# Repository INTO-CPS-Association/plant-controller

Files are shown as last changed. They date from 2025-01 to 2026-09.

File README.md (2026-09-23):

# Plant Controllers

This is a project to develop edge controller and digital twin for plants.
The long-term goal is to realise the vision illustrated in the figure.

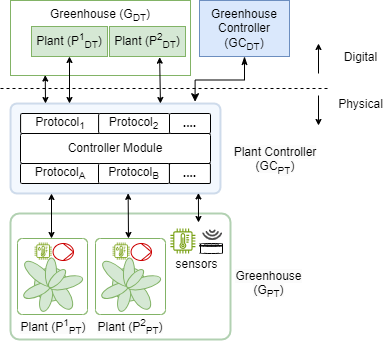
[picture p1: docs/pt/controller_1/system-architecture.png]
system architecture


The current version allows for digital twin development for specifically the
connected plants.

Documentation for current and previous versions of the Plant Controller can be
found online [Here](https://into-cps-association.github.io/plant-controller/).

## :rocket: Install and Use

To get up an running follow the [Quick Start Guide](https://into-cps-association.github.io/plant-controller/pt/controller_3/setup/quick_start/).

## :hammer_and_wrench: Developers

Detailed documentation of the system can be found [here](https://into-cps-association.github.io/plant-controller/pt/controller_3/documentation/).

To build the documentation locally install python and the requirements in [`requirements-docs.txt`](./requirements-docs.txt), then run
```bash
python ./scripts/gen_api_pages.py
zensical serve
```
The docummentation should then be available at [http://localhost:8000](http://localhost:8000).

Your feedback is valuable in improving the project. Please open
[an issue](https://github.com/INTO-CPS-Association/plant-controller/issues/new)
if you find problems or have suggestions for potential improvements. Thanks.

## :balance_scale: License

This software is owned by
[The INTO-CPS Association](https://into-cps.org/)
and is available under [the INTO-CPS License](./LICENSE.md).

Please see [third-party](docs/third-party.md) for details of
the third-party software included in the DTaaS.

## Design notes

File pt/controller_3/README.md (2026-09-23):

# Plant Controller Version 3
This version of the Plant Controller allows sensor conenctions with both I2C 
and MODBUS RTU.

The [sensors](./plant_controller/sensors) and [pump_schedules](./plant_controller/pump_schedules)
modules are extendable, allowing for additional sensor types and
configurations, and customziable watering schedules.

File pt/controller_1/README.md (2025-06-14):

# Plant Controller - I

Please see the [SCHEMATICS](SCHEMATICS.md) to get an overview of
the electrical and physical layout of the plant controller system.

## Initial Setup

Enable I2C interface in RPi OS configuration.

```bash
sudo raspi-config nonint do_i2c 0
```

You can check the list of I2C devices connected to a RPi using

```bash
sudo apt-get install i2c-tools
i2cdetect -y 1
```

## Configuration

The controller is configured using the `config.yaml` file. A template is provided in config/config.yaml.template.
You can copy it to `config/config.yaml` and edit it according to your setup.

The configuration file contains the following sections:

- Services: containing influxdb and STOMP services.
- Plant: containing sensors and actuators.

### Configuration Details

The `config.yaml.template` file contains the following structure:

```yaml
services:
  internal:
    influxdb:               # InfluxDB configuration for storing sensor data
      bucket: "controller-1"
      token: "xxxx"         # Your InfluxDB access token
      url: "https://influxdb.example.com"
      org: "plants"
  external:
    stomp:                  # STOMP message broker configuration
      url: "localhost.com"
      user: "admin"
      pass: "admin"
      port: "1234"
      topics:               # Map of STOMP topics to pump IDs
          "actuator.1.water": pump_1
          "actuator.2.water": pump_2
          "actuator.3.water": pump_3

plant:
  sensors:
    seesaw:                 # Adafruit Seesaw soil moisture sensors
      moisture_0:           # First moisture sensor
        port: 0             # TCA9548A multiplexer port
        addr: 0x36          # I2C address
      moisture_1:           # Second moisture sensor
        port: 1
        addr: 0x36
      moisture_2:           # Third moisture sensor
        port: 2
        addr: 0x36
    sht45:                  # Temperature & humidity sensor
      port: 6               # TCA9548A multiplexer port
      mode: NOHEAT_HIGHPRECISION  # Sensor operation mode
    as7341:                 # Light spectrum sensor
      port: 7               # TCA9548A multiplexer port
    sampling_period: 60     # Sensor reading interval in seconds
    
  actuators:
    pump_1:                 # First water pump
      relay: one            # Relay name on the Automation HAT
      schedule: "10:15"     # Daily watering time (HH:MM)
      on_duration: 15       #pump turn on time
    pump_2:                 # Second water pump
      relay: two
      schedule: "14:30"
      on_duration: 6        #pump turn on time
    pump_3:                 # Third water pump
      relay: three
      schedule: "10:15"
      on_duration: 10       #pump turn on time
```

### Configuration Sections

1. **Services**
   - **internal/influxdb**: Configuration for InfluxDB time series database.
   - **external/stomp**: Configuration for STOMP message broker to receive remote commands.

2. **Plant**
   - **sensors**: Configuration for all connected sensors.
     - **seesaw**: Soil moisture sensors.
     - **sht45**: Temperature and humidity sensor.
     - **as7341**: Light spectrum sensor.
     - **sampling_period**: How often sensors are read (in seconds).
   - **actuators**: Configuration for water pumps.
     - Each pump has a relay name and watering schedule.

### Note

- The I2C addresses must match your physical hardware configuration.
- Valid relay names are "one", "two", and "three" as defined by the Automation HAT.
- Relay names must match the actual relay that the pump is connected to.
- A sensor's port corresponds to the TCA9548A multiplexer port it is connected to.

## Run

Please execute the following commands to start the controller.

```sh
pip install -r requirements.txt
python controller-1.py
```

## Note

1. Accessing the I2C bus in parallel in two programs leads to errors.
   Use multiplexer for such a purpose.
1. The I2C bus communication may not be very robust.
   The sensors produce errors sometimes in an hour and sometimes in
   a day. So python exception checking is required.

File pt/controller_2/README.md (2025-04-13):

# Greenhouse - III

## Physical Setup

This greehouse uses SenseHAT for temperature, humidity and light
readings.
It uses [Waveshare 3-Channel Relay HAT](WAVESHARE_RELAY.md)
for controlling motors.

The physical twin schematic for the green house is

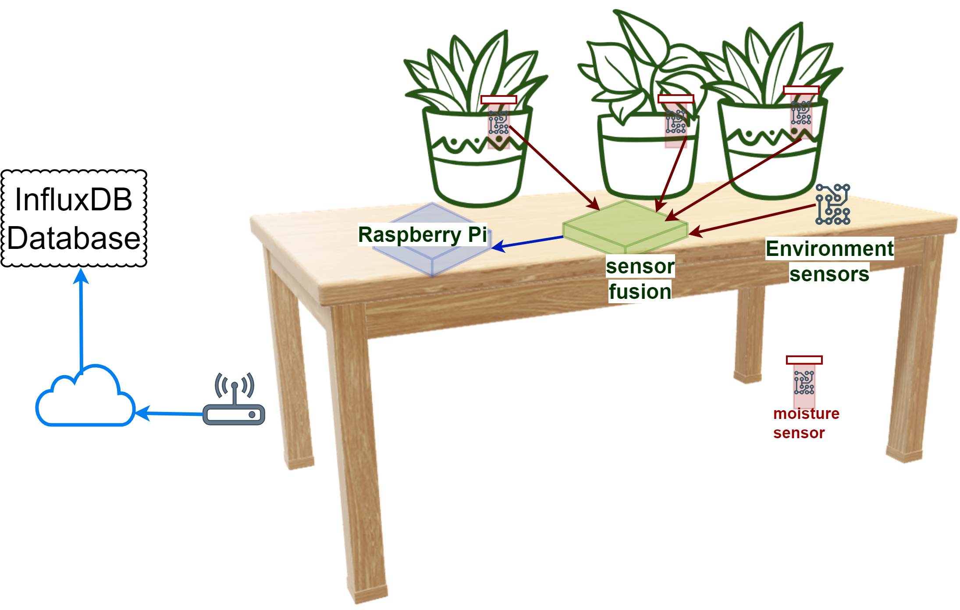
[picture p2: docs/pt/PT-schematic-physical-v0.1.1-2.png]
physical schematic


Only two plants are being used right now.

## Hardware Connections

The matching electrical schematic is:

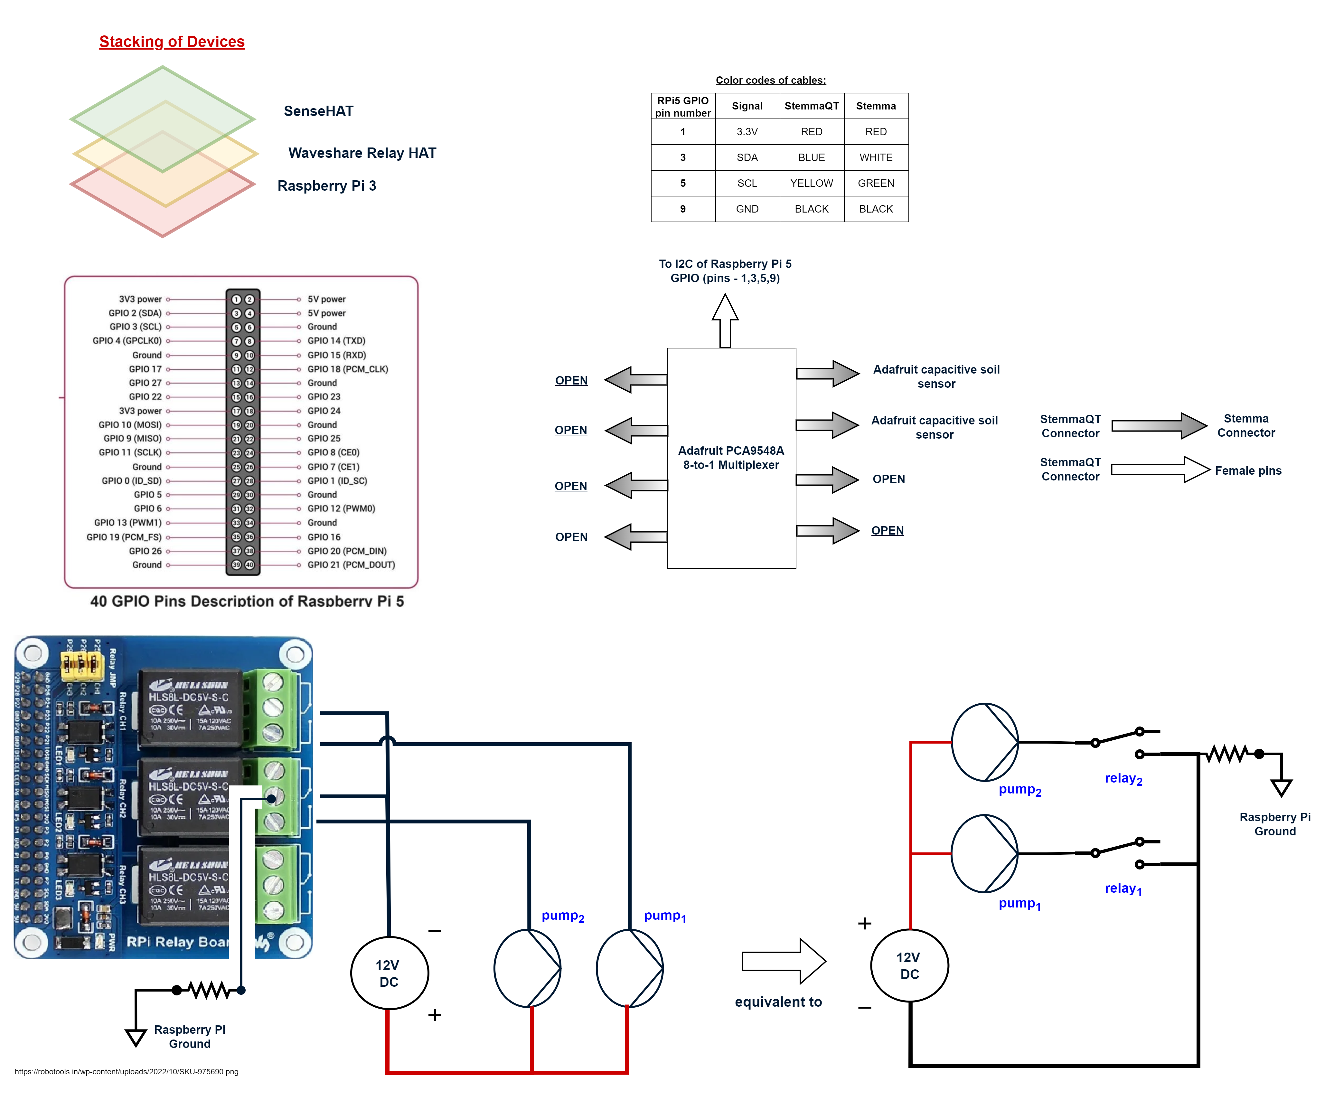
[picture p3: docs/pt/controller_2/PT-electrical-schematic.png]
electrical


The approach taken here is to use Raspberry Pi senseHAT for environment
readings and use Adafruit stemma soil sensors for moisture readings.

All the sensors selected use [I2C communication protocol](https://www.nxp.com/docs/en/user-guide/UM10204.pdf). Even the senseHAT uses I2C communication protocol underneath.
However, I2C is a bus protocol. So the Adafruit
[PCA9548A multiplexer](https://learn.adafruit.com/adafruit-pca9548-8-channel-stemma-qt-qwiic-i2c-multiplexer)
setup is used to connect
two soil moisture sensors to Raspberry Pi.

It is useful to be familiar with the RPi [GPIO pins](https://pinout.xyz/).
The I2C pins of RPi are.

| Pin No | Pin Name | Suggested Wire Color |
|:---|:---|:---|
| 1 | 3.3 | RED |
| 2 or 4 | 5V | RED |
| 3 | SDA | BLUE |
| 5 | SCL | YELLOW |
| 6 or 9 | GND | BLACK |

The multiplexer can work with both 3.3V and 5V.
The Multiplexer is available at **I2C address x70** and it has 8 ports.

Enable i2c interface in RPi OS configuration.

```bash
sudo raspi-config nonint do_i2c 0
```

You can check the list of I2C devices connected to a RPi using

```bash
sudo apt-get install i2c-tools
i2cdetect -y 1
```

The two Adafruit soil capacitive sensors are connected to the multiplexer.

Sometimes the soil moisture sensors seem faulty, but they work if
they are cleaned and reconnected.

The I2C addresses of the sensors used are:

| I2C Address | Device | Purpose | Multiplexer Ports | Notes |
|:---|:---|:---|:---|:---|
| 0x36 to 0x39 (with 0x36 as default) | capacitive soil sensor | measure soil moisture | ports 6 to 7 | the default addresses have not been modified |
| 0x5F | senseHAT (HTS221) | temperature and humidity sensor | | |
| 0x29 | senseHAT (TCS34725) | light sensor | | |
| 0x1C | senseHAT (LSM9DS1) | accelerometer | | |
| 0x6A | senseHAT (LSM9DS1) | accelerometer | | |
| 0x5C | senseHAT (LPS25H) | pressure sensor | | |
| 0x70 to 0x77 (with x070 as default) | PCA9548 | 8-TO-1 multiplexer | directly connected to I2C port of Raspberry Pi 3 | the default address has not been modified |

**missing I2C device:** x46 for senseHAT (LED2472G)

See [I2C address directory](https://learn.adafruit.com/i2c-addresses/the-list)

### Note

1. Accessing the I2C bus in parallel in two programs leads to errors. Use multiplexer for such a purpose.
1. The I2C bus communication may not be very robust.
   The sensors produce errors sometimes in an hour and sometimes in a day. So python exception checking is required.

## Run Controller

The programs store readings in InfluxDB database.

```bash
sudo apt-get install sense-hat
python -m venv .venv-sensehat
#update the venv config to include system-wide-packages, see
#https://stackoverflow.com/questions/55600132/installing-local-packages-with-python-virtualenv-system-site-packages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
#in file vi .venv-sensehat/pyvenv.cfg
# include-system-site-packages = true
source .venv-sensehat/bin/activate
pip install influxdb_client
python sensehat.py
```

In another terminal, run controller script  for collecting
moisture readings and controlling the motors.
The moisture readings and motor status are stored in InfluxDB database.

```bash
python -m venv .venv-controller
source .venv-controller/bin/activate
pip install -r requirements.controller.txt
python controller-2.py
```

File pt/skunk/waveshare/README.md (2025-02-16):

# Relays for Greenhouses

The GPIO pin layout has changed in
[RPi 5](https://www.sunfounder.com/blogs/news/comprehensive-guide-to-the-pin-diagram-of-raspberry-pi-5-understanding-gpio-pins-and-their-functions).
Only
[gpiozero](https://gpiozero.readthedocs.io/en/stable/recipes.html) package.
works correctly with RPi 5.

## Waveshare 3-Relay HAT

The GPIO pins for the three-relays are:

* channel_1 = GPIO26
* channel_2 = GPIO20
* channel_3 = GPIO21

Remember, the channels to the relays are active low which means

* ON - turns off the output
* OFF - turns on the output

The board works correctly but the software is outdated.
The [provided software](https://www.waveshare.com/wiki/RPi_Relay_Board)
only works upto RPi 4.
This outdated software uses
[gpiod library](https://www.acmesystems.it/libgpiod)
which doesn't work for RPi 5.

However, we can use python gpiozero pip package to use the board

Install gpiozero at the system level (don't use venv).
$sudo apt install python3-gpiozero
This installs gpiozero==2.0.1 in the system site packages

However, this
package seems to work in venv as well. Check it.

### TODO

At the moment LEDs are being used to control the channels but
LEDs draw a lot of current. Is there a low-power way to
activate the channels?

## References

* [RPi 5 pinout guide](https://www.twicea.com/blog/learn-raspberry-pi-5-pinout-in-this-in-depth-comprehensive-guide)

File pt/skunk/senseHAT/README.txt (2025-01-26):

Steps to install SenseHAT

Add at the end of /boot/firmware/config.txt

#dtoverlay=w1-gpio
dtoverlay=rpi-sense
dtparam=i2c1_baudrate=400000

-------
Installation notes:
---
sense-hat installation issues:
sudo apt install -y python3-sense-hat (works but not "pip install sense-hat" inside virt env)
If installed in virt env, it gives RTIMU moduleerror in python code

Run all senseHAT code outside python virt env.

Plotting
---

Plotting is slow because all the axis is being redrawn frequently.
Instead only update y-axis data.

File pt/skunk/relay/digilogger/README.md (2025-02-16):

# Relays for Greenhouses

The GPIO pin layout has changed in
[RPi 5](https://www.sunfounder.com/blogs/news/comprehensive-guide-to-the-pin-diagram-of-raspberry-pi-5-understanding-gpio-pins-and-their-functions).
Only
[gpiozero](https://gpiozero.readthedocs.io/en/stable/recipes.html) package.
works correctly with RPi 5.

## Digitlogger IoT Relay

This works really well without any static leakage problems, but has
only one effective relay. For the controlling the relay, we are using
one control signal. The control signal is connected to RPi 5 as follows.

* Pin-43: ground
* pin-36: control signal to IoT Relay

One channel can control all the motors.
It takes more current to drive all channels.

### TODO

At the moment LEDs are being used to control the channels but
LEDs draw a lot of current. Is there a low-power way to
activate the channels?

## References

* [RPi 5 pinout guide](https://www.twicea.com/blog/learn-raspberry-pi-5-pinout-in-this-in-depth-comprehensive-guide)

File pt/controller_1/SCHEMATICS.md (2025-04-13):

# Plant Controller - I

The physical twin schematic for the plant controller and plants is

physical schematic

Only three plants are being used right now.

The matching electrical schematic is:

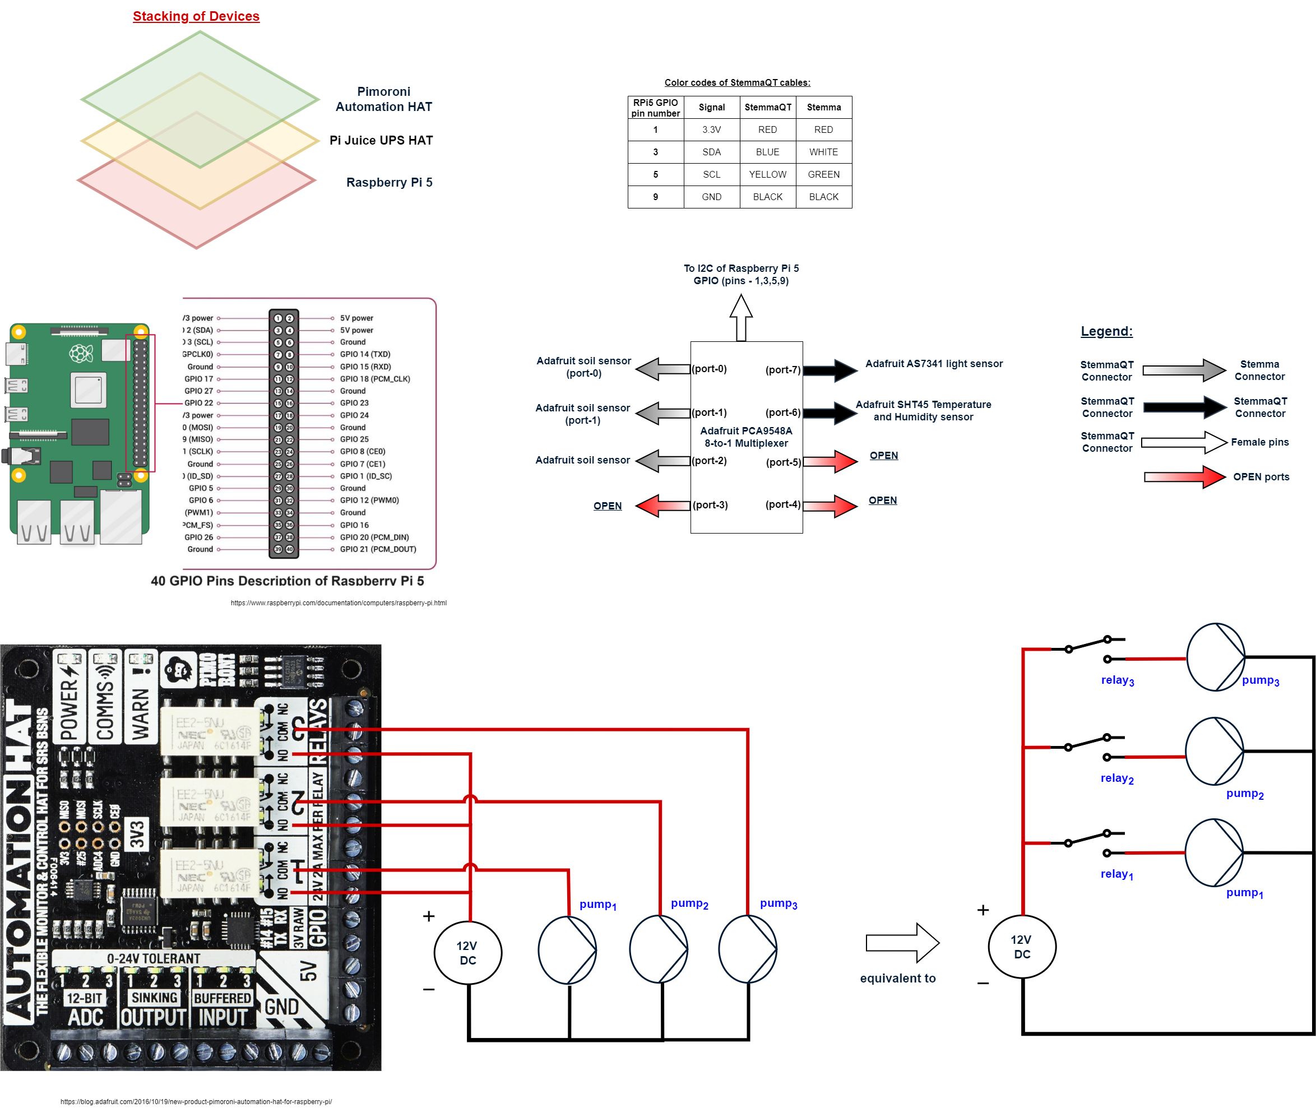
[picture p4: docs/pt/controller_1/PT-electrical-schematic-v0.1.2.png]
electrical


The approach taken here is to use one good sensor for
each physical variable measurement.
All the sensors selected use
[I2C communication protocol](https://www.nxp.com/docs/en/user-guide/UM10204.pdf).

There is only one I2C port on GPIO of Raspberry Pi 5. An Adafruit
[PCA9548A multiplexer](https://learn.adafruit.com/adafruit-pca9548-8-channel-stemma-qt-qwiic-i2c-multiplexer)
setup is used to connect multiple I2C sensors to
the Raspberry Pi (RPi) 5 / 3 Model B+.

It is useful to be familiar with the RPi [GPIO pins](https://pinout.xyz/).
The I2C pins of Raspberry Pi are.

| Pin No | Pin Name | Suggested Wire Color |
| :----- | :--- | :--- |
| 1 | 3.3 | RED |
| 2 or 4 | 5V | RED |
| 3 | SDA | BLUE |
| 5 | SCL | YELLOW |
| 6 or 9 | GND | BLACK |

The multiplexer can work with both 3.3V and 5V.
The Multiplexer is available at **I2C address x70** and it has 8 ports.

The three Adafruit soil capacitive sensors, temperature and humidity
sensor (Adafruit SHT45) and light sensor (Adafruit AS7341) are connected
to the multiplexer.

:warning: Sometimes the soil moisture sensors seem faulty, but
they work if they are cleaned and reconnected.

The I2C addresses of the sensors used are:

| I2C Address | Device | Purpose | Multiplexer Ports | Notes |
|:---|:---|:---|:---|:---|
| 0x36 to 0x39 (with 0x36 as default) | capacitive soil sensor | measure soil moisture | ports 0 to 2 | the default addresses have not been modified |
| 0x44 | SHT45 | temperature and humidity sensor | 6 | |
| 0x39 | AS7341 | 6-channel 16-bit light sensor | 7 | this measures light in seven wavelengths |
| 0x70 to 0x77 (with x070 as default) | PCA9548 | 8-TO-1 multiplexer | directly connected to I2C port of Raspberry Pi | the default address has not been modified |

See [I2C address directory](https://learn.adafruit.com/i2c-addresses/the-list)

 The sensors are connected to Adafruit
PCA9548A (8-ch multiplexer) as follows:

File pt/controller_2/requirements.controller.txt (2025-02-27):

Adafruit-Blinka==8.54.0
adafruit-circuitpython-busdevice==5.2.11
adafruit-circuitpython-connectionmanager==3.1.3
adafruit-circuitpython-pixelbuf==2.0.7
adafruit-circuitpython-requests==4.1.9
adafruit-circuitpython-seesaw==1.16.5
adafruit-circuitpython-tca9548a==0.8.0
adafruit-circuitpython-typing==1.11.2
Adafruit-PlatformDetect==3.77.0
Adafruit-PureIO==1.1.11
binho-host-adapter==0.1.6
certifi==2025.1.31
colorzero==2.0
gpiozero==2.0.1
influxdb_client==1.48.0
lgpio==0.2.2.0
pyftdi==0.56.0
pyserial==3.5
python-dateutil==2.9.0.post0
pyusb==1.3.1
reactivex==4.0.4
rpi-ws281x==5.0.0
RPi.GPIO==0.7.1
schedule==1.2.2
six==1.17.0
sysv-ipc==1.1.0
typing_extensions==4.12.2
urllib3==2.3.0

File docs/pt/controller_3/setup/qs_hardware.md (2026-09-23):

# Assemble the hardware
[Installing the software](qs_software.md) in the next chapter will come with some waiting time — during these times it
is possible to assemble hardware not directly connected to the Raspberry Pi.

## Connect the air sensors to the Raspberry Pi

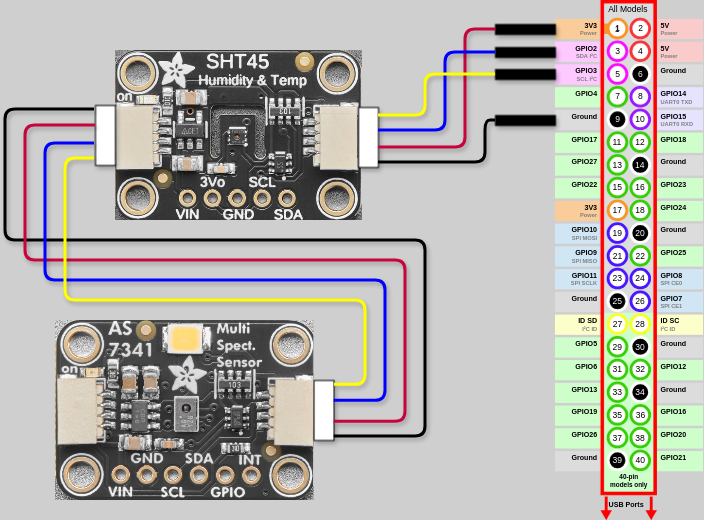
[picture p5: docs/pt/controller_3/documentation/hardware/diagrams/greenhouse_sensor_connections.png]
Wiring diagram for the greenhouse sensors and the Raspberry Pi


Using the [STEMMA QT cable](../documentation/hardware/components/qt_cable.md),
connect the
[Adafruit AS7341 light sensor](../documentation/hardware/components/ada_as7341.md)
to the
[Adafruit SHT45 air temperature and humidity sensor](../documentation/hardware/components/ada_sht45.md).
It doesn't matter which of the two ports on the sensors are used.

Then, connect the
[STEMMA QT to JST SH 4-pin cable](../documentation/hardware/components/qt_to_jst.md)
to the final port on the
[Adafruit SHT45](../documentation/hardware/components/ada_sht45.md).

!!! warning "Power off first"
    Make sure the Raspberry Pi 5 is **POWERED OFF** before connecting anything
    to the GPIO header.

Connect the 4 JST pins of the
[STEMMA QT to JST SH 4-pin cable](../documentation/hardware/components/qt_to_jst.md)
to the Raspberry Pi's GPIO pins
([pin layout](../documentation/hardware/components/rpi5.md)), depending on
their color:

| GPIO Pin | Wire color |
|---:|---|
| Pin 1 | Red |
| Pin 3 | Blue |
| Pin 5 | Yellow |
| Pin 9 | Black |

## Create the RS485 bus

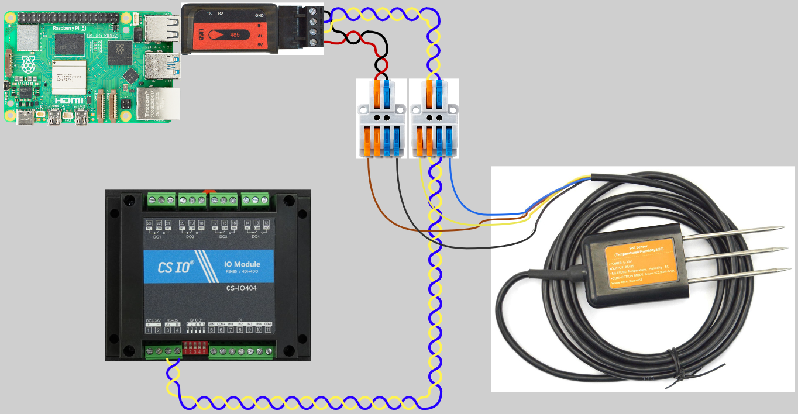
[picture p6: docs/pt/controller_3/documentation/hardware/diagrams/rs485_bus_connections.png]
Wiring diagram for the RS485 bus and connected hardware


Both the DF-Robot soil sensor and the CS-IO404 relay connect to the Raspberry
Pi via an RS485 bus wire pair. This bus wire pair is the primary way to connect
reliable peripherals to the plant controller.

Measure out how far away you want the relay from the Raspberry Pi, taking into
account that the 12V DC for the pump and relay must be connected near the
relay, and that the pump will be getting its power from the relay. Take this
length and multiply it by 1.5 for some slack — this will be the length of the
RS485 bus. As a minimum though, it should be at least 50 cm.

Take two lengths of insulated wire, one blue, the other yellow, cutting each
to be the length of the bus. Then, twist them together, tightly. (A cordless
drill is handy for this.)

Then, take two more lengths of insulated wire, one red, one black, cutting
them to be about 20 cm. Also twist these together, tightly.

Now, strip one end of each of the four wires, about 11 mm.

Connect these stripped wires to the
[USB to RS485 module](../documentation/hardware/components/usb_to_rs485.md),
dependent on color:

| Terminal | Wire color |
|---|---|
| GND | Black |
| B- | Blue |
| A+ | Yellow |
| 5V | Red |

With both twisted pairs connected to the USB to RS485 module, lay them out
side by side, and cut the yellow and blue pair so it is as long as the red and
black pair. Put the remaining yellow and blue pair aside for later.

Strip the other ends of each of the four wires, again about 11 mm.

Take two
[2 pole, 2-to-4 lever wire connectors](../documentation/hardware/components/lever_connector.md).

Connect the yellow and blue wires to the 2-connection side of the first
connector, blue to blue, yellow to orange.

Connect the red and black wires to the 2-connection side of the second
connector, black to blue, red to orange.

Now, take the
[DF-Robot soil sensor](../documentation/hardware/components/dfr_soil_sensor.md).
Connect it to the outer connectors of the 4-connector sides of the two lever
wire connectors, depending on the sensor's connector wires:

| Sensor wire | Connector | Slot |
|---|---|---|
| Blue | First | Blue |
| Yellow | First | Orange |
| Black | Second | Blue |
| Red | Second | Orange |

With the soil sensor connected, strip both ends of the remaining yellow and
blue wire pair that was previously set aside, again about 11 mm.

Connect one end to the remaining connections on the first lever wire connector,
blue to blue, yellow to orange.

Connect the other end to the
[CS-IO404 4-channel relay module](../documentation/hardware/components/cs-io404.md),
yellow to the terminal labelled A+, blue to the terminal labelled B-.

Finally, plug the USB end of the
[USB to RS485 module](../documentation/hardware/components/usb_to_rs485.md)
into one of the Raspberry Pi's USB ports.

!!! note
    If the total length of the RS485 bus line exceeds 200 meters or you are
    otherwise experiencing reading errors from RS485 connected sensors it
    might be necessary to terminate the lines with 120 Ohm resistors. To do
    this, simply connect two [120 Ohm resistors](../documentation/hardware/components/term_resistor.md)
    to each end of the line - one between the A+ and B- terminals on the
    [USB to RS485 module](../documentation/hardware/components/usb_to_rs485.md)
    and on between the A+ and B- terminals on the 
    [CS-IO404 4-channel relay module](../documentation/hardware/components/cs-io404.md).

## Set the MODBUS address of the CS-IO404 relay

All devices connected over RS485 MODBUS have an address or device id that
identifies them. Usually, this is set to 1 as a factory default and must be
changed during setup to avoid addressing conflicts between devices.

To change the address of the CS-IO404 relay, use the dipswitches on the front.
These add to the address, dependent on their position — flipping the first
switch on adds 1, flipping the second adds 2, flipping the third adds 4,
flipping the fourth adds 8 and flipping the fifth adds 16.

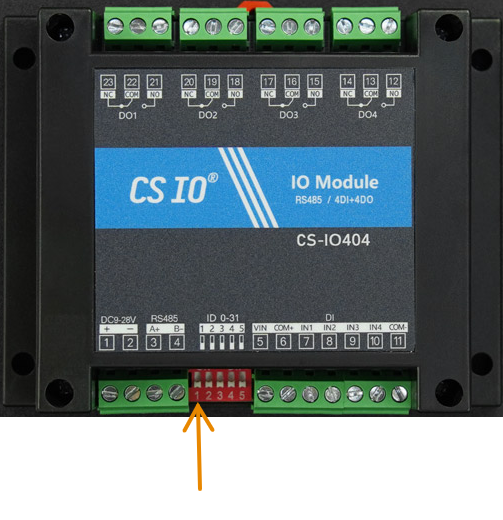
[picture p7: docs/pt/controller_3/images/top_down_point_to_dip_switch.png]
Location of first address switch on the CS-IO404


Flip the first switch (indicated in the image above) up to the "on" position. This will result in a MODBUS address
of "2" for the CS-IO404.

## Wire up the pump relay

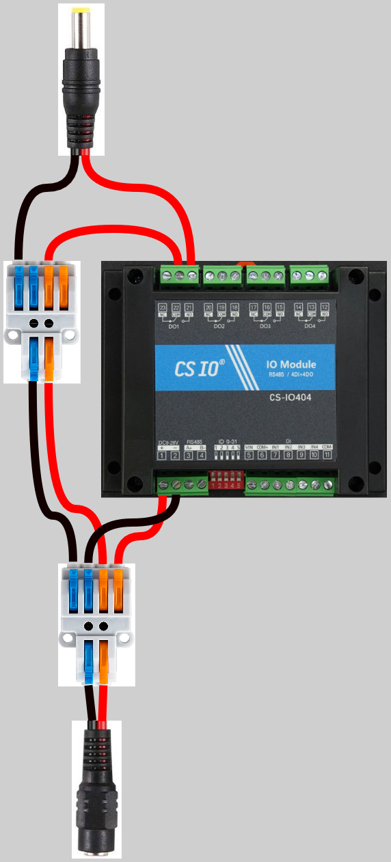
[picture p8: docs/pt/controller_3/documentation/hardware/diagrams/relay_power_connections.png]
Wiring diagram for the pump relay


Take the
[5.5/2.1 mm barrel socket](../documentation/hardware/components/barrel_socket.md)
and strip 11 mm off of the ends of the leads of the attached wires.

Connect these ends to the 2 connector side of a
[2 pole, 2-to-4 lever wire connector](../documentation/hardware/components/lever_connector.md),
black to blue and red to orange.

Cut two short lengths of red and black wire, no more than 10 cm, and strip
11 mm off of each end of each wire. Connect one end of each wire to the 4
connector side of the lever wire connector, again black to blue and red to
orange. Connect the other ends of the wires to the power terminals of the
CS-IO404 relay, black to "-" and red to "+".

Cut a length of red and a length of black wire long enough that it reaches from
the lever wire connector to about 4 cm beyond the opposite side of where the
power terminals are on the CS-IO404 relay. Strip these wires in both ends,
11 mm, and connect one end of each wire to the last two connectors of the lever
wire connector, again black to blue and red to orange.

Now take a new second 2 pole, 2-to-4 lever wire connector. Connect the other
ends of the red and black wires to the 2 connector side, black to blue, red to
orange.

Take a short length of red wire, strip the ends, and connect it between one of
the orange connectors on the 4 connector side and the COM terminal of relay DO1
on the CS-IO404 (also denoted as port 22).

Finally, strip 11 mm off of the ends of the wires of a
[5.5/2.1 mm barrel plug with 1 m leads](../documentation/hardware/components/barrel_plug.md),
connect the red wire to the NO terminal of relay DO1 on the CS-IO404 (also
denoted as port 21), and connect the black wire to the 4 connector side of the
lever wire connector, black to blue.

Power is supplied to the CS-IO404 and the pump by connecting the
[12V 1A power supply with 5.5/2.1 mm barrel plug connector](../documentation/hardware/components/12v_1a_psu.md)
to the barrel socket.

## Connect the pump

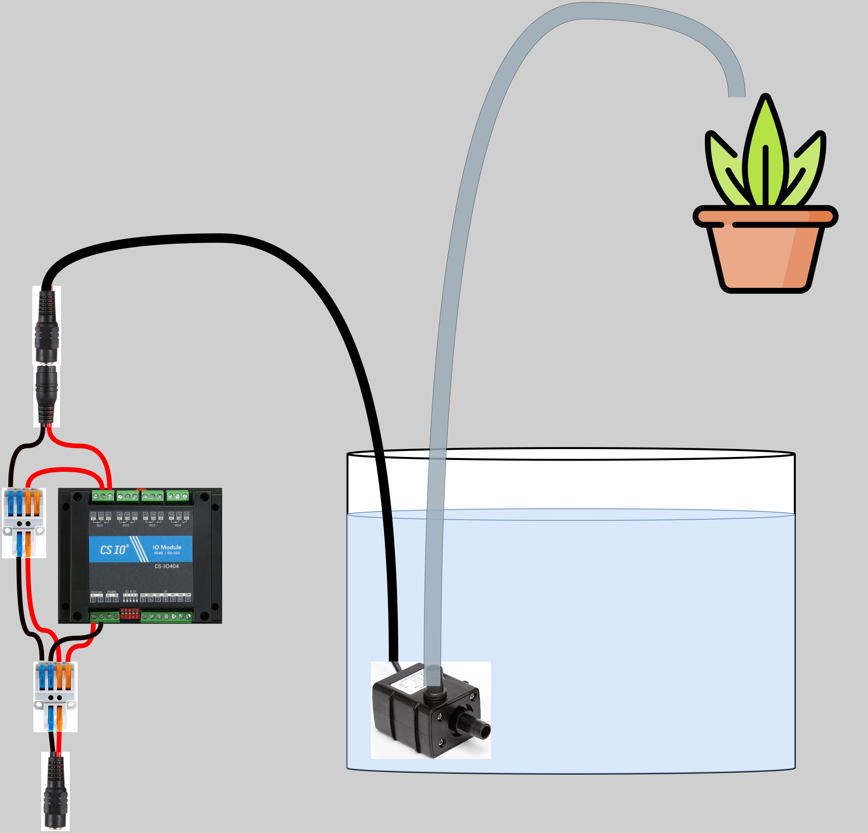
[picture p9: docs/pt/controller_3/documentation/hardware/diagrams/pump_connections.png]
How to connect the pump to relay and water tank.


The
[AD20P-1230E submersible pump](../documentation/hardware/components/ad20p-1230e_pump.md)
used for watering the connected plant is meant to be submersed in the system's
water tank. This system assumes that the water tank and pump inlet is placed at
a lower elevation than the plant, for example under the table that the plant is
located on.

Place the watering tank in its final location with respect to the plant.

Measure the distance from the bottom of the tank to the plant, and add some
extra slack. Cut some
[PVC tubing](../documentation/hardware/components/pvc_tubing.md) to this
length.

Attach one end of the tubing to the outlet of the pump.

Fix the other end of the tubing above the soil of the connected plant (physical
details of how are left as an exercise for the reader).

Connect the power socket of the pump to the barrel plug coming off of the
CS-IO404 relay.

Finally, lower the pump into the tank and fill the tank with water.

---

[**Install the software**](./qs_software.md)

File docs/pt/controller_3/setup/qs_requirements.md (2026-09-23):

# Requirements

You'll need an internet connection, and a trusted LAN that you can connect
both the controller and your extra installation computer to.

## Hardware

| Qty | Component |
|----:|---|
| 1 | [Raspberry Pi 5, at least 4 GB RAM](../documentation/hardware/components/rpi5.md) |
| 1 | [Raspberry Pi USB-C power supply](../documentation/hardware/components/rpipsu.md) |
| 1 | [Micro SD card, at least 128 GB](../documentation/hardware/components/sdcard.md) |
| 1 | [Adafruit AS7341 light sensor](../documentation/hardware/components/ada_as7341.md) |
| 1 | [Adafruit SHT45 air temperature and humidity sensor](../documentation/hardware/components/ada_sht45.md) |
| 1 | [DF-Robot soil sensor](../documentation/hardware/components/dfr_soil_sensor.md) |
| 1 | [CS-IO404 4-channel relay module](../documentation/hardware/components/cs-io404.md) |
| 1 | [USB to RS485 module](../documentation/hardware/components/usb_to_rs485.md) |
| 1 | [12V 1A power supply with 5.5/2.1 mm barrel plug connector](../documentation/hardware/components/12v_1a_psu.md) |
| 1 | [AD20P-1230E submersible pump](../documentation/hardware/components/ad20p-1230e_pump.md) |
| 1 | [5.5/2.1 mm barrel plug with 1 m leads](../documentation/hardware/components/barrel_plug.md) |
| 1 | [5.5/2.1 mm barrel socket with 1 m leads](../documentation/hardware/components/barrel_socket.md) |
| 2 | (Optional) [120 Ohm resistors](../documentation/hardware/components/term_resistor.md) |
| 1 | [STEMMA QT cable](../documentation/hardware/components/qt_cable.md) |
| 1 | [STEMMA QT to JST SH 4-pin cable](../documentation/hardware/components/qt_to_jst.md) |
| 4 | Insulated wire, each a different color (this guide uses red, black, blue and yellow), length dependent on setup |
| 4 | [2 pole, 2-to-4 lever wire connectors](../documentation/hardware/components/lever_connector.md), or similar |
| 1 | [PVC tubing, length dependent on setup](../documentation/hardware/components/pvc_tubing.md) |
| 1 | [Water reservoir, for holding water for watering](../documentation/hardware/components/water_tank.md) |

## Software

- The Raspberry Pi Imager, available from [Raspberry Pi's website](https://www.raspberrypi.com/software/)

## Tools

- One extra computer for setup and testing, able to run the Raspberry Pi
  Imager, and preferably a browser and some way to run SSH. This guide assumes
  that the extra computer is running a Linux OS.
- A way to connect a micro SD card to the above computer, either via USB
  dongle or directly in a port on the computer.
- A small flat head screwdriver.
- A pair of cutters for cutting and stripping wire.
- A container capable of holding at least a liter of water.
- A measuring cup or similar, able to measure water in milliliters in at least
  10 ml increments.
- (Optionally, a screen and keyboard able to be connected to the Raspberry Pi.
  Unless you have complete trust and control over your LAN, this is advised.)
- (Optionally, a cordless drill for twisting wire.)

---

[**Assmeble the hardware**](./qs_hardware.md)

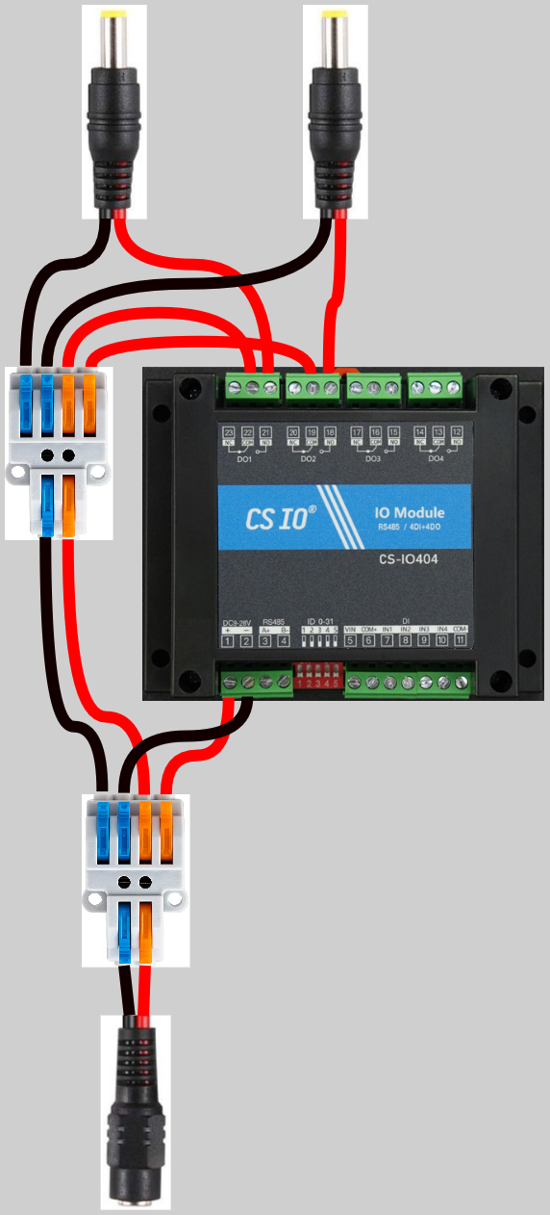
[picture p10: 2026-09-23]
docs/pt/controller_3/documentation/hardware/diagrams/relay_power_extension_connections.png

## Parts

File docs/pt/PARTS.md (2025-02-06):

# Parts for Physical Twin

## Computer

* Rapberry Pi 5 - 1 item
* RPi official 7 in touch screen - 1 item
* 128 GB memory cad - 1 item
* RPi 5 Power Supply - 1 item
* KKSB touch screen case for RPi - 1 item

## Sensors

* Temperature, Humidity and Light Sensors
  * Individual sensors with a multiplexer
    * Adafruit PCA9548 8-channel Stemma QT multiplexer - 1 item
    * Adafruit SHT45 temperature and humidity sensor - 1 item
    * Adafruit BH1750 light sensor - 1 item
* Adafruit Stemma 2.0 soil sensor - 4 items

## Actuators

* Water pumps
  * 12V submersible water pump of 500L/h capacity - 1 item per plant (correct choice)
  * AC Submersible Water Pump Fountain Pump of 500L/h capacity - 1 item per plant (overkill)
  * 5V submersible water pump - 1 item per small plant (but not enough lift)
* Pipes for submersible motors
* Relay
  * Digital Loggers IoT relay (robust choice)
  * Lab-made relay-controlled 4-outlet power extension
  * Waveshare RPi addon card with three relays

## Parts to be Selected

* Four outlet IoT relay - 1 item
* Raspberry Pi Camera Module 3 NOIR (no IR filter) camera

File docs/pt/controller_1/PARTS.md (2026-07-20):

# Parts for Physical Twin

This physical twin has three large plants.

## Summary of Parts

### Computer

* Rapberry Pi 5 / Raspberry Pi 3 Model B+ - 1 item
* 16 GB memory card - 1 item
* RPi 5 Power Supply - 1 item
* Pi Juice UPS HAT - 1 item

### Sensors

* Adafruit PCA9548 8-channel Stemma QT multiplexer - 1 item
* Adafruit SHT45 temperature and humidity sensor - 1 item
* Adafruit AS7341 light sensor - 1 item
* Adafruit Stemma 2.0 soil sensor - 1 item per plant

### Actuators

* 12V submersible water pump of 240L/h capacity - 1 item per plant
* Pipes for submersible water pumps
* Pimoroni Automation HAT - to control water pumps

### Other Parts

* Stemma QT cable kit
* Stemma to StemmaQT cables
* Water container

## Bill of Materials

Approximate cost of items as available on
[Raspberrypi, Denmark](https://raspberrypi.dk),
[Adafruit, USA](https://www.adafruit.com/),
[DigiKey, Denmark](https://digikey.dk),
[Mouser, Denmark](https://mouser.dk),
and
[Amazon, Germany](https://amazon.de)

| Item | Cost in DKK |
| :--- | :--- |
| Rapberry Pi 5 (RPi 5) | 740 |
| RPi 5 Power Supply | 120 |
| 128 GB memory card | 200 |
| Pi Juice UPS HAT (optional) | 550 |
| Adafruit PCA9548 8-channel Stemma QT multiplexer  | 50 |
| Adafruit SHT45 temperature and humidity sensor | 128 |
| Adafruit AS7341 light sensor | 114 |
| 3 x Adafruit Stemma 2.0 soil sensor | 160 |
| 3 x 12V submersible water pump of 240L/h capacity | 200 |
| Pipes for submersible water pumps | 200 |
| Pimoroni AutomationHAT | 247 |
| StemmaQT cable kit | 75 |
| 3 x Stemma to StemmaQT cables | 22 |
| Water Containers | 100 |
| Plants | 100 (flexible cost) |
| Total amount | 3,006 |

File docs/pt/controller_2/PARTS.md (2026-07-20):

# Parts for Physical Twin

This physical twin has two basil plants.

## Summary of Parts

### Computer

* Rapberry Pi 3 Model B+ - 1 item
* 16 GB memory card - 1 item
* RPi 5 Power Supply - 1 item

### Sensors

* Adafruit PCA9548 8-channel Stemma QT multiplexer - 1 item
* Raspberry Pi senseHAT - 1 item

### Actuators

* Waveshare 3-channel relay - 1 item
* 3 to 9V submersible water pump of 200L/h capacity - 1 item per plant
* Pipes for submersible water pumps

### Other Parts

* Stemma QT cable kit
* Stemma to StemmaQT cables
* Water containers

## Bill of Materials

Approximate cost of items as available on
[Raspberrypi, Denmark](https://raspberrypi.dk),
[Adafruit, USA](https://www.adafruit.com/),
[DigiKey, Denmark](https://digikey.dk),
[Mouser, Denmark](https://mouser.dk),
and
[Amazon, Germany](https://amazon.de)

| Item | Cost in DKK |
|:---|:---|
| Rapberry Pi 3, Model B+ | 330 |
| RPi 5 Power Supply | 120 |
| 128 GB memory card | 100 |
| senseHAT | 230 |
| Adafruit PCA9548 8-channel Stemma QT multiplexer | 50 |
| 2 x Adafruit Stemma 2.0 soil sensor | 60 |
| Waveshare 3-channel relay HAT | 130 |
| Pipes for submersible water pumps | 100 |
| 2 x 3 to 9V submersible water pump of 200L/h capacity | 50 |
| StemmaQT cable kit | 80 |
| 2 x Stemma to StemmaQT cables | 20 |
| Water Containers | 100 |
| Basil plants | 60 |
| Total amount | 1,430 |

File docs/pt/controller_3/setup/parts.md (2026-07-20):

# Parts

The parts for the controller are divided into two groups: the mandatory
**core controller**, and the **peripherals**. The core is everything needed to
connect one or more plants to the system, along with the sensors for the
greenhouse. Peripherals are the sensors and actuators connected per plant —
you'll need one pump and at least one soil sensor per plant you intend to
connect.

Wiring for the RS485 MODBUS bus, optional balancing resistors and terminal
blocks for connecting raw wires are not included in the lists below.

!!! note "Prices"
    Prices were collected in mid-2026 from the listed (mostly Danish/EU)
    vendors and converted to DKK at $1 = 6.44 DKK and €1 = 7.47 DKK. Expect
    them to have drifted, and substitute local vendors as convenient — apart
    from the specific sensor and relay modules, most parts are generic.

## Choosing peripherals

For soil sensing there are two supported options:

- **Adafruit STEMMA Soil Sensor** (I2C) — cheapest option, measures soil
  moisture only. All STEMMA soil sensors share the same I2C address, so
  connecting more than one requires a TCA9548A I2C multiplexer (one
  multiplexer serves up to 7 soil sensors, as one port is used for the bus).
  Getting the multiplexer is recommended even for a single sensor, as it also
  keeps the setup extendable with other I2C peripherals.
- **DFRobot RS485 Soil Sensor** (MODBUS) — measures soil temperature,
  moisture *and* electrical conductivity. More expensive, but the recommended
  choice for Digital Twin work, as it gives multiple sensed parameters per
  plant and the sensors sit on the shared RS485 bus without extra hardware.

For watering, each plant needs one **AD20P-1230E 12V submersible pump**,
switched by the CS-IO404 relay module in the core, plus PVC tubing from the
water tank to the plant.

The controller software is modular: other I2C or MODBUS sensors and pumps can
be used by writing a small driver module — see the
[Software API Reference](../../../api/plant_controller/index.md).

## Core controller

| Qty | Name | Description | Vendor | Unit Price | Cost (DKK) |
|-----|---|---|---|---|---|
| 1 | [Raspberry Pi 5 - 4GB](https://raspberrypi.dk/produkt/raspberry-pi-5-4-gb/) | Single board computer - core processing unit | RaspberryPi.dk | 909.00 DKK | 909.00 |
| 1 | [Raspberry Pi 27W USB-C PSU](https://raspberrypi.dk/produkt/raspberry-pi-stroemforsyning-usb-c-eu-5v-5a-hvid/) | Power supply for Raspberry Pi 5 | RaspberryPi.dk | 119.00 DKK | 119.00 |
| 1 | [SANDISK Ultra microSD - 128GB](https://www.proshop.dk/Hukommelseskort/SANDISK-Ultra-microSDSD-140MBs-128GB/3120859) | Removable persistent memory for the Raspberry Pi 5 | PROSHOP | 169.00 DKK | 169.00 |
| 1 | [Adafruit AS7341](https://www.adafruit.com/product/4698) | Light spectrum sensor for sensing greenhouse light | Adafruit | $18.95 | 122.04 |
| 1 | [Adafruit SHT45](https://www.adafruit.com/product/5665) | Air temperature and humidity sensor for sensing greenhouse environment | Adafruit | $12.50 | 80.50 |
| 1 | [CS-IO404](https://www.dfrobot.com/product-2349.html) | 4-channel relay module for pump actuation | DFRobot | $27.90 | 179.68 |
| 1 | [USB to RS485 Module](https://www.dfrobot.com/product-2189.html) | RS485 connection for the Raspberry Pi 5 | DFRobot | $8.50 | 54.74 |
| 1 | [12V/1A PSU](https://www.proshop.dk/Baerbar-Oplader/Deltaco-power-adapter/3370145) | Power supply for relay and water pumps | PROSHOP | 62.00 DKK | 62.00 |
| 1 | [STEMMA QT cable - 50mm](https://www.adafruit.com/product/4399) | I2C bus cable for daisy chaining greenhouse sensors | Adafruit | $0.95 | 6.12 |
| 1 | [STEMMA QT JST SH 4-pin cable](https://www.adafruit.com/product/4397) | I2C cable for connection to the Raspberry Pi 5's GPIO pins | Adafruit | $0.95 | 6.12 |
| 1 | [DC socket 5.5/2.1mm 1m](https://botland.store/dc-plugs/3507-dc-socket-5521mm-with-1-m-wire-5904422349295.html) | DC socket for connecting 12V PSU to CS-IO404 and pumps | BOTLAND | €1.50 | 11.21 |

Total: **1719.41 DKK**

## Peripherals (per plant)

### Pump

| Qty | Name | Description | Vendor | Unit Price | Cost (DKK) |
|-----|---|---|---|---|---|
| 1 | [AD20P-1230E](https://botland.store/pumps/14873-electric-liquid-pump-ad20p-1230e-12v-240lh-5904422342739.html) | Submersible 12V pump | BOTLAND | €10.90 | 81.42 |
| 1 | [DC plug 5.5/2.1mm 1.5m](https://botland.store/wires-and-power-connectors/1831-plug-dc-55-21mm-with-cable-15m-5904422356163.html) | DC plug for connecting pump to relay | BOTLAND | €0.90 | 6.72 |
| 1m* | [PVC tube, 5m x 8mm](https://www.biltema.dk/baad/vvs/slanger/pvc-slanger/pvc-slange-5-m-x-8-mm-2000060031) | PVC tubing for moving water | Biltema | 32.90 DKK | 6.58* |

*Assumes the pump must move the water 1 meter from water tank to plant. For
each 5 m of tubing needed across all pumps, a cost of 32.90 DKK is incurred.

Total, one pump: **121.04 DKK**
Total, three pumps, max 1.6 m pumping distance: **297.32 DKK**

### STEMMA Soil Moisture Sensor

| Qty | Name | Description | Vendor | Unit Price | Cost (DKK) |
|-----|---|---|---|---|---|
| 1 | [Adafruit STEMMA Soil Sensor](https://www.adafruit.com/product/4026) | Moisture sensor for plant soil | Adafruit | $7.50 | 48.30 |
| 1 | [Sparkfun Flexible Qwiic to STEMMA Cable - 500mm](https://opencircuit.dk/product/flexible-qwiic-to-stemma-cable-500mm) | Soil sensor connector | Opencircuit | €4.20 | 31.37 |
| (1) | [Adafruit PCA9548](https://www.adafruit.com/product/5626) | I2C multiplexer | Adafruit | $6.95 | (44.76) |
| (1) | [STEMMA QT cable - 50mm](https://www.adafruit.com/product/4399) | I2C bus connector to multiplexer | Adafruit | $0.95 | (6.12) |

The multiplexer (parenthesized) is necessary when connecting more than one
STEMMA soil sensor, and recommended in any case for extendability — one
multiplexer per 7 soil sensors.

Total, one sensor: **79.67 DKK**
Total, one sensor, extendable: **130.55 DKK**
Total, seven sensors: **608.57 DKK**

### RS485 Soil Temperature, Moisture, EC Sensor

| Qty | Name | Description | Vendor | Unit Price | Cost (DKK) |
|-----|---|---|---|---|---|
| 1 | [RS485 Soil Temperature, Moisture, EC Sensor](https://www.dfrobot.com/product-2817.html) | Multiparameter sensor for plant soil | DFRobot | $39.00 | 251.16 |

Total: **251.16 DKK**

## Example configurations

### Single plant, moisture only, unextendable

- Core controller: 1719.41 DKK
- 1x Pump: 121.04 DKK
- 1x STEMMA Soil Sensor: 79.67 DKK

Total: **1920.12 DKK**

### Single plant, moisture only

- Core controller: 1719.41 DKK
- 1x Pump: 121.04 DKK
- 1x STEMMA Soil Sensor, extendable: 130.55 DKK

Total: **1971 DKK**

### Single plant, multiple sensed parameters

*(Recommended minimal configuration)*

- Core controller: 1719.41 DKK
- 1x Pump: 121.04 DKK
- 1x RS485 Soil Sensor: 251.16 DKK

Total: **2091.61 DKK**

### Three plants, moisture only

- Core controller: 1719.41 DKK
- 3x Pump: 297.32 DKK
- 3x STEMMA Soil Sensor: 289.89 DKK

Total: **2306.62 DKK**

### Three plants, multiple sensed parameters

*(Recommended 3 plant configuration)*

- Core controller: 1719.41 DKK
- 3x Pump: 297.32 DKK
- 3x RS485 Soil Sensor: 753.48 DKK

Total: **2770.21 DKK**

---

Once the parts have arrived, continue to [Assembly](assembly.md).

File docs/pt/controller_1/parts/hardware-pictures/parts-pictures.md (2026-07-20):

# Images of hardware parts

## Table of Contents

- [Images of hardware parts](#images-of-hardware-parts)
  - [Table of Contents](#table-of-contents)
    - [Hardware parts](#hardware-parts)
      - [Raspberry Pi 3 B+](#raspberry-pi-3-b)
      - [Pimoroni AutomationHAT](#pimoroni-automationhat)
      - [12V submersible water pump of 240L/h capacity](#12v-submersible-water-pump-of-240lh-capacity)
      - [Stackeble T GPIO header](#stackeble-t-gpio-header)
      - [Adafruit Stemma 2.0 soil sensor](#adafruit-stemma-20-soil-sensor)
      - [Adafruit PCA9548 8-Channel STEMMA QT](#adafruit-pca9548-8-channel-stemma-qt)
      - [Adafruit SHT45 temperature and humidity sensor](#adafruit-sht45-temperature-and-humidity-sensor)
      - [2A 72W Adjustable Power Supply DC 3V ~ 36V](#2a-72w-adjustable-power-supply-dc-3v-36v)
      - [I2C Qwiic Cable Kit Stemma QT](#i2c-qwiic-cable-kit-stemma-qt)
      - [df 2 in 6 Out Lever, Compact Cable Connector](#df-2-in-6-out-lever-compact-cable-connector)
      - [18AWG DC 12V 5A 5.5 x 2.1 mm Male Female DC Power Pigtail Cable](#18awg-dc-12v-5a-55-x-21-mm-male-female-dc-power-pigtail-cable)
      - [M2.5 Nylon Screws Nuts Set, Black Nylon Spacer Screw Nuts phillips Scrw kit](#m25-nylon-screws-nuts-set-black-nylon-spacer-screw-nuts-phillips-scrw-kit)
  - [References](#references)

### Hardware parts

#### Raspberry Pi 3 B+

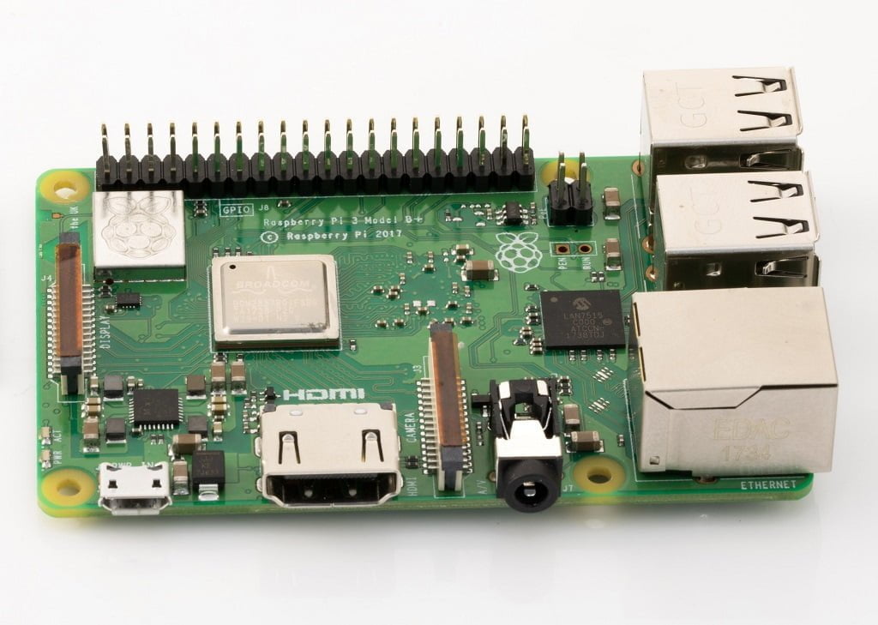
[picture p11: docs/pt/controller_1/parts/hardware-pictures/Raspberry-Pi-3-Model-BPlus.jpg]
Raspberry-Pi-3-Model-BPlus

[[1]](#references)

#### Pimoroni AutomationHAT

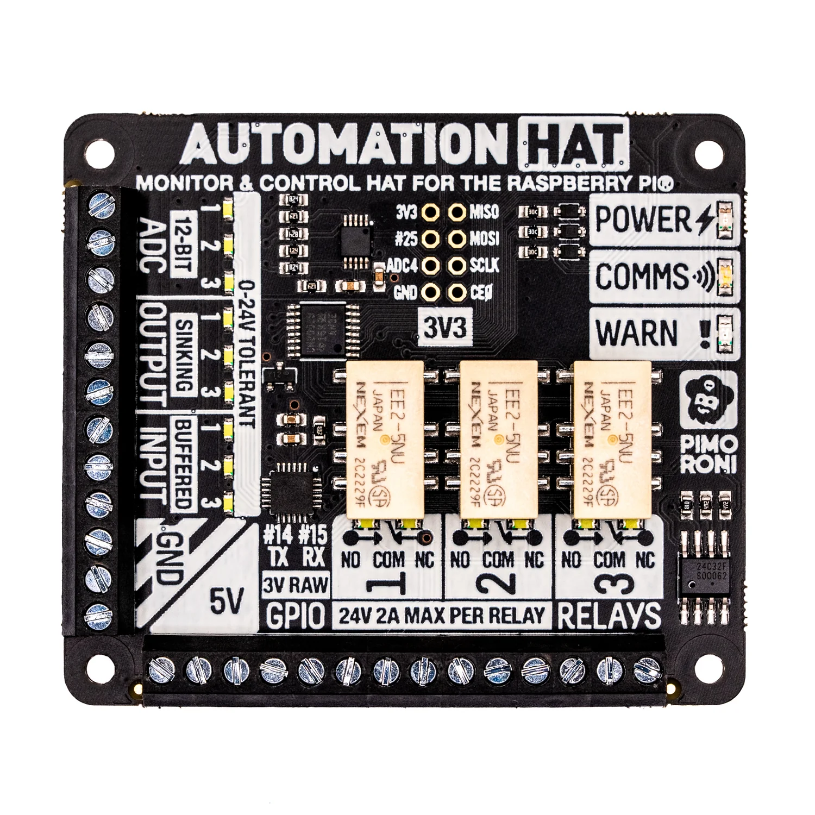
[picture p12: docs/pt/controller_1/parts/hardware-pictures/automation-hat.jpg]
automation-hat

[[2]](#references)

#### 12V submersible water pump of 240L/h capacity

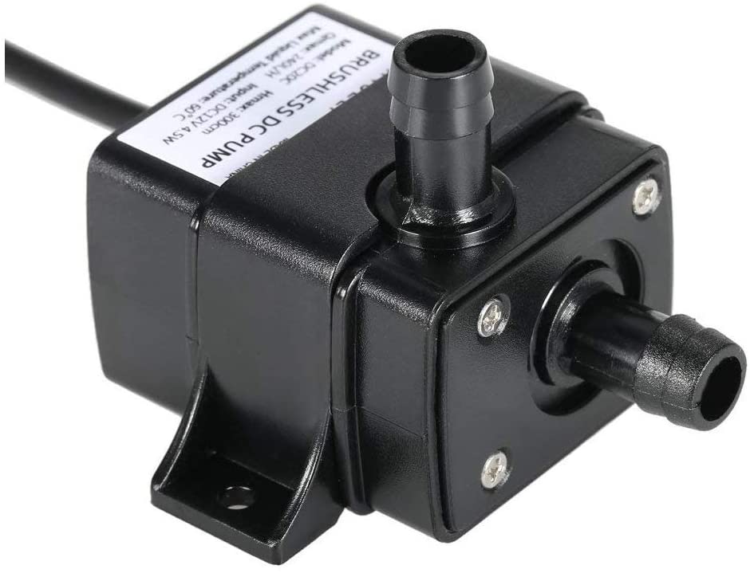
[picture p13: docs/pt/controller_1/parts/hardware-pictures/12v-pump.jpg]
12v-pump

[[3]](#references)

#### Stackeble T GPIO header

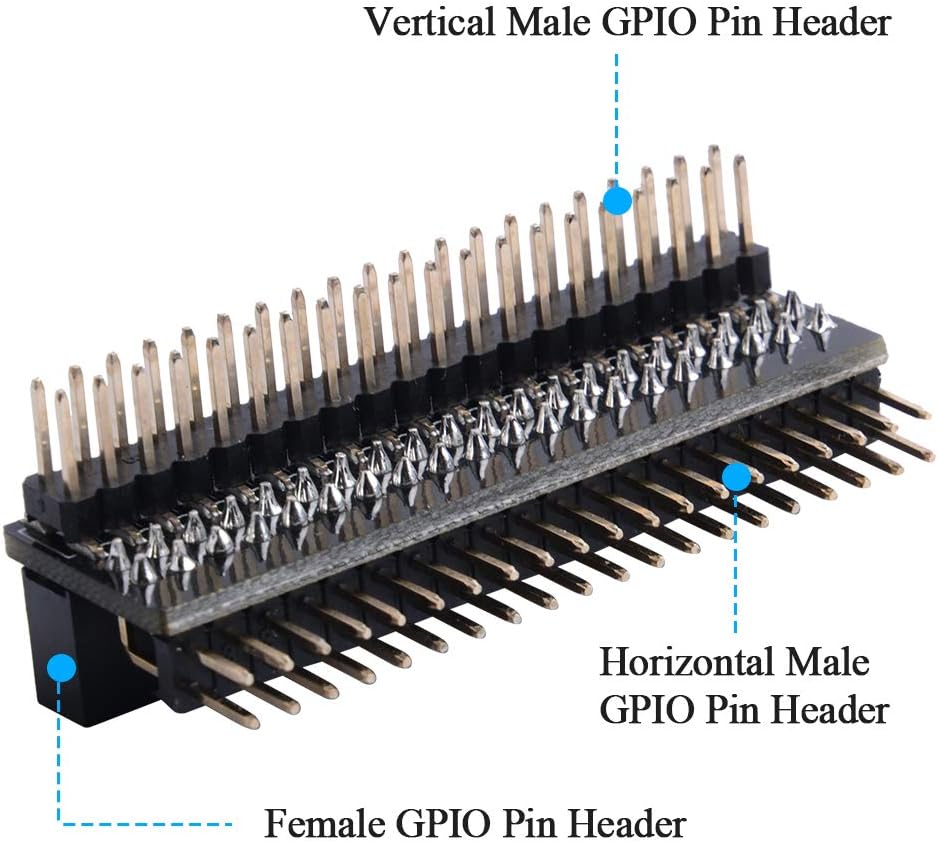
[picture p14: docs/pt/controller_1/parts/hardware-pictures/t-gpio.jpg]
t-gpio

[[4]](#references)

#### Adafruit Stemma 2.0 soil sensor

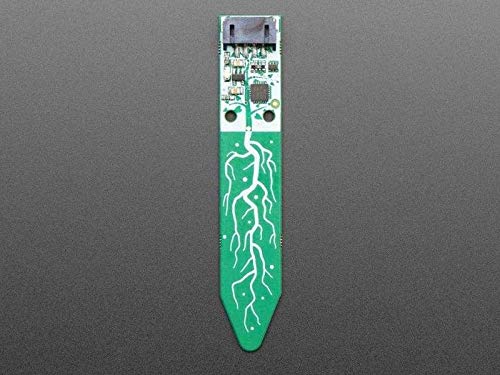
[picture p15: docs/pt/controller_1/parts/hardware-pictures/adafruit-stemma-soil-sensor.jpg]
adafruit-stemma-soil-sensor

[[5]](#references)

#### Adafruit PCA9548 8-Channel STEMMA QT

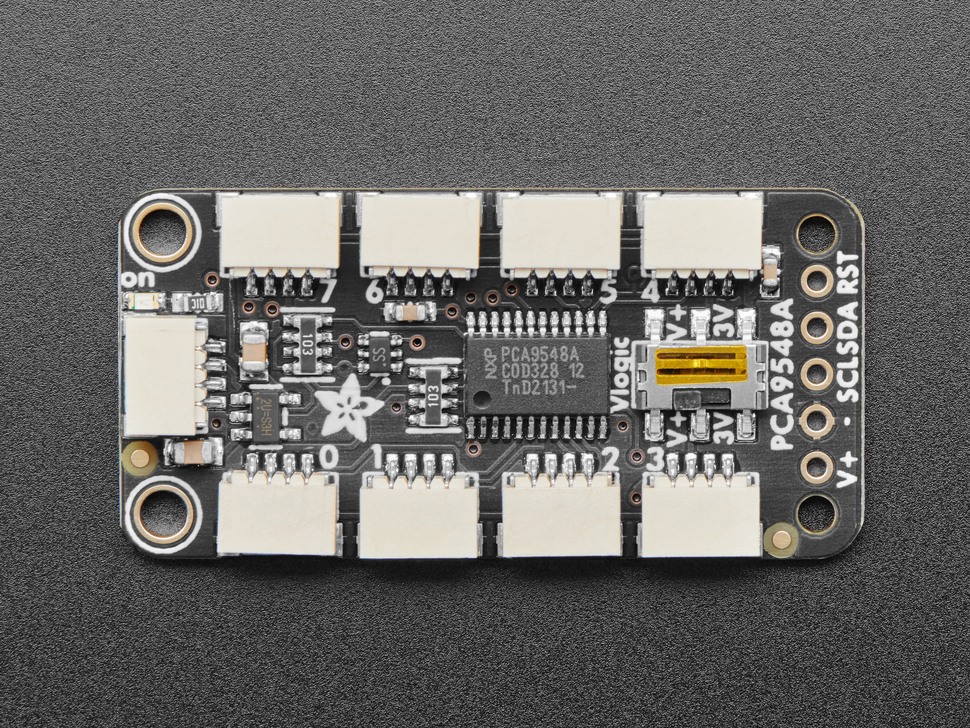
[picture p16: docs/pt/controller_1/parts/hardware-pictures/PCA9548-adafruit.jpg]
PCA9548-adafruit

[[6]](#references)

#### Adafruit SHT45 temperature and humidity sensor

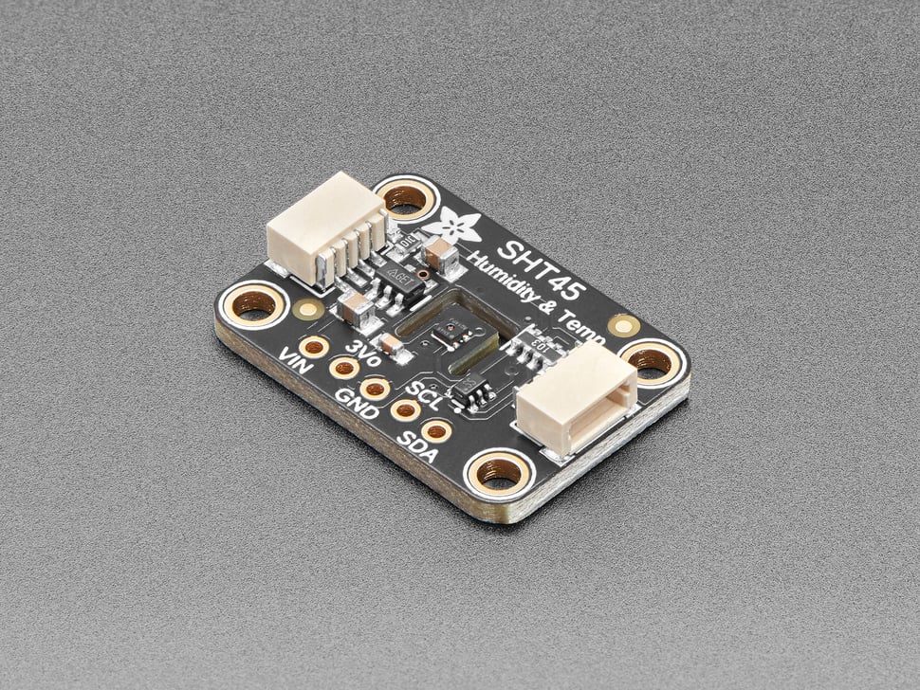
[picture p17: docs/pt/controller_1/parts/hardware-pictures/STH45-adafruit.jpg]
STH45-adafruit

[[7]](#references)

#### 2A 72W Adjustable Power Supply DC 3V ~ 36V

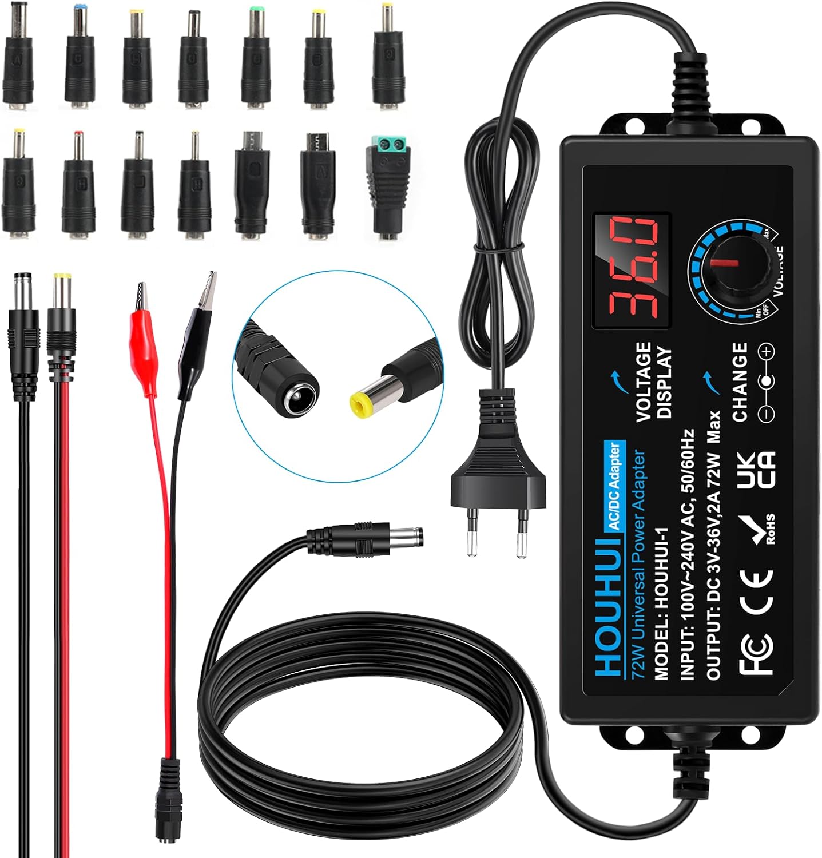
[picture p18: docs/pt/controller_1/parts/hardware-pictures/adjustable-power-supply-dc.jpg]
adjustable-power-supply-dc

[[8]](#references)

You can also use a regular 12V DC power supply.

#### I2C Qwiic Cable Kit Stemma QT

cable-kit-stemma-qt
[[9]](#references)

#### df 2 in 6 Out Lever, Compact Cable Connector

df-2-6-out-lever-cable-connector
[[10]](#references)

#### 18AWG DC 12V 5A 5.5 x 2.1 mm Male Female DC Power Pigtail Cable

male-female-power-pigtail-cable
[[11]](#references)

#### M2.5 Nylon Screws Nuts Set, Black Nylon Spacer Screw Nuts phillips Scrw kit

nylon-screws-nut-set
[[12]](#references)

## References

[1]: [Raspberry Pi 3 Model B+](https://raspberrypi.dk/produkt/raspberry-pi-3-model-b-plus/)
[2]: [Pimoroni AutomationHAT](https://shop.pimoroni.com/products/automation-hat)
[3]: [12V Submersible Water Pump (240L/h)](https://arduinotech.dk/shop/12v-submersible-water-pump-240lh-vand-pumpe/)
[4]: [Stackable T GPIO Header](https://www.amazon.de/-/en/dp/B08C581XHV?ref=ppx_yo2ov_dt_b_fed_asin_title)
[5]: [Adafruit Stemma 2.0 Soil Sensor](https://www.amazon.de/-/en/dp/B07QH7RXBL?ref=ppx_yo2ov_dt_b_fed_asin_title)
[6]: [Adafruit PCA9548 8-Channel STEMMA QT](https://www.adafruit.com/product/5626)
[7]: [Adafruit SHT45 temperature and humidity sensor](https://www.adafruit.com/product/5665)
[8]: [2A 72W Adjustable Power Supply DC 3V ~ 36V](https://www.amazon.de/-/en/dp/B0DCV6SJ4C?ref=ppx_yo2ov_dt_b_fed_asin_title&th=1)
[9]: [I2C Qwiic Cable Kit Stemma QT](https://www.amazon.de/-/en/dp/B08HQ1VSVL?ref=ppx_yo2ov_dt_b_fed_asin_title)
[10]: [2 in 6 Out Lever Compact Cable Connector](https://www.amazon.de/-/en/dp/B0DDXK22W8?ref=ppx_yo2ov_dt_b_fed_asin_title&th=1)
[11]: [18AWG DC 12V 5A 5.5 x 2.1 mm Male Female DC Power Pigtail Cable](https://www.amazon.de/-/en/dp/B0CX44HTKZ?ref=ppx_yo2ov_dt_b_fed_asin_title)
[12]: [M2.5 Nylon Screws Nuts Set](https://www.amazon.de/-/en/dp/B0DCS5C7SN?ref=ppx_yo2ov_dt_b_fed_asin_title&th=1)

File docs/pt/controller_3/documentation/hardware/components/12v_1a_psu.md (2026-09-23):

# 12V 1A Power Supply
To power the connected pumps and the relay a 12V power supply with a [5.5/2.1 mm barrel plug](./barrel_plug.md).

It is recommended that the power supply be able to supply a current of up to 
1 Amp. This will allow for up to 3 connected pumps.

If a fourth pump is to be connected to the system, choose a 12V power supply
able to provide 1.5 or 2 Amps of current.

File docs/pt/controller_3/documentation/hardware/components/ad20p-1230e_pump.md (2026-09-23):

# AD20P-1230E pump
Image of the AD20P-1230E pump with cord and mounting bracket

The AD20P-1230E is 12V submersible pump. It is used to water connected plants, 
with one pump per plant.

To function as expected it should either be submerged in the Plant Controllers
water tank.

## Connections
Description of the AD20P-1230E pump

The inlet is on the end of the pump.

The outlet is on the side of the pump.

The power socket is on the end of the cord.

The pump might come with a mounting bracket.

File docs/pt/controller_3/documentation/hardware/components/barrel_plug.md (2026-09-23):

# 5.5/2.1mm Barrel Plug
Image of a barrel plug

To connect the [relay](./cs-io404.md) with the [pumps](./ad20p-1230e_pump.md) 
5.5/2.1mm barrel plugs are used.

These should be connected to suitable leads. Buying the plugs with leads 
attached should ensure proper connection. If bought without leads, 
ensure that the leads can handle a current of 300mA and a potential of 12V.

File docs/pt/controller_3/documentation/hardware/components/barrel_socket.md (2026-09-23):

# 5.5/2.1mm Barrel Socket
Image of a barrel socket

To connect the [relay](./cs-io404.md) with the [power supply](./12v_1a_psu.md) 
a 5.5/2.1mm barrel socket is used.

This should be connected to suitable leads. Buying the socket with leads 
attached should ensure proper connection. If bought without leads, 
ensure that the leads can handle a current of 1A and a potential of 12V.

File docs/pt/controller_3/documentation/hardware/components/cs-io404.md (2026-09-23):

# CS-IO404 4-Channel Relay
Image of the CS-IO404 relay

The CS-IO404 relay is used to toggle any connected pumps on and off.

## Suppliers
The relay can be sourced from [DFRobot](https://www.dfrobot.com/product-2349.html).

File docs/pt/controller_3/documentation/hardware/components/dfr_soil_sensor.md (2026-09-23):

# RS485 Soil Sensor
Image of the soil sensor

This sensor measures temperature, moisture and electric conductivity of soil 
it is buried in. It is the recommended basic sensor for the Plant Controller.

It connects over RS485, and needs to be connected to the Plant Controllers
RS485 bus.

When connecting a newly bought sensor, make sure to change the sensors MODBUS 
address using the plant controllers setup utility. By default this address is
1, and it should be changed to something unique among connected MODBUS parts,
from 2 to 253.

## Suppliers
The sensor can be sourced at [DFRobot](https://www.dfrobot.com/product-2817.html)

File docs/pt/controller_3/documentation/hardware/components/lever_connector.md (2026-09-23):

# Lever connector
Image of a lever connector

To connect the Plant Controllers different wires it is advised to use 
connectors instead of soldering. This is to allow easy disassembly, and to
ensure that all connections made are solid.

The type of connector does not matter, so long
as it is suitable for the wire thickness, and the number of connections in the
connector matches the number of wires that need to meet.

In the basic setup detailed in the [quick start guide](../../../setup/quick_start.md)
most of these connections are between two or three sets of two wires. To make
assembly simple (and allow for future extensions), we've used the same type of 
connector everywhere, which can be seen in the picture above.

This type of connector goes by many names, but should be sourceable by 
searching for "2 in 4 out lever connector" on Amazon or AliExpress.

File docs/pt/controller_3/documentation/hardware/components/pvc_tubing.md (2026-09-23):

# Water tubing
Example of PVC tubing used to connect pumps to plants

To move water from the water tank to the plants, flexible VC tubing is used.
The tubing should be long enough to reach from the bottom of the water tank to
the connected plants. It should have an inner diameter of 8mm.

## Suppliers
Tubing should be available at most hardware stores.

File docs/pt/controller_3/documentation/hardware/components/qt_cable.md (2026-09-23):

# STEMMA QT connector cable
Image of a STEMMA QT connector cable

To connect the Adafruits components to each other on the I2C line, STEMMA QT
cables are used. These are, in essence, four wires connected to JST-SH female 4-pin connectors,
and can be manually constructed with correct tools and components.

## Suppliers
The QT connector can be sourced at [Adafruits website](https://www.adafruit.com/product/4210),
or in other hobby component stores under names like STEMMA QT, Qwiic or simply JST-SH female 4-pin
to JST-SH female 4-pin cables.

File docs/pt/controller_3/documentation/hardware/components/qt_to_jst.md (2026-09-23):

# QT to header sockets cable
Image of the cable

This cable is used to connect the I2C component daisy chain to the Raspberry Pi's headers.

## Suppliers
The cable can be sourced from [Adafruits website](https://www.adafruit.com/product/4397),
or from other hobby component stores as STEAMM QT, Qwiic or JST SH 4-pin to header sockets cables.

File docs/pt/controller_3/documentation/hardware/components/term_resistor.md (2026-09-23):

# Termination resistors
When a RS485 bus line becomes long, it is necessary to terminate it with 
120 Ohm resistors. This ensures signal integrity.

What long constitutes is use case dependent. For the Plant Controller 
termination resistors shouldn't be theoretically be necessary unless the line
is longer than 2km. But, if your line is very long, and you are experiencing
problems with the signal to and from parts connected to the RS485 bus, 
connecting termination resistors might help.

The resistors won't be under very heavy load so basic 1/2 watt 5% leaded
resistors will do the trick.

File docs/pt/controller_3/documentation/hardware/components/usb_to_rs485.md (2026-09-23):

# USB to RS485 module
Wiring

This USB module is used to connect the Raspberry Pi to the RS485 bus.

## Suppliers
This module can be sourced at [DFRobot](https://www.dfrobot.com/product-2189.html)

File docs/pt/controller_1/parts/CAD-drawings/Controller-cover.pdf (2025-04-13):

TITLE | Controller Cover PART NO | Controller-cover REVISION | 0.2.0 DESIGNER | Rasmus Elm ENGINEER NOTES

THE INFORMATION AND/OR MATERIAL IN THIS DOCUMENT IS THE PROPERTY OF AND RESTRICTED INFORMATION AND/OR MATERIAL OF THE AUTHOR. THIS INFORMATION MAY NOT BE USED, REPRODUCED, PUBLISHED OR DISCLOSED TO OTHERS WITHOUT WRITTEN AUTHORIZATION. IT IS TO BE USED ONLY FOR MANUFACTURING ITEMS SPECIFIED WITHIN THE DOCUMENT.

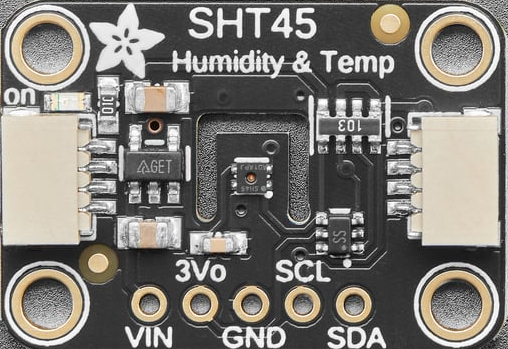
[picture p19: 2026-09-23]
docs/pt/controller_3/documentation/hardware/components/sht45_topdown.jpg

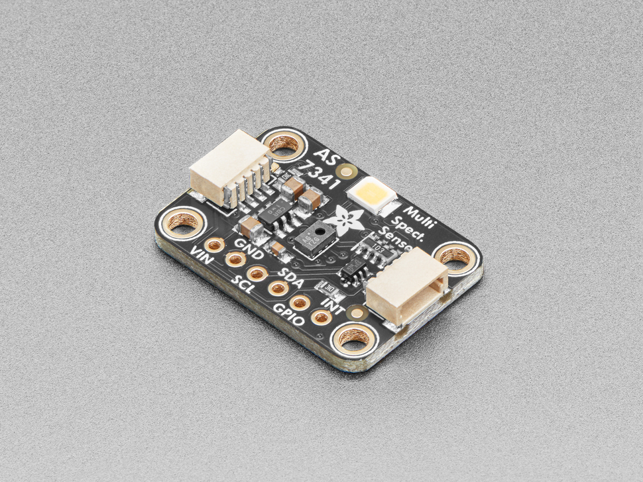
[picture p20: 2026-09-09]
docs/pt/controller_3/documentation/hardware/components/as7341.jpg

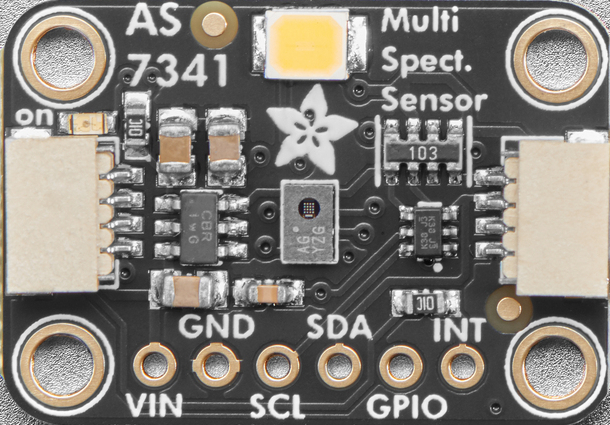
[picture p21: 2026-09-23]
docs/pt/controller_3/documentation/hardware/components/as7341_topdown.jpg

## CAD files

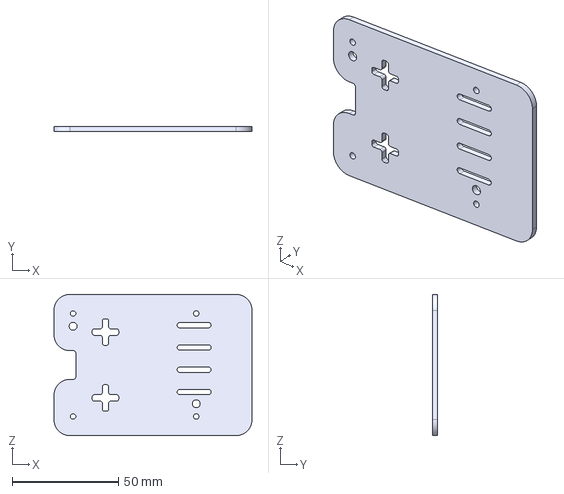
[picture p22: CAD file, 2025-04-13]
docs/pt/controller_1/parts/CAD-drawings/RaspberryPi-Base-Plate.stp
93.2 x 2.50 x 66.5 mm

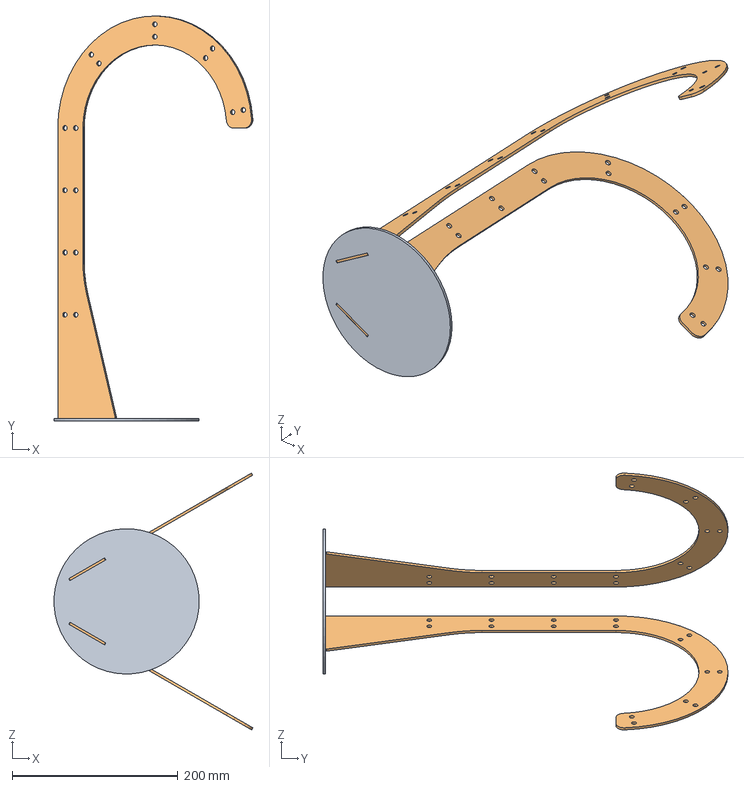
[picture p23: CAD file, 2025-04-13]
docs/pt/controller_1/parts/CAD-drawings/Water-plant-X2-structure.stp
239.5 x 488.0 x 309.5 mm
Bottom Plate
Water Pipe Guide x 2

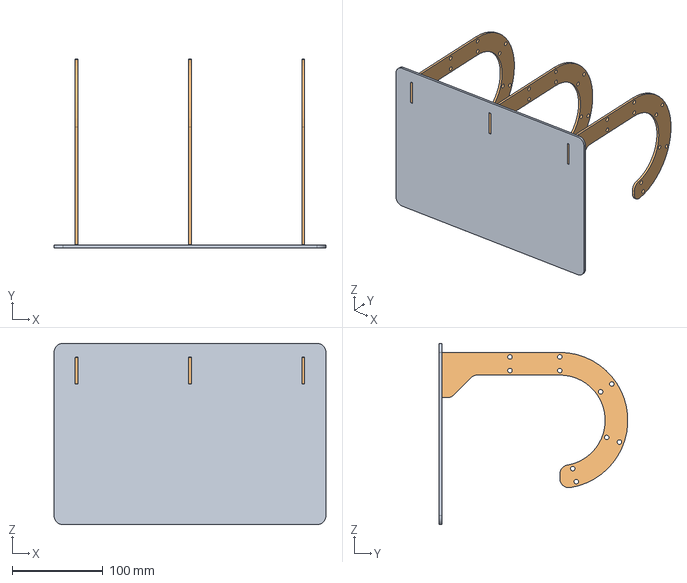
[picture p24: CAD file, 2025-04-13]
docs/pt/controller_1/parts/CAD-drawings/Water-plant-X3-structure.stp
300.0 x 207.9 x 200.0 mm
Water plant X3
Water plant X3 bue x 3

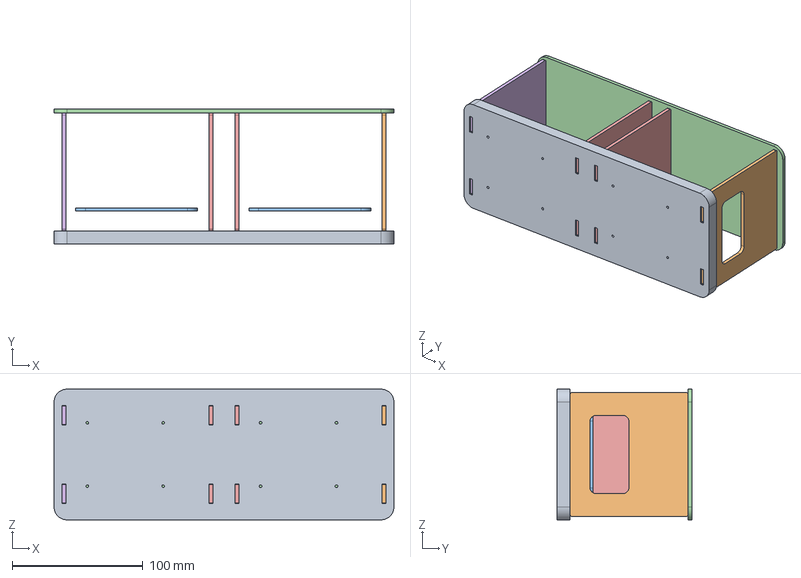
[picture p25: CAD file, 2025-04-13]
docs/pt/controller_1/parts/CAD-drawings/Controller-cover.stp
260.0 x 103.0 x 100.0 mm
Bottom-plate
Right-plate
RPi-base x 2
Top-plate
Mid-plate x 2
Left-plate

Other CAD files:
docs/pt/controller_1/parts/CAD-drawings/Sensor-mount-plate.stp

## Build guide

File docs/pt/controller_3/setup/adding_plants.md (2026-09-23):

# Adding plants to the Plant Controller
The Plant Controller is designed to support up to 4 plants. A "plant" in this case is something that is senseable and needs watering, and can, in theory, be anything from a single small house plant, to a bed of multiple plants of varying sizes and species. The physicality of the biological plant or plants is up to the implementer and the use case.

The Plant Controller really only knows about connected sensors and actuators, which is what defines the plant to it.

So, to add a new plant, connect a new [pump](../documentation/hardware/components/ad20p-1230e_pump.md) to an empty coil in the [relay](../documentation/hardware/components/cs-io404.md), connect any [new sensors](custom_sensors.md) to the MODBUS bus and/or the I2C bus as needed, and add new [plant](../documentation/software/config/plant_config.md) and [watering schedule](../documentation/software/config/watering_schedule.md) configs in the config directories. Then, if need be, run any neccesary setup actions with the [setup utility](../documentation/software/plant_controller/cli.md).

With all that done, the new plant is connected.

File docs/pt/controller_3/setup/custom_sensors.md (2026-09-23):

# Custom sensors
The Plant Controller is by default able to be connected to and [configured for](../documentation/software/config/plant_config.md) the [DF Robot soil sensor](../documentation/hardware/components/dfr_soil_sensor.md) and the [STEMMA soil sensor](../documentation/hardware/components/stemma_soil_sensor.md). It is possible though to add new custom sensors to the Plant Controller.

This can be done by adding new drivers for the already existing sensor types (see [plant configuration](../documentation/software/config/plant_config.md) and the source code docs for the [sensor modules](../../../api/plant_controller/sensors/index.md)), but it is also possible to add entirely new nesor hardware to the as long as it adheres to a couple of restrictions.

## Custom sensor communication protocol
All new sensors connected to the Plant Controller must either communicate via the MODUS RTU protocol or the I2C protocol.

If communicating over MODBUS RTU, make sure that the new sensor is configured with

- a baudrate of 9600
- a bytesize of 8
- no parity
- 1 stopbit

If communicating over I2C, make sure that you have the correct cable to connect it to the STEMMA QT port on the greenhouse sensors, and that the new sensors address doesn't conflict with that of the [greenhouse light sensor](../documentation/hardware/components/ada_as7341.md) and [greenhouse air sensor](../documentation/hardware/components/ada_sht45.md).

## Custom sensor power draw
If MODBUS RTU based sensors need 5V power, either make sure that the total power of all sensors connected to the Plant Controllers 5V power line doesn't exceed 5W OR supply the sensor with power externally.

## Coding the custom sensor module
There is a standard API for new sensor modules that should be followed to ensure proper functionality. See the source code doces for [sensor modules](../../../api/plant_controller/sensors/index.md) and the other sensors for API guidance and inspiration, and the source docs for [communication procotols](../../../api/plant_controller/com_bus.md) for understanding of the communication busses.

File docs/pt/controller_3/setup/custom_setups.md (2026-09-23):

# Custom Setups
See [Custom Sensors](custom_sensors.md) and [Adding Plants](adding_plants.md).

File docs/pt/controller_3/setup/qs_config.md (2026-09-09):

# Configure the controller

Before use, the plant controller needs to be configured for the current setup.
Make sure that all hardware and software is installed before continuing.

## Set up the config folder

All configuration lives in the `.plant_controller` subdirectory of the user's
home directory. Initialize it from the example implementation shipped with the
source code:

```bash
cp -r <src>/pt/controller_3/impl ~/.plant_controller
mv ~/.plant_controller/config.toml.example ~/.plant_controller/config.toml
```

## Configure the database connection

Edit `~/.plant_controller/config.toml` and set the `token` value to the
`<ADMIN_TOKEN>` from earlier. If the database name, host or port differ from
the defaults (for instance if the database runs on another machine), update
them here too:

```toml
[database]
name = "plant-controller"
host = "http://127.0.0.1:8181"
token = "<ADMIN_TOKEN>"
```

## Configure the connected plant

Each connected plant gets its own JSON file in
`~/.plant_controller/plants/`, declaring its sensors and its pump.
An example configuration made for this quick start is already included in the
config folder. Rename it, removing the `.example` suffix and replacing
`plant_name` with a useful identifier (`<PLANT_IDENTIFIER>`) for the connected
plant (note this name down for later):

```bash
mv ~/.plant_controller/plants/plant_name.json.example ~/.plant_controller/plants/<PLANT_IDENTIFIER>.json
```

Watering of the plant is done following a schedule. Watering schedules live in
`~/.plant_controller/pump_schedules/`, one JSON file per plant. This folder
comes with an example schedule just like the plant configuration. As with the
plant config, rename it, removing the `.example` suffix and replacing
`plant_name` with the previously chosen identifier, making sure that they are
the same:

```bash
mv ~/.plant_controller/pump_schedules/plant_name.json.example ~/.plant_controller/pump_schedules/<PLANT_IDENTIFIER>.json
```

## Change the MODBUS address of the soil sensor

The connected
[soil sensor](../documentation/hardware/components/dfr_soil_sensor.md) has the
standard MODBUS address of 1 from the factory. This should be changed to avoid
address conflicts if adding more sensors in the future.

To do this, first disconnect the 12V DC power supply, and check that CS-IO404
is powered off (no lights on in the relay).

With that done, ensure that the InfluxDB database is running, starting it if
it isn't.

Then, in a separate terminal, source the previously set up Python virtual
environment and then start the plant_controller in setup mode:

```bash
source ~/.venv/bin/activate
cd <src>/pt/controller_3/src
python -m plant_controller setup
```

From within the setup utility, change the sensor address by writing
`<PLANT_IDENTIFIER>.sensor.soil.change_device_id` (substituting `<PLANT_IDENTIFIER>` for the
identifier previously chosen for the connected plant), hitting enter, and
following the guide as presented by the program.

Make sure that the address chosen is not the same as the CS-IO404 relay; choosing an address above 32 will ensure that there is no conflict if following this guide.

If the id change was successful, exit the setup program, and reconnect power
to the CS-IO404 relay.

## Calibrate the pump

The pump needs to be calibrated after installation to ensure proper water
dosage.

!!! warning
    The whole plant controller system should be in its final location and
    configuration before calibrating — moving pumps and pump outlets after
    calibration invalidates it.

In preparation, remove the plant from under the pump outlet, and replace it
with an empty vessel able to hold 1 liter of water.

When ready, make sure that the database is running and that the Python virtual
environment has been sourced, then start the plant_controller in setup mode:

```bash
source ~/.venv/bin/activate
cd <src>/pt/controller_3/src
python -m plant_controller setup
```

From here, start calibration by writing
`<PLANT_IDENTIFIER>.pump.calibrate` (substituting `<PLANT_IDENTIFIER>` for the
identifier previously chosen for the connected plant), hitting enter, and
following the on screen guide.

When the pump is sufficiently calibrated, replace the plant under the pump
outlet.

---

[**Run the controller**](qs_run.md)

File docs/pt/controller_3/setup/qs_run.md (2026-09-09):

# Run the controller

If all previous steps have been followed the controller should now be fully
functional. To run it, ensure that the Python virtual environment has been
sourced, then:

```bash
source ~/.venv/bin/activate
cd <src>/pt/controller_3/src
python -m plant_controller run
```

The controller now monitors and waters the connected plant, and the web
interface is accessible on port 8099 of the Raspberry Pi.

If connected to the Raspberry Pi over LAN, this interface can be found by
typing `<CONTROLLER_IP>:8099` in a browser from another computer on the same
LAN, where `<CONTROLLER_IP>` is the IP of the Raspberry Pi.

If running the Raspberry Pi with a desktop environment and a connected screen
and keyboard, the web interface is available from within the Raspberry Pi by
typing `localhost:8099` in the Raspberry Pi's browser.

---

[**Next steps**](./qs_next_steps.md)

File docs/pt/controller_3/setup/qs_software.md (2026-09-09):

# Install the software
Software installation will come with some waiting time — during these times it
is possible to [assemble hardware](./qs_hardware.md) not directly connected to the Raspberry Pi.

## Install Raspberry Pi OS

Download the [Raspberry Pi Imager](https://www.raspberrypi.com/software/) to
the extra computer. (See their guide on
[how to use the installer](https://www.raspberrypi.com/documentation/computers/getting-started.html#imager-install),
if need be.)

Connect the micro SD card to the extra computer.

Run the Raspberry Pi Imager to start the installation process.

Choose **"Raspberry Pi 5"** as the device.

If you have the optional screen and keyboard for the Raspberry Pi, choose
**"Raspberry Pi OS (64-bit)"** for the OS. Otherwise choose
**"Raspberry Pi OS Lite (64-bit)"**.

Choose the connected micro SD card as the storage.

Customize your Raspberry Pi OS as desired, making sure to:

- choose a hostname for the Raspberry Pi (for example "plant-controller")
- choose your localization
- set a username and password
- input your LAN's Wi-Fi credentials (if you are not using a wired connection)
- enable SSH connectivity, if you DON'T have a screen and keyboard for the
  Raspberry Pi

!!! tip "No screen or keyboard?"
    If you can't connect to your Raspberry Pi through SSH over your LAN for
    some reason, enable **Raspberry Pi Connect**. This will allow you to
    connect to the Raspberry Pi over a USB connection instead.

Finally, set imager options and start writing the OS to the micro SD card.
This will erase all things previously stored on the micro SD card before
writing the OS and will take a couple of minutes.

When it is done, eject the micro SD card (if it hasn't already been ejected),
disconnect it from the computer, and insert it into the Raspberry Pi.

Boot up the Raspberry Pi (connecting the screen and keyboard to it beforehand
if available).

If you installed the Raspberry Pi OS with a desktop environment and have a
screen and keyboard connected to it, put away the extra computer; it won't be
needed for the rest of this guide. Then, open a terminal.

If you installed the Raspberry Pi OS Lite you'll have to connect to the
Raspberry Pi over SSH from the extra computer. In the future, when you are
instructed to open a new terminal, do it by SSH'ing in from the extra computer
in a new terminal.

From the terminal, ensure that the Raspberry Pi is updated by running:

```bash
sudo apt-get update -y && sudo apt-get upgrade -y
```

When everything is updated, continue to the next step.

---

## Install the database

The controller uses **InfluxDB 3.0 or later** to store measurements and
watering events.

!!! warning "Raspberry Pi 5 page size"
    The default OS kernel for the Raspberry Pi 5 uses a memory page size of
    16k, but InfluxDB 3 assumes a page size of 4k. Before installing the
    database on a Raspberry Pi 5, switch to the 4k kernel by setting
    `kernel=kernel8.img` in `/boot/firmware/config.txt`:

    ```bash
    echo "kernel=kernel8.img" | sudo tee -a /boot/firmware/config.txt
    sudo shutdown -r now
    ```

    This reboots the Raspberry Pi and terminates any SSH connection to the
    machine — give it some time, then reconnect.

Install InfluxDB 3:

```bash
curl -O https://www.influxdata.com/d/install_influxdb3.sh \
&& sh install_influxdb3.sh
```

Choose the local install, and decline when the install script asks whether to
start the server at the end. Then start the server yourself:

```bash
influxdb3 serve --node-id node0
```

With the server running, open a new terminal (or SSH session) and create the
admin token:

```bash
influxdb3 create token --admin
```

Note the token down — it is referred to as `<ADMIN_TOKEN>` below, and is
needed in the controller's config file. Then create the database for the
controller:

```bash
influxdb3 create database --token <ADMIN_TOKEN> --retention-period 7d plant-controller
```

Here the retention period is set to 7 days to avoid gumming up the
controller's persistent storage, and the database name to `plant-controller`,
which is the default in the config file. Both can be changed freely, as long
as the config file is updated accordingly.

### Start InfluxDB automatically

To ensure the database starts automatically, create a systemd service:

```bash
sudo tee /etc/systemd/system/influxdb3.service > /dev/null << 'EOF'
[Unit]
Description=InfluxDB 3
After=network.target

[Service]
ExecStart=/usr/local/bin/influxdb3 serve --node-id node0
Restart=on-failure

[Install]
WantedBy=multi-user.target
EOF

sudo systemctl daemon-reload
sudo systemctl enable --now influxdb3
```

!!! note
    If `influxdb3` was installed to a different path, update the
    `ExecStart` line accordingly. You can find the path with
    `which influxdb3`.

---

## Install the controller software

First, get the source code onto the Raspberry Pi, either by cloning it from
GitHub or by SCP'ing it over from the extra computer:

```bash
git clone https://github.com/DisasterlyDisco/plant-controller.git
```

In the following, `<src>` refers to the full path of the cloned repository.

Install pip and venv support:

```bash
sudo apt-get install -y python3-pip python3-venv python3-setuptools
```

Create a virtual environment (here in the home directory) and activate it:

```bash
cd ~
python -m venv .venv --system-site-packages
source .venv/bin/activate
```

### Install Adafruit Blinka

Adafruit Blinka provides the Python API for the Raspberry Pi's GPIO header,
which the controller uses for I2C communication with the Adafruit sensor
modules. It cannot simply be installed with pip, as it needs to configure the
machine itself — Adafruit supplies a convenience script:

```bash
cd ~
pip install --upgrade adafruit-python-shell
wget https://raw.githubusercontent.com/adafruit/Raspberry-Pi-Installer-Scripts/master/raspi-blinka.py
sudo -E env PATH=$PATH python3 raspi-blinka.py
```

### Install remaining Python dependencies

With Blinka installed, install the rest of the Python requirements as normal:

```bash
cd <src>/pt/controller_3
pip install -r requirements.txt
```

---

[**Configure the controller**](./qs_config.md)

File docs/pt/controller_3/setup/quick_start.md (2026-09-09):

# Quick Start Guide

This guide walks through setting up a minimal, fully functional Plant
Controller on a dedicated **Raspberry Pi 5**, monitoring and controlling
**1 plant**. By the end you will have a working controller that measures
light, air temperature, humidity and soil conditions, waters the plant on a
schedule, and exposes all data over a web interface.

!!! note "Alternative setups"
    The Plant Controller can be set up to monitor and control multiple plants,
    using different sensors, and running on alternative hardware. If it's your
    first time setting up version 3 of the Plant Controller, it is advised to
    follow this quick start guide first. Guides for alternative setups can be
    found [here](./custom_setups.md).

The quick start guide is divided into 6 steps:

1. [Requirements](./qs_requirements.md)
2. [Assemble the hardware](./qs_hardware.md)
3. [Install the software](./qs_software.md)
4. [Configure the controller](./qs_config.md)
5. [Run the Controller](./qs_run.md)
6. [Next Steps](./qs_next_steps.md)

---

[**Requirements**](./qs_requirements.md)

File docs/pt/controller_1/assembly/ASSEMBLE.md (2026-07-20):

# Assembly Instruction

This instruction shows how to build the example plants controller.
It is a prototype of an edge controller for
a physical green house. A complete physical prototype looks like this.

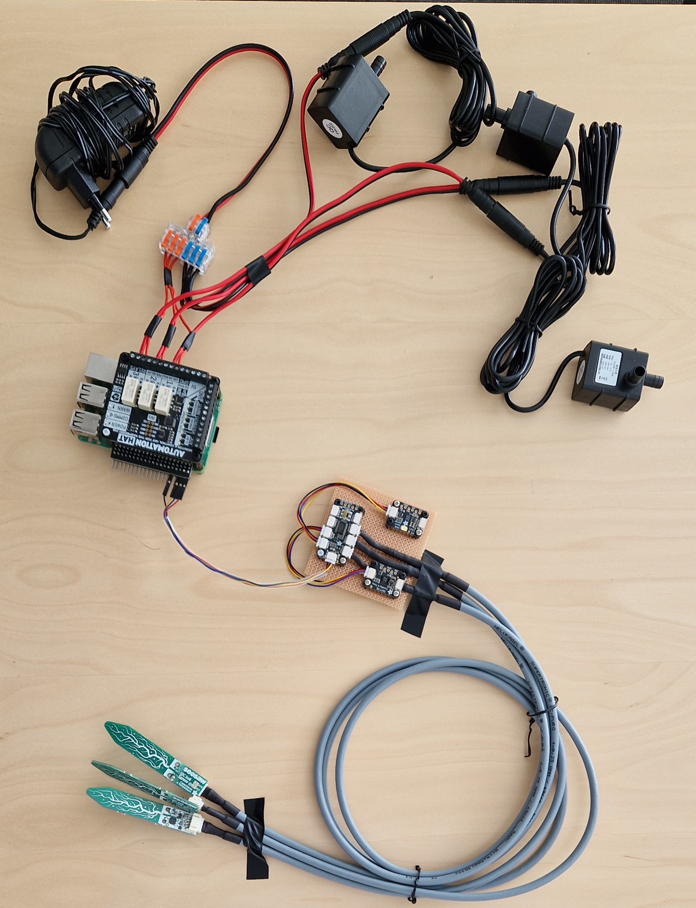
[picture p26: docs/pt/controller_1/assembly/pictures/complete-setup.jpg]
prototype


The following tutorial helps with assembling of the prototype.

## Parts list

Please see the complete [parts list](../PARTS.md).
If you are not familiar with the hardware components used in this prototype,
please see
[their pictures](../parts/hardware-pictures/parts-pictures.md).

## Step-by-step Instructions

Follow this step-by-step guide to build the plant controller prototype.
The guide is divided into 6 parts. Each part builds a component of
the controller. Each step of the assembly is accompanied by a picture.

### Part 1: Building the Sensor Plate

In this step the sensor plate containing with three components is build.
The plate contains two sensors and a multiplexer, namely

1. Adafruit [SHT45 temperature and humidity sensor](../parts/hardware-pictures/STH45-adafruit.jpg).
1. Adafruit [AS7341 light sensor](../parts/hardware-pictures/AS7341-adafruit.jpg)
1. Adafruit [8-to-1 mulitplexer](../parts/hardware-pictures/PCA9548-adafruit.jpg).
1. The sensors are mounted on the breadboard uisng the pre-drilled holes.

Do the following assembly steps:

1. Mount the SHT45 sensor on the breadboard using 4x M2.5 washer,
    4x M2.5*8mm screws, 4x M2.5 spacers and 4x M2.5 studs. Ensure that
    the spacer is on the underside. See [picture 1](#sensor-plate-top-view).

1. Mount the AS7341 sensor on the breadboard using 4x M2.5 washer, 4x M2.5*8mm screws,
   4x M2.5 spacers and 4x M2.5 studs. Ensure that the spacer is on the underside.
   See [picture 1](#sensor-plate-top-view) and [picture 2](#sensor-plate-bottom-view).

1. Mount the Adafruit PCA9548A 1-to-8 I2C Multiplexer on the breadboard using
   2x M2.5 washer, 2x M2.5*8mm screws, 4x M2.5 spacers and 4x M2.5 studs.
   Ensure that the spacer is on the underside. See
   [picture 1](#sensor-plate-top-view) and [picture 2](#sensor-plate-bottom-view).

1. Connect the SHT45 sensor to the Adafruit PCA9548A 1-to-8 I2C Multiplexer
   using the I2C cables (port-6). See [picture 1](#sensor-plate-top-view).

1. Connect the AS7341 sensor to the Adafruit PCA9548A 1-to-8 I2C Multiplexer
   using the I2C cables (port 7). See [picture 1](#sensor-plate-top-view).

   <!-- markdownlint-disable MD013 -->

   The built sensor plate should look like this:
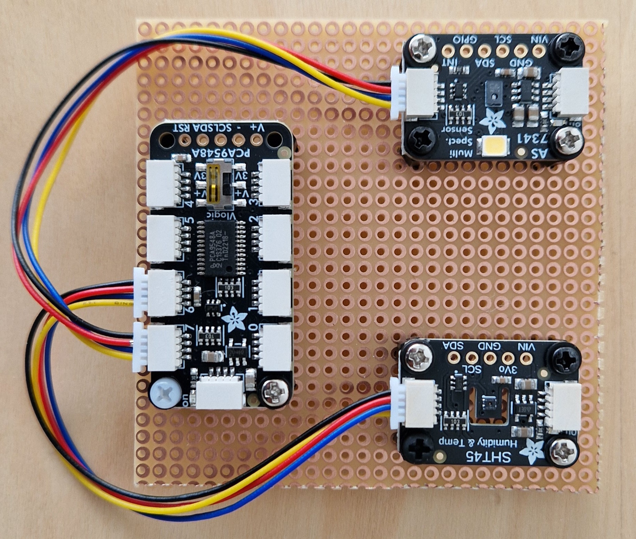
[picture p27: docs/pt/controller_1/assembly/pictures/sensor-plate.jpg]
Sensor Plate Top View
   

   <!-- markdownlint-disable MD013 -->

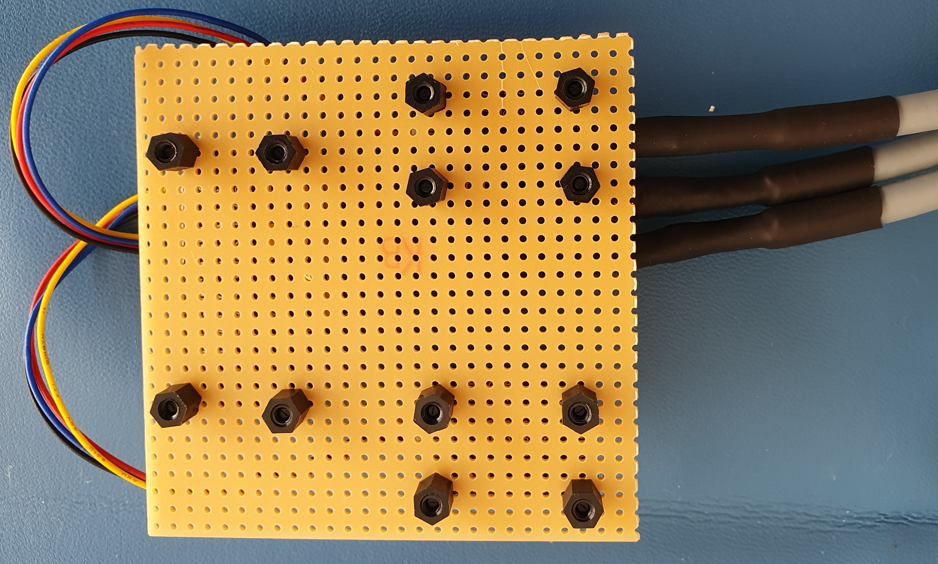
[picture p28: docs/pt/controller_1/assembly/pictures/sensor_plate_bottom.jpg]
sensor plate bottom-view
   

1. Connect the soil sensors to the Adafruit PCA9548A 1-to-8 I2C Multiplexer
   using the Stemma to StemmaQT cables into ports: 0, 1 and 2 on
   the Adafruit Multiplexer.
   See [picture 3](#complete-view-of-the-sensor-plate).

   <!-- markdownlint-disable MD013 -->

   Picture of the connected sensors and their respective ports:
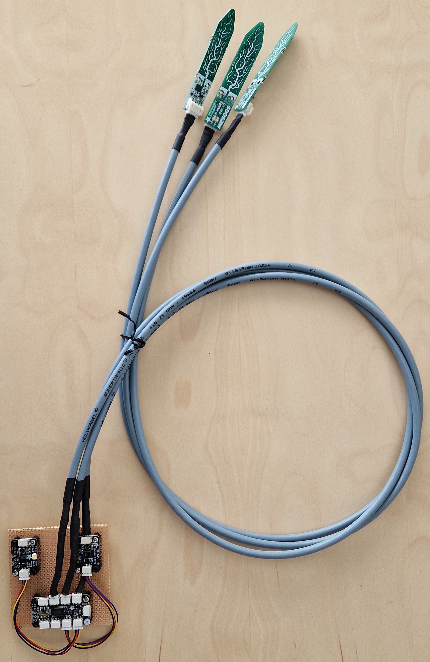
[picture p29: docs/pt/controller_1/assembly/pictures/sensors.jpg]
complete view of the sensor plate
   

### Part 2: Building the power board

In this step the power board is assembled. The power board is used to power
the pumps and gets powered by the 12v power supply. The power board build
contains the following components:

1. DF 62 [cable connector](../parts/hardware-pictures/df-2-6-out-lever-cable-connector.jpg).
1. Male Female [DC Power Pigtail Cable](../parts/hardware-pictures/male-female-power-pigtail-cable.jpg).
1. 12V variable power supply, like
   [this](../parts/hardware-pictures/adjustable-power-supply-dc.jpg)
   or standard 12V wall plug power supply.
1. 12V submersible water pump, like [this](../parts/hardware-pictures/12v-pump.jpg).
1. [Automation HAT](../parts/hardware-pictures/automation-hat.jpg).
1. Electric wire.

3.1 Connect the pumps to the Automation HAT and DF 62 cable connector
    using barrel plug to pigtail connector.
    **Red** from the pumps goes into the **COM** and the **black** from
    the pumps goes into the DF 62 cable connector to be grounded and powered
    by the 12V power supply. Use 3x electric wire to connect the DF 62
    wire connector to NO on the Automation Hat.
    See [picture 4](#power-board-zoom-detail-view). <!-- markdownlint-disable MD013 -->
    
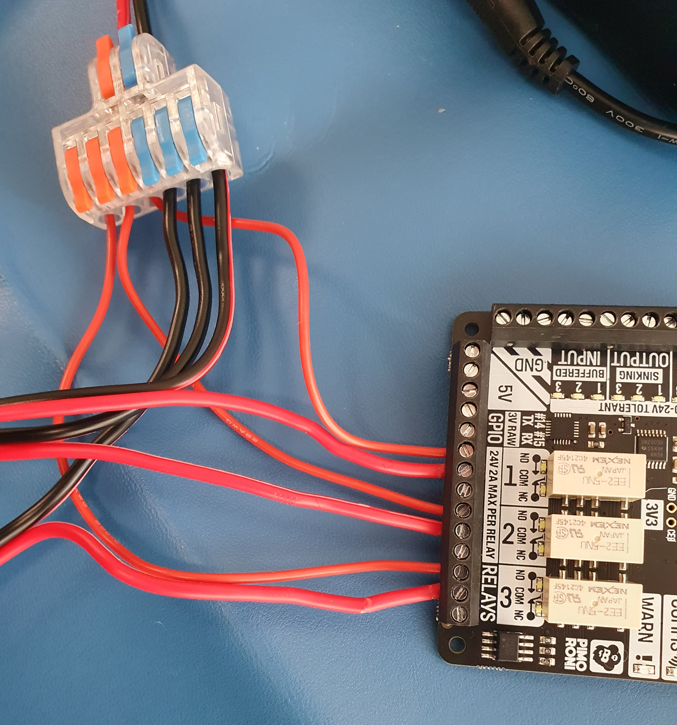
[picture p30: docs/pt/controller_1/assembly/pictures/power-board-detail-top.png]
Power board DF detail view
    

3.2 Connect the DF 62 cable connector to the power suppler using DC barrel
    Plug connector like on
    [picture 5](#power-board-detail-df).<!-- markdownlint-disable MD013 -->
    
Power Board Detail df
    

3.3 Connect the Automation HAT and pumps to the 12V power supply.
    This should look like [picture 6](#power-board-top-view).
    <!-- markdownlint-disable MD013 -->
    
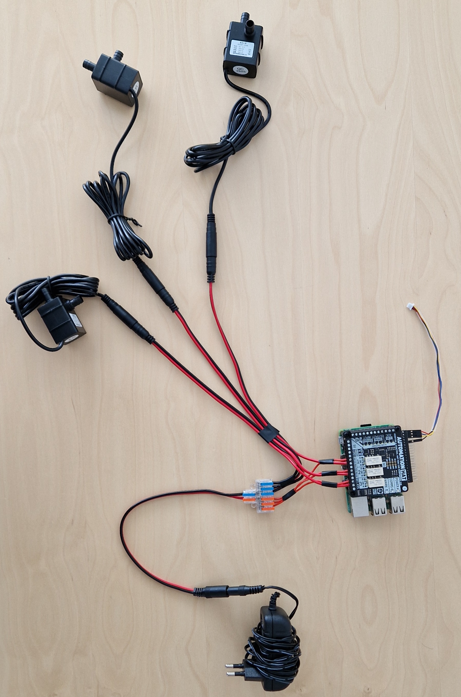
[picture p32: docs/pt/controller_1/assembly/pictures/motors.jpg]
Power board top view
    

A diagram illustrating the connection between pumps, Automation HAT,
and power supply can be seen
[Figure 1](#pt-electrical-schematic-v0.2.0)<!-- markdownlint-disable MD013 -->

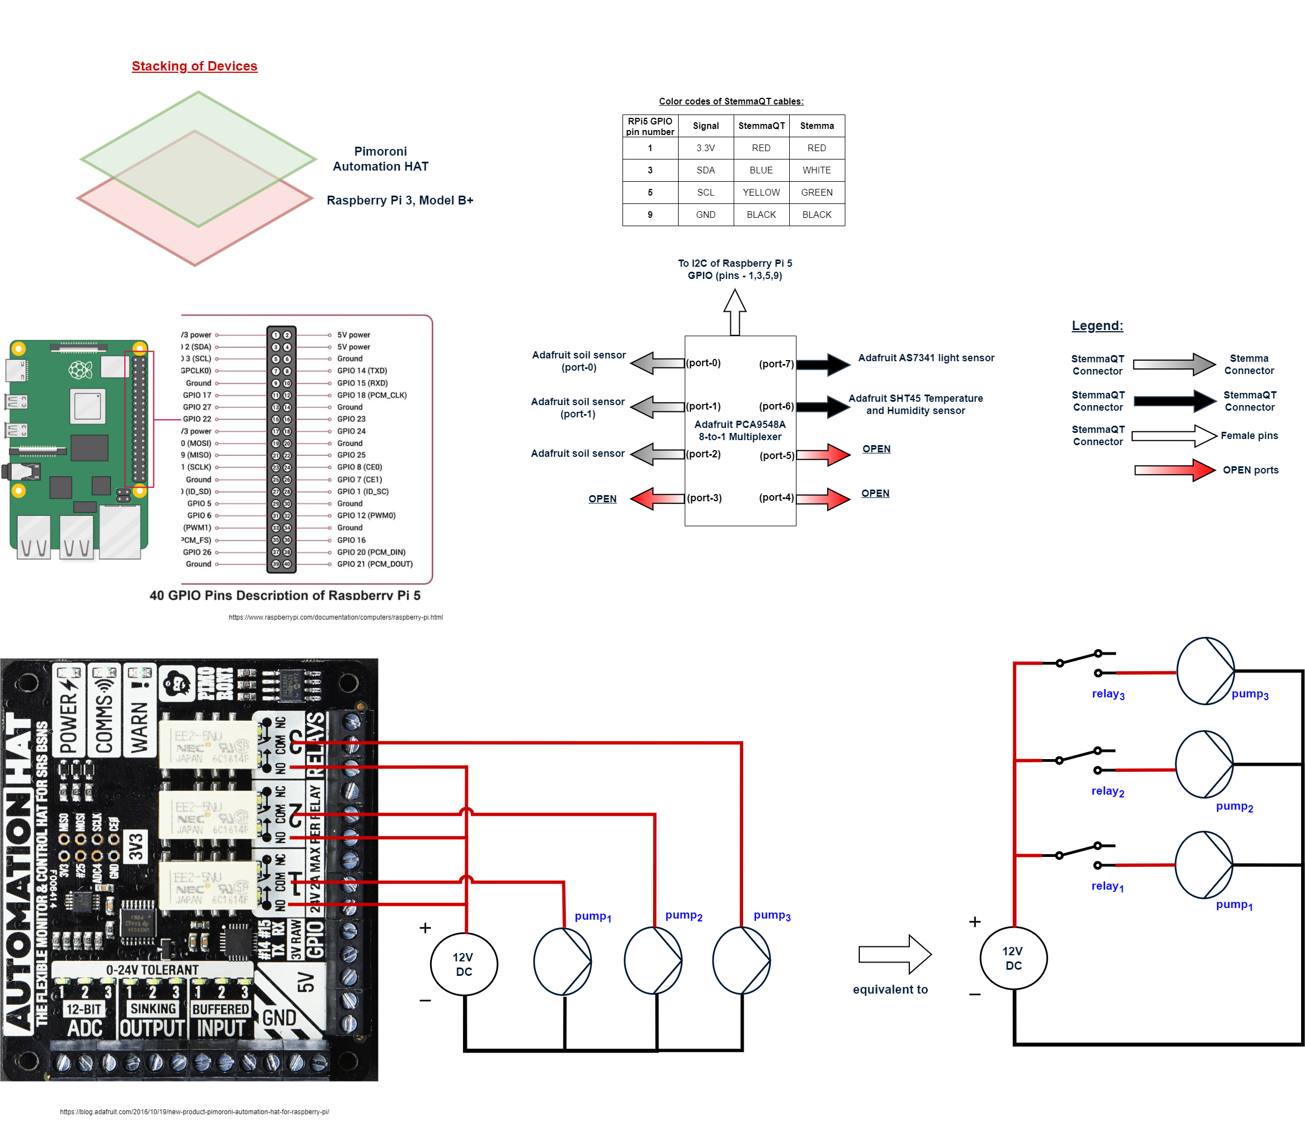
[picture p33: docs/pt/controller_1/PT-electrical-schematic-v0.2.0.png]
PT electrical schematic-v0.2.0


An alternative is to use Raspberry Pi 5 with Pi Juice UPS HAT can also
be assembled. Please see
[Figure 2](#pt-electrical-schematic-v0.1.2)<!-- markdownlint-disable MD013 -->

PT electrical schematic-v0.1.2

### Part 3: Install Raspeberry Pi OS

In this step is installation of the raspberry Pi
Operating System (OS) shown. To do this the following components
and software needed:

1. Raspberry [Pi 5 or 3 B+](../parts/hardware-pictures/Raspberry-Pi-3-Model-BPlus.jpg).
1. 16GB SD card.
1. Raspberry Pi [Imager software](https://www.raspberrypi.com/software/).
1. USB SD card reader.
1. USB keyboard and mouse.
1. HDMI cable and monitor.
1. Power supply for the Raspberry Pi.

4.1 Download the [Raspberry Pi Imager](https://www.raspberrypi.com/software/).

4.2 Install the Raspberry Pi OS on the Raspberry Pi using
    the Raspberry Pi Imager.

4.3 Insert 16GB SD into PC and Open the Raspberry Pi Imager. Then select
    the Raspberry Pi OS software and the SD card to install the software on.
    Press next and follow the steps. See [picture 7](#raspberry-pi-imager).
    <!-- markdownlint-disable MD013 -->
    
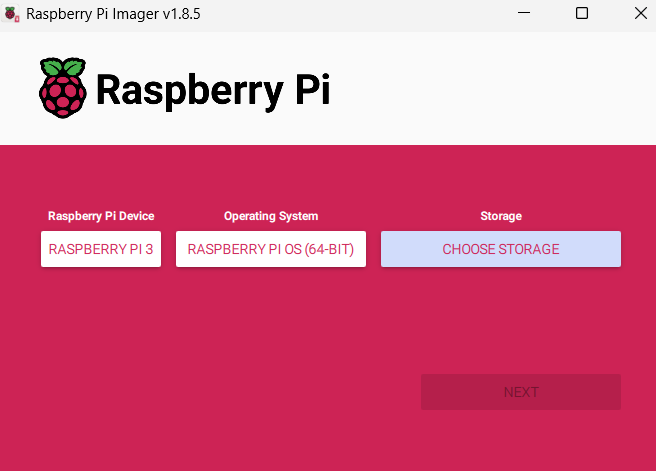
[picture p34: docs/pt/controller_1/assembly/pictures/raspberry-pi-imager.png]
Raspberry Pi Imager
    
    Specifically pick the following options:

- RASPBERRY PI 3 (If you are using another Raspberry Pi, select
  the corresponding one)
- RASPBERRY PI OS (64-bit)
- Choose the 16GB SD card you inserted into the PC.

4.4 After the installation is done, insert the SD card into the Raspberry Pi
    and boot it up. Remember to connect the Raspberry Pi to the au-gadget
    wifi network in the OS instillation process.

### Part 4: Install the required software

5.1 Download the latest
    [release](https://github.com/INTO-CPS-Association/plant-controller/releases)
    of the example plant software.

5.2 Unzip the downloaded file and do the following commands in the terminal:

   ```bash
   cd example-plants/pt/controller_1
   python -m venv controller-1-venv
   source controller-1-venv/bin/activate
   pip install -r requirements.txt
   ```

5.3 To start the PT plant run the following command:

   ```bash
   python controller-1.py
   ```

### Part 5: Assemble components

In this step are all of the compnents used from previoues steps to build
the complete PT plant mockup. This involve the three components built
in the previous steps, namely:

1. Raspberry [Pi 5 / 3 B+](../parts/hardware-pictures/Raspberry-Pi-3-Model-BPlus.jpg)
1. Sensor plate [with sensors connected](pictures/sensors.jpg)
1. Power [board](pictures/motors.jpg)

5.1 Mount the Automation Hat on the Raspberry Pi using the T GPIO stackable
    header using 4x M2.5*6mm spacer, 4x M2.5*6mm stud,
    4x M2.5*8mm stud, 4x M2.5 washer, and 4x M2.5*8mm screw.
    See [picture 8](#pin-connections-view).

5.2 Connect the sensor plate to the Raspberry Pi using the StemmaQT
    connector to Female pins cable (Pints - 1,3,5,9).
    See [picture 8](#pin-connections-view).
    <!-- markdownlint-disable MD013 -->
    
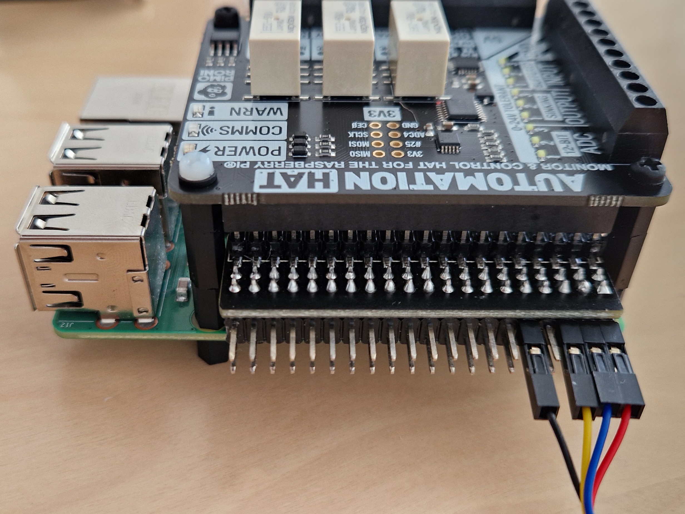
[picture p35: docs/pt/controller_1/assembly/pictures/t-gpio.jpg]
board
    

After mounting the Automation HAT and connecting the sensor plate to
the Raspberry Pi the example plant PT should look like
 [picture 8](#assemble-top-view).

<!-- markdownlint-disable MD013 -->

Assemble top view

## Part 6: InfluxDB and setup

In this step is a guide on how to setup the *InfluxDB* database for
the example plant controller. Specifically creating a new bucket for data
to be stored in and creating a token used to read and write to the bucket.
Measerument from the mockup is stored in the InfluxDB databse, to be used
by the DT and Grafana.

1. Host a local InfluxDB database and login using your credentials.
   The <https://influxdb.foo.com> is used as an example URL to illustrate
   the next steps.

1. After login in, click on **View more** on the **Get Started** page.
   This should take you to the **Load Data** page.

1. Click on **Buckets** the menu bar and click on the **Create Bucket** button.
   Give the bucket a meaningful name.

1. Next create the API token used to read and write to the bucket
   just created. Click on **API Tokens** in the menu bar and click on
   the **Create API Token** button and choose **Costum API Token**.

1. Then selct the bucket you just created and select the **Read/Write**
   permission. This will create a token that can be used to read and
   write to the bucket.

1. Copy the token and then replace `xxxx`and `name-of-bucket` in
   the `controller_1.py` script with the token and name of bucket
   you just created:

   ```python
   org = "your-organization-name"
   url = "https://influxdb.foo.com"
   token="xxxx"
    
   write_client = influxdb_client.InfluxDBClient(url=url, token=token, org=org)
    
   bucket="name-of-bucket"
   ```

For more information about InfluxDB, please see
the [InfluxDB Documentation](https://docs.influxdata.com/).

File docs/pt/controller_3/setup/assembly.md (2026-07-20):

# Assembly

The controller's hardware is logically divided into three groups: the
**Controller** (Raspberry Pi, its PSU and the USB to RS485 dongle), the
**Actuators** (the CS-IO404 relay module, the 12V PSU and the pumps) and the
**Sensor Suite** (the greenhouse and plant sensors). This page walks through
connecting them; for the architecture, block descriptions and the full
port-by-port connection reference, see the
[hardware documentation](../index.md).

The diagram below shows all connections between the modules, and the photo
shows an assembled core.

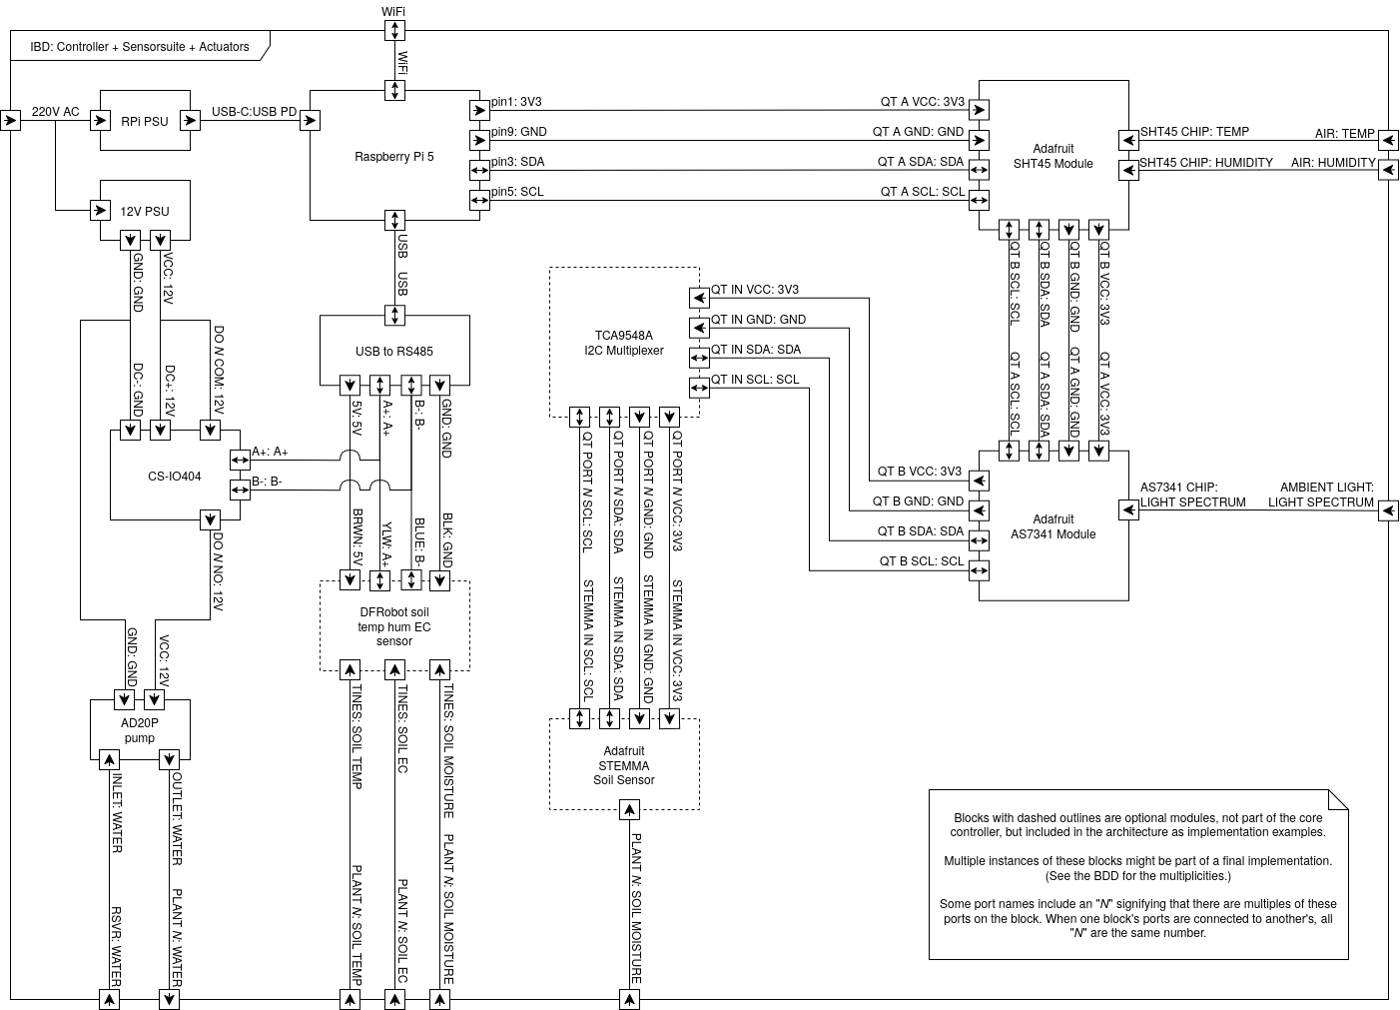
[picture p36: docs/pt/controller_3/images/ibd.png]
Internal block diagram showing how all modules of the controller are connected, internally and with the physical context. Blocks with ports including the letter N can appear multiple times (or not at all) in an implementation.


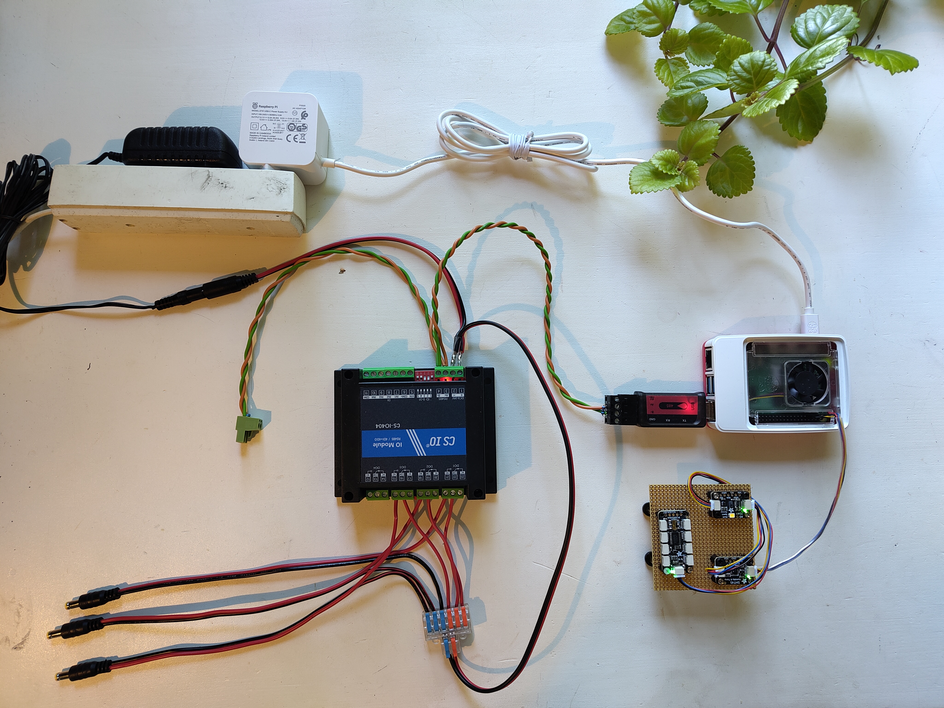
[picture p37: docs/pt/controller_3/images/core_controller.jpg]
The assembled core of the controller: the Raspberry Pi 5, the USB to RS485 dongle, the CS-IO404 relay module, and the SHT45 and AS7341 sensor modules.


This implementation should be seen as an example setup — the wiring should
follow the connections in the diagram, but the wires and connectors used can
be switched for whatever is most useful.

## The I2C bus (greenhouse and STEMMA sensors)

The I2C based modules are connected in a daisy chain, starting from the
Raspberry Pi's GPIO header and continuing from module to module:

1. Connect the STEMMA QT JST SH 4-pin cable to the Raspberry Pi's GPIO pins:
   3.3V to pin 1, GND to pin 9, SDA to pin 3 and SCL to pin 5.
2. Connect it to one of the SHT45 module's QT connectors.
3. Daisy chain from the SHT45 to the AS7341 with a 50 mm STEMMA QT cable.
4. If using STEMMA soil sensors: continue the chain from the AS7341 to the
   TCA9548A multiplexer, then connect each soil sensor to its own multiplexer
   port (a star configuration terminating the chain).

!!! note "QT, Qwiic, STEMMA and JST connectors"
    The connectors between the Adafruit modules are Adafruit "QT" connectors —
    small gauge wires with 4-pin JST SH connectors, also sold as "Qwiic"
    connectors. The STEMMA Soil Sensor's input, however, is a 4-pin JST **PH**
    connector (called a "STEMMA" connector by Adafruit), so each soil sensor
    needs a cable with JST SH in one end and JST PH in the other (such as the
    Sparkfun Qwiic to STEMMA cable in the [parts list](parts.md)).

## The RS485 MODBUS bus (relay and RS485 soil sensors)

The MODBUS based modules all sit on one bus from the USB to RS485 module:

1. Plug the USB to RS485 module into one of the Raspberry Pi's USB ports.
2. Run a twisted pair from the module's A+ and B- terminals; this pair is the
   bus. Connect A+ and B- to the corresponding terminals on the CS-IO404.
3. Connect any DFRobot RS485 soil sensors onto the bus by splitting the cable
   at any point and splicing the sensor's A+ (yellow) and B- (blue) leads onto
   the bus lines. The sensors' power leads (brown to 5V, black to GND) are
   connected to the USB to RS485 module's power terminals — the RS485 soil
   sensors are the only modules powered from the bus.

!!! warning "Signal integrity"
    The A+ and B- wires must be twisted together, otherwise signal integrity
    might be lost. It is also recommended, if not always strictly necessary,
    to add a 120 ohm resistor across each end of the bus — this becomes more
    important the longer the bus gets. In the photo above this is done in the
    output from the USB to RS485 dongle and at the green euroblock connector.

## Power and pumps

The CS-IO404 and the pumps are powered by the 12V PSU (not by the bus):

1. Connect the 12V PSU to the CS-IO404's DC+ and DC- terminals using the DC
   socket from the parts list.
2. For each pump *N*: wire 12V to the relay's DO *N* COM terminal, and wire
   the relay's DO *N* NO terminal and GND to the pump via the DC plug. Each
   relay channel thus switches the 12V supply to one pump.
3. Fit PVC tubing to each pump's outlet, and submerge the pump in the water
   tank. Route the tubing to the plant.

The barrel plugs/sockets can be omitted, but then the plugs from the 12V PSU
and pumps must be snipped off and wired directly into the CS-IO404. This is
not recommended, as it drastically reduces the reusability of the components
when the controller is no longer needed.

Finally, power the Raspberry Pi with its own 27W USB-C PSU.

---

With the hardware assembled, continue to the
[software installation](software.md).

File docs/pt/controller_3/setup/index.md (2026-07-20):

# Setting up Controller 3

Controller 3 (also referred to as the PCtrl) is a plant monitoring and watering
station built around a Raspberry Pi 5 and off-the-shelf, modular peripherals.
It is designed as an easily replicable Physical Twin test kit for research into
Digital Twins: each connected plant can be watered on a schedule or on demand,
and its parameters (along with those of the surrounding greenhouse) are
continuously measured, recorded and exposed over an HTTP REST API for Digital
Twins and modelers to consume.

The controller is intended to be implementable by an electronics novice using
only off-the-shelf hardware — no PCB design or (in the recommended
configuration) soldering is required. Initial implementation and setup of a
controller with two plants, each with one pump and one sensor, is expected to
take no more than 8 hours with all tools and components at hand.

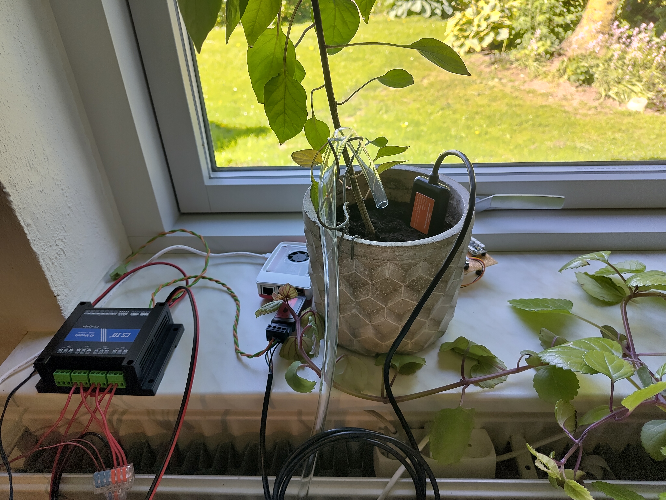
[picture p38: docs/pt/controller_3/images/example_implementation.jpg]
A complete setup of the controller, connected to a Capsicum annuum via a pump and a DFRobot soil sensor.


## Setup overview

Setting up the controller consists of four steps:

1. **[Source your parts](parts.md)** — choose your configuration (number of
   plants, choice of soil sensors) and order the components.
2. **[Assemble the hardware](assembly.md)** — connect the sensors, relay
   module, pumps and Raspberry Pi.
3. **[Install the software](software.md)** — flash the operating system,
   install the database and the plant-controller program, and configure it for
   your plants.
4. **Calibrate and run** — use the built-in setup utility to calibrate pumps
   and sensors, then start the controller (covered at the end of the
   [software guide](software.md)).

## What you'll need

Beyond the parts in the [parts list](parts.md):

- A **secondary computer** for flashing the SD card and SSH'ing into the
  Raspberry Pi.
- An **SD card reader** connectable to the secondary computer (with a micro SD
  adapter if needed).
- A **LAN** (wired or WiFi) in which the Raspberry Pi and the secondary
  computer can reach each other. Alternatively, a USB-C cable can be used with
  the Raspberry Pi's "Gadget mode" for SSH over USB.
- Basic tools: wire stripper/cutter and a small screwdriver for terminal
  blocks. Wiring the RS485 bus involves splicing and twisting wires.

## Further documentation

- [Hardware documentation](../index.md) — architecture, block descriptions and
  the full port-by-port connection reference.
- [Software API Reference](../../../api/plant_controller/index.md) — reference
  documentation for the plant-controller Python package, generated from the
  source code.

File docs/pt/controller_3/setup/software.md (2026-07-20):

# Software installation

The controller software is a Python program (the `plant_controller` package)
which records measurements and watering events in an InfluxDB 3 database.
Both are installed on the Raspberry Pi in this guide, although the database
can also be hosted on another machine — especially recommended when running
the controller on older Raspberry Pis. The software has been tested on a
Raspberry Pi 5 with 4 GB RAM, and is functional on models as early as the
Raspberry Pi 3; a minimum of 2 GB RAM is recommended if the database runs on
the same machine.

For the design and API of the software itself, see the
[Software API Reference](../../../api/plant_controller/index.md).

## 1. Install the operating system

Connect the SD card to your secondary computer and flash the newest version of
**Raspberry Pi OS 64-bit Lite** (version Trixie or later) onto it. The easiest
way to do this is with the [Raspberry Pi Imager](https://www.raspberrypi.com/software/)
(version 2 recommended). In the imager, make sure that:

- SSH is enabled, and
- your WiFi is configured, if the Raspberry Pi must access your LAN
  wirelessly.

(If SSH over USB-C is needed instead, "Gadget mode" must also be enabled —
refer to online guides on Raspberry Pi 5 Gadget mode.)

Insert the SD card into the Raspberry Pi, boot it, SSH into it and ensure that
it is updated:

```bash
sudo apt-get update -y && sudo apt-get upgrade -y
```

## 2. Install the database

The controller uses **InfluxDB 3.0 or later** to store measurements and
watering events.

!!! warning "Raspberry Pi 5 page size"
    The default OS kernel for the Raspberry Pi 5 uses a memory page size of
    16k, but InfluxDB 3 assumes a page size of 4k. Before installing the
    database on a Raspberry Pi 5, switch to the 4k kernel by setting
    `kernel=kernel8.img` in `/boot/firmware/config.txt`:

    ```bash
    echo "kernel=kernel8.img" | sudo tee -a /boot/firmware/config.txt
    sudo shutdown -r now
    ```

    This reboots the Raspberry Pi and terminates the SSH connection — give it
    some time, then reconnect.

Install InfluxDB 3:

```bash
curl -O https://www.influxdata.com/d/install_influxdb3.sh \
&& sh install_influxdb3.sh
```

Choose the local install, and decline when the install script asks whether to
start the server at the end. Then start the server yourself:

```bash
influxdb3 serve --node-id node0
```

With the server running, create the admin token:

```bash
influxdb3 create token --admin
```

Note the token down — it is referred to as `<ADMIN_TOKEN>` below, and is
needed in the controller's config file. Then create the database for the
controller:

```bash
influxdb3 create database --token <ADMIN_TOKEN> --retention-period 7d plant-controller
```

Here the retention period is set to 7 days to avoid gumming up the
controller's persistent storage, and the database name to `plant-controller`,
which is the default in the config file. Both can be changed freely, as long
as the config file is updated accordingly.

!!! note
    The database server does not start automatically. Make sure
    `influxdb3 serve --node-id node0` is running whenever you run the
    controller — for example by running it in a detached terminal
    multiplexer session, or by setting it up as a systemd service.

## 3. Install the controller software

First, get the source code onto the Raspberry Pi, either by cloning it from
GitHub or by SCP'ing it over from the secondary computer:

```bash
git clone https://github.com/DisasterlyDisco/plant-controller.git
```

In the following, `<src>` refers to the full path of the cloned repository.

Install pip and venv support:

```bash
sudo apt-get install -y python3-pip python3-venv
sudo apt install --upgrade python3-setuptools
```

Create a virtual environment (here in the home directory) and activate it:

```bash
cd ~
python -m venv .venv --system-site-packages
source .venv/bin/activate
```

### Adafruit Blinka

Adafruit Blinka provides the Python API for the Raspberry Pi's GPIO header,
which the controller uses for I2C communication with the Adafruit sensor
modules. It cannot simply be installed with pip, as it needs to configure the
machine itself — Adafruit supplies a convenience script:

```bash
cd ~
pip install --upgrade adafruit-python-shell
wget https://raw.githubusercontent.com/adafruit/Raspberry-Pi-Installer-Scripts/master/raspi-blinka.py
sudo -E env PATH=$PATH python3 raspi-blinka.py
```

### Remaining dependencies

With Blinka installed, install the rest of the Python requirements as normal:

```bash
cd <src>/pt/controller_3
pip install -r requirements.txt
```

## 4. Configure the controller

All configuration lives in the `.plant_controller` subdirectory of the user's
home directory. Initialize it from the example implementation shipped with the
source code:

```bash
cp -r <src>/pt/controller_3/impl ~/.plant_controller
mv ~/.plant_controller/config.toml.example ~/.plant_controller/config.toml
```

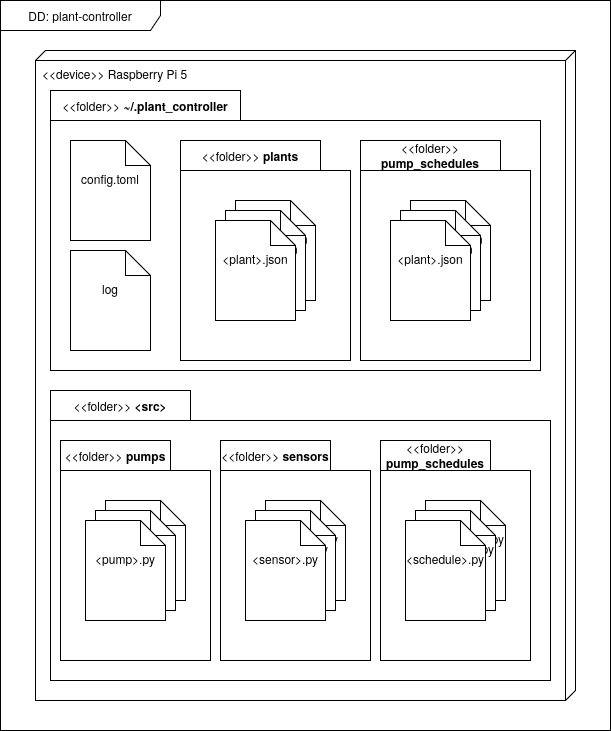
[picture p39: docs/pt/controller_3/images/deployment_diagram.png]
Deployment diagram for the controller's config files and dynamic modules. All config files are located in ~/.plant_controller; dynamically loaded modules live in designated subdirectories of the program source code.


### Main config

Edit `~/.plant_controller/config.toml` and set the `token` value to the
`<ADMIN_TOKEN>` from earlier. If the database name, host or port differ from
the defaults (for instance if the database runs on another machine), update
them here too:

```toml
[database]
name = "plant-controller"
host = "http://127.0.0.1:8181"
token = "<ADMIN_TOKEN>"
```

### Plant configs

Each connected plant gets its own JSON file in
`~/.plant_controller/plants/`, declaring its sensors and its pump. Rename and
adapt the shipped `plant1.json.example` to match your hardware — which sensor
driver module each sensor uses, the I2C addresses or multiplexer ports of
STEMMA sensors, and which relay channel the plant's pump is wired to.

### Pump schedules

Watering schedules live in `~/.plant_controller/pump_schedules/`, one JSON
file per plant (named `<plant_name>.json`), listing watering times and doses
in ml. Schedules can later be updated remotely through the controller's REST
API.

## 5. Calibrate

The controller includes an interactive setup utility for configuring and
calibrating the connected peripherals — most importantly pump calibration,
which ensures that a requested dose in ml translates to the correct pump
running time. Run it from the source directory:

```bash
cd <src>/pt/controller_3/src
python -m plant_controller setup
```

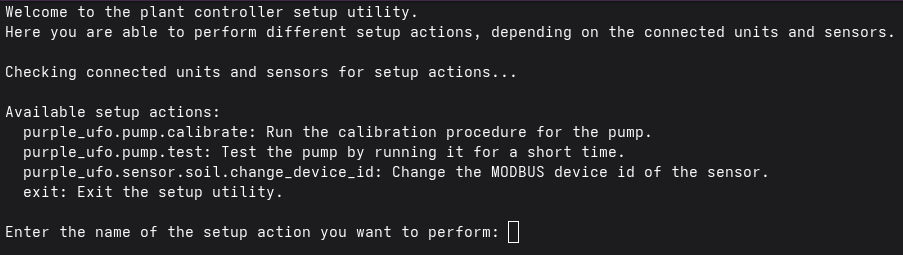
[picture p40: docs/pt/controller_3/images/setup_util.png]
The setup utility's welcome page for a controller with 3 plants, one of which has a DFRobot soil sensor connected.


The available actions are defined by the configured peripherals; follow the
on-screen descriptions.

## 6. Run

With the database server running, start the controller:

```bash
cd <src>/pt/controller_3/src
python -m plant_controller run
```

The controller now monitors and waters the configured plants, and the web
interface is accessible on port 8099 of the Raspberry Pi. For the available
CLI options, run `python -m plant_controller --help`; for the REST API, see
the [web_api reference](../../../api/plant_controller/web_api.md).

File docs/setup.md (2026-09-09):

# Setup
[Quick Start Guide](pt/controller_3/setup/quick_start.md)
[Custom Setup](pt/controller_3/setup/custom_setups.md)

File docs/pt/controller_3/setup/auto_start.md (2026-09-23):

# Auto start
To make the the Plant Controller software start on startup, it is recommended
to use systemd.

This setup assumes that you created the python virtual environment where
instructed in the Quick Start Guide.

First, add a script called `auto_start.sh` to `~/.plant_controller/` containing

```bash
#!/bin/bash

source ~/.venv/bin/activate
~/.influxdb/influxdb3 serve --node-id node0 > /dev/null 2>&1 &
cd <PATH_TO_DIRECOTRY_CONTAINING_PLANT_CONTROLLER_SOURCECODE>
python -m plant_controller --log-level INFO run
```

replacing `<PATH_TO_DIRECOTRY_CONTAINING_PLANT_CONTROLLER_SOURCECODE>`with the
path to the directory containing the `plant_controller` source code directory.

Then, add a file called `plant_controller.service` to `~/.config/systemd/user/`
containing

```
[Unit]
Description=Plant Controller DT/PT interface layer

[Service]
ExecStart=%h/.plant_controller/auto_start.sh

[Install]
WantedBy=default.target
```

This specifies a user service which will run the previous bash script, which in
turn will activate the python virtual environment, start the inlfuxdb3 database
and start the plant_controller software.

User services are not normally un at startup, so this must be enabled by running

```bash
loginctl enable-linger
```

It is also necessary to ensure that the your PATH is available to systemd, so add
`systemctl --user import-environment PATH` to the end of the file `~/.bashrc`.

Finally, enable the service with

```bash
systemctl --user enable plant_controller
```

The plant controller should now automatically run at startup.

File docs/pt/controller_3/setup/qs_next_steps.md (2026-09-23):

# Next steps
Setup auto start for the controller using [systemd](./auto_start.md).

Read sensor data from the plant using the [Web API](../documentation/software/web_api/index.md).

Change how the plant is watered by [updating the watering schedule](../documentation/software/config/watering_schedule.md).

Extend the plant controller to monitor and water [more plants](./adding_plants.md).

Extend the plant controllers sensing capabilities with [custom sensing modules](./custom_sensors.md).

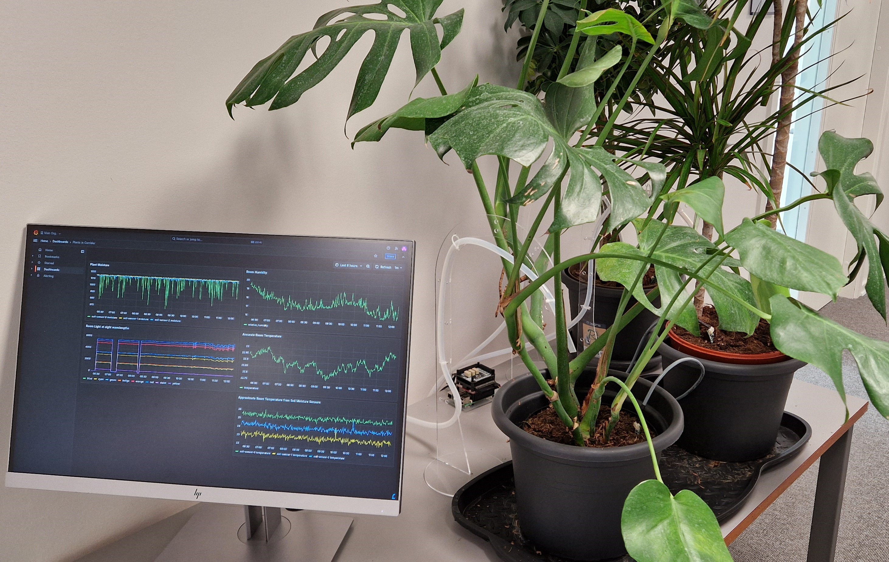
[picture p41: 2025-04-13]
docs/pt/controller_1/installation-1/installation-1_with-plants.jpg

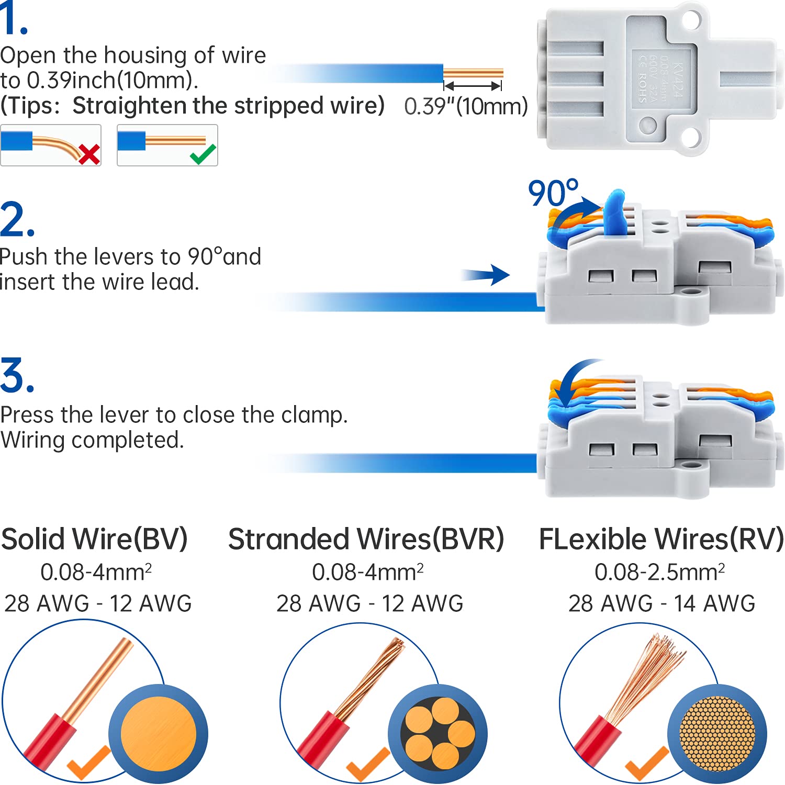
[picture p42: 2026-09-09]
docs/pt/controller_3/documentation/hardware/components/lever_connector_how_to_use.jpg

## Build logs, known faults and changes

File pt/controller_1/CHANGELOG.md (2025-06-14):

# Updates

## 13-June-2025

Adds integration of STOMP client. Now there is an ability to send
water pump turn on instructions from remote STOMP clients which
can be digital twins. This new feature has been tested with
[greenhouse DT](https://github.com/sievericcardo/greenhouse-dt-api).

## 15-May-2025

Removes duplication in controller code and adds better code structure

## 25-April-2025

Separates InfluxDB code from the main controller code.
Updates the configuration file to include the InfluxDB credentials.

## 14-April-2025

Adds assembly instructions and documentation for the controller.
Makes the first public release.

## 28-March-2025

The projects have been renamed from **greenhouse** to **controller**.

## 17-Feb-2025

The demo setup has been updated to include three Adafruit I2C soil sensors,
one temperature and humidity sensors - SHT45;
and light sensor (AS7341). The sensors are connected to Adafruit
PCA9548A (8-ch multiplexer) as follows:

The connections to the ports are:

port 0,1 and 2 --> soil moisture sensors
port 6 --> SHT45 temperature and humidity sensor
port 7 --> AS7341 light sensor

The IoT relay has been replaced with Pimoroni AutomationHAT

With this setup, execute the following commands.

```sh
pip install -r requirements.txt
python controller-1.py
```

The data is being written to InfluxDB database with the following details.

```txt
URL: https://dtl-server-2.st.lab.au.dk
Org: TestUserDTaaS
Bucket: greenhouse-1
```

A Pi Juice UPS has been added to the RPi. As a result, we have
a stack of the following.

* AutomationHAT on top of Pi Juice HAT
* Pi Juice HAT on top of Raspberry Pi 5

## 13-Feb-2025

The green house configuration changed.
The three large plants are being monitored and watered.
The watering is temporarily turned off to monitor the long-term
stability of the code.

## 8-Feb-2025

The small basil plants died. The large large basil plants are still ok.
Moisture sensors 0 and 1 are placed in one plant and
moisture sensors 2 and 3 are placed in another plant

## 3-Feb-2025

The four moisture sensors are placed in four basil plants.
Two large plants and two small plants.
The large plants are large by about 3X vis-a-vis small ones.

## 31-Jan-2025

The demo setup has been updated to include four Adafruit I2C soil sensors,
two temperature and humidity sensors - SH40 and SHT45;
and light sensor (BH1750). The sensors are connected to Adafruit
8-ch multiplexer as follows:

The PCA9548A is connected to I2C pins of RPi 5 using Stemma QT
connector.

The pins are:

1 - RED, 3 - BLUE, 5 - YELLOW, 9 - GND

The Multiplexer is available at port x70 and it has 8 ports.
The connections to the ports are:

port 0,1 and 3 --> soil moisture sensors
port 2 --> faulty soil moisture sensor
port 5 --> SHT45 temperature and humidity sensor
port 7 --> AS7341 light sensor

Also the IoT relay is connected to ports 34 (gnd) and 36 (signal).

With this setup, execute three programs.

1. controller-1 (inside python venv)
1. relay.py (outside python venv)
1. sht_bh_3_moisture_sensors.py (inside python venv)
1. sht_bh_3_moisture_sensors_influxdb.py (inside python venv)

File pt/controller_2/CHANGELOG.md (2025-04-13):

# Updates

## 27-Feb-2025

The demo setup is running with a single motor.
Two soil moisture sensors are connected to Adafruit
8-ch multiplexer as follows:

port 6 and 7 --> soil moisture sensors

With this setup, execute three programs.

1. sensehat.py
2. controller-2.py

The data is being written to InfluxDB database with the following details.

```txt
URL: https://dtl-server-2.st.lab.au.dk
Org: TestUserDTaaS
Bucket: greenhouse-1
```

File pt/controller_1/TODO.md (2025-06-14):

# Pending Tasks

1. Bring out all the scheduling of water pumps into config
1. Test the code.
1. Create PT DevOps using these steps
   1. Create "install", "start", "update" and "stop" scripts for
      plant controller.
      Make the scripts use pm2 npm package
   1. Write manager python script that receives three STOMP messages:
      one per each script and execute them.
   1. Let `.gitlab-ci.yaml` have a release stage that checks for
      commit on "release:latest" branch and sends one of
      the STOMP message
1. Improve the controller to support W3C Thing abstraction so that
   integration with third-party IoT systems is smooth.
1. Release [greenhouse DT](https://github.com/sievericcardo/greenhouse-dt-api)
   with the next release of the plant controller
1. There are three builds of the controller which would enable
   fleet abstraction. The effort in this direction is to identify and
   construct lightweight fleet DT for these three controllers.
1. Better integration with the semantic DT technologies being developed
   in Einar's group.

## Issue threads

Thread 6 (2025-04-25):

Implement services configuration

prasadtalasila, 2025-04-25:
Add support for the following partial configuration.

```toml
[influx2]
url=http://localhost:5672
org=myOrg
bucket=myBucket
token=xxxx

# RabbitMQ configuration
[amqp]
url=localhost:5672
username=guest
password=guest
vhost=/

[plant.1]
properties = [temperature]
action=[water_pump]

[plant.1.temperature]
protocol=i2c
mux_port=0

[plant.1.water_pump]
protocol=i2c
mux_port=0
```

prasadtalasila, 2025-04-26:
It is better to create a separate configuration module to parse this toml file. At the moment, only the InfluxDB configuration will be used but the rabbitmq is to be used soon.

prasadtalasila, 2025-05-14:
PR #10 implements separate `config.py`.  However, this issue is not complete.

prasadtalasila, 2025-06-13:
merged with issue #4

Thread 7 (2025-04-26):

Exceptions in store.py

prasadtalasila, 2025-04-26:
The new [Influx store module](https://github.com/INTO-CPS-Association/plant-controller/blob/883faf787cc61ceb1762acc1c150c642dd1f33c4/pt/controller_1/store.py) fails to catch the network errors. If the wireless network is disconnected, the `controller-1.py` program exits with the following exception.

```log
Exception at: 2025-04-26T16:47:20.134144
Traceback (most recent call last):
  File "/home/dtaas/adafruit/plant-controller-github/pt/controller_1/.venv/lib/python3.11/site-packages/urllib3/connectionpool.py", line 534, in _make_request
    response = conn.getresponse()
               ^^^^^^^^^^^^^^^^^^
.......

  File "/home/dtaas/adafruit/plant-controller-github/pt/controller_1/.venv/lib/python3.11/site-packages/urllib3/connectionpool.py", line 367, in _raise_timeout
    raise ReadTimeoutError(
urllib3.exceptions.ReadTimeoutError: HTTPSConnectionPool(host='dtl-server-2.st.lab.au.dk', port=8086): Read timed out. (read timeout=9.999762313906103)

........

Traceback (most recent call last):
  File "/home/dtaas/adafruit/plant-controller-github/pt/controller_1/controller-1.py", line 325, in <module>
    store_influx.write(record=point)
  File "/home/dtaas/adafruit/plant-controller-github/pt/controller_1/store.py", line 30, in write
    self._write_api.write(bucket=self._bucket, org=self._org, record=record)
....
  File "/home/dtaas/adafruit/plant-controller-github/pt/controller_1/.venv/lib/python3.11/site-packages/urllib3/connection.py", line 205, in _new_conn
    raise NameResolutionError(self.host, self, e) from e
urllib3.exceptions.NameResolutionError: <urllib3.connection.HTTPSConnection object at 0x7ffee6d77950>: Failed to resolve 'dtl-server-2.st.lab.au.dk' ([Errno -3] Temporary failure in name resolution)
```

prasadtalasila, 2025-05-14:
Completed in PR #11

Closed 2025-05-14.

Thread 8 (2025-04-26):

Catching problems with I2C sensors

prasadtalasila, 2025-04-26:
When I2C sensors are disconnected during the execution of `controller-1.py`, the following exception occurs.

```log
Traceback (most recent call last):
  File "/home/dtaas/adafruit/plant-controller-github/pt/controller_1/controller-1.py", line 266, in <module>
    moisture_reading = moisture_0.moisture_read()
                       ^^^^^^^^^^^^^^^^^^^^^^^^^^
  File "/home/dtaas/adafruit/plant-controller-github/pt/controller_1/.venv/lib/python3.11/site-packages/adafruit_seesaw/seesaw.py", line 302, in moisture_read
    self.read(_TOUCH_BASE, _TOUCH_CHANNEL_OFFSET, buf, 0.005)
  .....
  File "/home/dtaas/adafruit/plant-controller-github/pt/controller_1/.venv/lib/python3.11/site-packages/Adafruit_PureIO/smbus.py", line 303, in write_bytes
    self._device.write(buf)
OSError: [Errno 121] Remote I/O error

During handling of the above exception, another exception occurred:

Traceback (most recent call last):
  File "/home/dtaas/adafruit/plant-controller-github/pt/controller_1/.venv/lib/python3.11/site-packages/adafruit_bus_device/i2c_device.py", line 175, in __probe_for_device
    self.i2c.writeto(self.device_address, b"")
  File "/home/dtaas/adafruit/plant-controller-github/pt/controller_1/.venv/lib/python3.11/site-packages/adafruit_tca9548a.py", line 80, in writeto
    return self.tca.i2c.writeto(address, buffer, **kwargs)
           ^^^^^^^^^^^^^^^^^^^^^^^^^^^^^^^^^^^^^^^^^^^^^^^
  File "/home/dtaas/adafruit/plant-controller-github/pt/controller_1/.venv/lib/python3.11/site-packages/busio.py", line 215, in writeto
    return self._i2c.writeto(address, buffer, stop=True)
           ^^^^^^^^^^^^^^^^^^^^^^^^^^^^^^^^^^^^^^^^^^^^^
  File "/home/dtaas/adafruit/plant-controller-github/pt/controller_1/.venv/lib/python3.11/site-packages/adafruit_blinka/microcontroller/generic_linux/i2c.py", line 60, in writeto
    self._i2c_bus.write_bytes(address, buffer[start:end])
  File "/home/dtaas/adafruit/plant-controller-github/pt/controller_1/.venv/lib/python3.11/site-packages/Adafruit_PureIO/smbus.py", line 303, in write_bytes
    self._device.write(buf)
OSError: [Errno 121] Remote I/O error

.....

During handling of the above exception, another exception occurred:

Traceback (most recent call last):
  File "/home/dtaas/adafruit/plant-controller-github/pt/controller_1/controller-1.py", line 304, in <module>
    initialise()
  File "/home/dtaas/adafruit/plant-controller-github/pt/controller_1/controller-1.py", line 121, in initialise
    moisture_0 = Seesaw(tca[5], addr=0x36)
                 ^^^^^^^^^^^^^^^^^^^^^^^^^
  File "/home/dtaas/adafruit/plant-controller-github/pt/controller_1/.venv/lib/python3.11/site-packages/adafruit_seesaw/seesaw.py", line 147, in __init__
    self.i2c_device = I2CDevice(i2c_bus, addr)
                      ^^^^^^^^^^^^^^^^^^^^^^^^
  File "/home/dtaas/adafruit/plant-controller-github/pt/controller_1/.venv/lib/python3.11/site-packages/adafruit_bus_device/i2c_device.py", line 62, in __init__
    self.__probe_for_device()
  File "/home/dtaas/adafruit/plant-controller-github/pt/controller_1/.venv/lib/python3.11/site-packages/adafruit_bus_device/i2c_device.py", line 184, in __probe_for_device
    raise ValueError("No I2C device at address: 0x%x" % self.device_address)
ValueError: No I2C device at address: 0x36
```

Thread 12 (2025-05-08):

Integrate STOMP client

prasadtalasila, 2025-05-08:
The [Oslo greenhouse actuator](https://github.com/MarcoAmato/greenhouse_actuator) code receives STOMP protocol messages and waters the plants. The existing plant controller needs to have the same capability. The configuration proposed in PR #10 needs to be enhanced to map from plant number to pin number received on the STOMP protocol message.

prasadtalasila, 2025-05-15:
#### Comment by Mikkel

I have looked at the STOMP client issue. I have copied the subscriber.py file and added the following to the config.yaml.template file

``` yaml
external:
    stomp:
      actuator_id: [1, 2, 3]
      URL: "localhost.com"
      USER: "admin"
      PASS: "admin"
```

Am i going to add the connection part to STOMP inside the controller-1.py, such that it automatically connects if settings are given in the config.yaml? like the things they have is in their __main__.py?

prasadtalasila, 2025-05-15:
No. Please add new `comm.py` in which you can add the STOMP client.
The client should take a callback hook (function) as argument. This callback  can be  `water_pump`.

prasadtalasila, 2025-05-15:
You can bring out the water pumps code into `pumps.py` as a preparatory step. The necessary logic to map the local pump numbers to pin numbers / actuator IDs coming as STOMP messages can also be placed as a function inside `pumps.py`.

prasadtalasila, 2025-05-15:
You can add a new function in `config.py` to map the actuator ID. The suggested config is

```yaml
  actuators:
    pump_1:
      id: 1
      schedule: "10:15"
    pump_2:
      id: 1
      schedule: "14:30"
    pump_3:
      id: 1
      schedule: "10:15"
```

prasadtalasila, 2025-05-19:
If we only need include the pump pin, the configuration could be changed to

```yaml
  actuators:
    pump_1:
      pin: 1
      schedule: "10:15"
    pump_2:
      pin: 2
      schedule: "14:30"
    pump_3:
      pin: 3
      schedule: "10:15"
```

prasadtalasila, 2025-05-20:
Some STOMP servers and clients

BEST server: RabbitMQ with STOMP plugin

Other servers: [coilmq](https://github.com/hozn/coilmq/wiki/Getting-Started)
Other clients: [stomp.py](https://github.com/jasonrbriggs/stomp.py)

Ref: https://stomp.github.io/implementations.html

prasadtalasila, 2025-06-03:
STOMP client subscription in anycast mode

```python
                self.conn.subscribe(
                    destination=queue_destination,
                    id=index,
                    ack="auto",
                    headers={"activemq.subscriptionName": f"anycast-{index}", "subscription-type": "ANYCAST"}
                )

```

prasadtalasila, 2025-06-13:
PR #13 completes the task

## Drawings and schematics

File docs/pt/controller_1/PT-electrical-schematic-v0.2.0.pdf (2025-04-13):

### Pimoroni Automation HAT

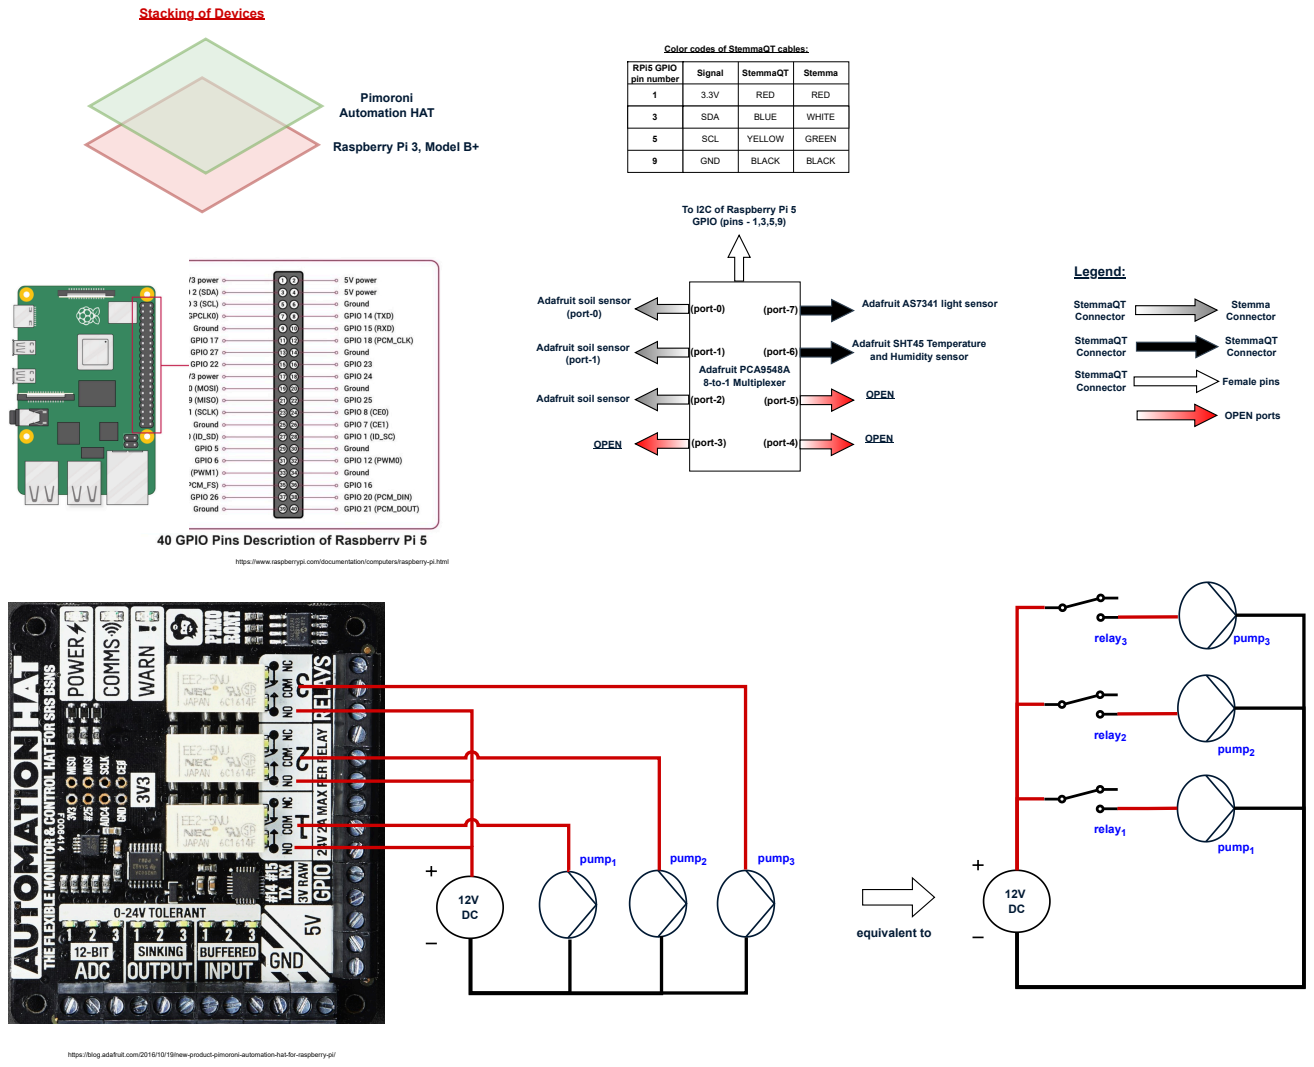
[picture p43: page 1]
RPi5 GPIO pin number; GND3; Signal; StemmaQT; Stemma; RED; SDA; BLUE; WHITE; SCL; YELLOW; GREEN; GND; BLACK; equivalent to; pump1; pump2; pump3; relay1; relay2; relay3; (port-3); (port-5); (port-4); Adafruit PCA9548A 8-to-1 Multiplexer; OPEN; OPEN (port-2); (port-1); (port-0); (port-7); (port-6); StemmaQT Connector; Stemma Connector; Female pins; OPEN ports; Legend:

Stacking of Devices

Color codes of StemmaQT cables:

Raspberry Pi 3, Model B+

To I2C of Raspberry Pi 5
GPIO (pins - 1,3,5,9)

Adafruit soil sensor
(port-0)

Adafruit AS7341 light sensor

Adafruit SHT45 Temperature
and Humidity sensor

(port-1)

https://www.raspberrypi.com/documentation/computers/raspberry-pi.html

https://blog.adafruit.com/2016/10/19/new-product-pimoroni-automation-hat-for-raspberry-pi/

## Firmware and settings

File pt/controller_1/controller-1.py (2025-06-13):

from datetime import datetime
from schedule import every, repeat
import schedule

import adafruit_sht4x
import adafruit_tca9548a
from adafruit_as7341 import AS7341
from adafruit_seesaw.seesaw import Seesaw
import automationhat
import board
import os, time
from influxdb_client import Point
from typing import Sequence, Tuple, Any
import yaml

from store import InfluxDBStore

from config import (
    precision_map,
    get_config,
    get_sensor_sampling_period,
    get_moisture_sensor_port,
    get_moisture_sensor_addr,
    get_sht45_port,
    get_sht45_mode,
    get_as7341_port,
    get_actuator_shedule,
    RESTART_DELAY
)
from pump import water_plant, water_plant_1, water_plant_2, water_plant_3

store_influx = InfluxDBStore()

from comm import stompClient


def create_point(measurements: dict) -> Point:
    """Create a point for the measurement.
    Args:
        measurements (dict): A dictionary containing the measurement data.
        The dictionary should have a "name" key for the measurement name
        and other keys for the measurement fields.
    Returns:
        Point: An InfluxDB Point object with the measurement data.
    """
    point = Point(measurements["name"])
    for key, value in measurements.items():
        if key != "name":
            point.field(key, value)
    return point


def print_sht45_measurements(measurements: dict) -> None:
    """Print the SHT45 temperature and humidity measurements."""
    print(
        f"SHT45 --> Temperature: {measurements['temperature']:0.1f} C, Humidity: {measurements['relative_humidity']:0.1f} %"
    )


def print_as7341_measurements(measurements: dict) -> None:
    """Print the AS7341 light sensor measurements."""
    print("AS7341 light sensor: 415nm wavelength (Violet)  %s" % measurements["violet"])
    print("AS7341 light sensor: 445nm wavelength (Indigo) %s" % measurements["indigo"])
    print("AS7341 light sensor: 480nm wavelength (Blue)   %s" % measurements["blue"])
    print("AS7341 light sensor: 515nm wavelength (Cyan)   %s" % measurements["cyan"])
    print("AS7341 light sensor: 555nm wavelength (Green)   %s" % measurements["green"])
    print("AS7341 light sensor: 590nm wavelength (Yellow)  %s" % measurements["yellow"])
    print("AS7341 light sensor: 630nm wavelength (Orange)  %s" % measurements["orange"])
    print("AS7341 light sensor: 680nm wavelength (Red)     %s" % measurements["red"])


def print_soil_sensor_measurements(measurements: dict) -> None:
    """Print the soil sensor measurements."""
    print(
        f"{measurements['name']} --> Moisture: {measurements['moisture']:0.1f}, Temperature: {measurements['temperature']:0.1f} C"
    )


def create_exception_point(e: Exception) -> Point:
    """Create a point for the exception measurement."""
    point = Point("exception").field("status", 0)
    return point


def initialise() -> Sequence[Any]:
    """Initializes the sensor objects for the TCA9548A multiplexer."""

    # Get the moisture sensor port numbers
    port_moisture_0 = get_moisture_sensor_port(sensor_key="moisture_0")
    port_moisture_1 = get_moisture_sensor_port(sensor_key="moisture_1")
    port_moisture_2 = get_moisture_sensor_port(sensor_key="moisture_2")

    # Get the moisture sensor addresses
    addr_moisture_0 = get_moisture_sensor_addr(sensor_key="moisture_0")
    addr_moisture_1 = get_moisture_sensor_addr(sensor_key="moisture_1")
    addr_moisture_2 = get_moisture_sensor_addr(sensor_key="moisture_2")

    # Get the port for the SHT45 sensor
    port_sht45 = get_sht45_port()

    # Get the mode string for the SHT45 sensor
    mode_str_sht45 = get_sht45_mode()

    # Get the port number for the AS7341 sensor
    port_as7341 = get_as7341_port()

    # Create I2C bus as normal
    i2c = board.I2C()  # uses board.SCL and board.SDA

    # Create the TCA9548A object and give it the I2C bus
    tca = adafruit_tca9548a.TCA9548A(i2c)

    # For each sensor, create it using the TCA9548A channel instead of the I2C object
    # moisture sensor with temperature sensing capabilities
    moisture_0 = Seesaw(tca[port_moisture_0], addr=addr_moisture_0)
    moisture_1 = Seesaw(tca[port_moisture_1], addr=addr_moisture_1)
    moisture_2 = Seesaw(tca[port_moisture_2], addr=addr_moisture_2)

    # SHT45 is a temperature and humidity sensor
    sht45 = adafruit_sht4x.SHT4x(tca[port_sht45])

    if mode_str_sht45 in precision_map:
        # Set the sensor mode based on the string value
        mode_value = precision_map[mode_str_sht45]
        sht45.mode = mode_value
    else:
        raise ValueError(f"Invalid mode string: {mode_str_sht45}")

    # Can also set the mode to enable heater
    # sht45.mode = adafruit_sht4x.Mode.LOWHEAT_100MS
    print("Current mode for SHT45 is: ", adafruit_sht4x.Mode.string[sht45.mode])

    # AS7341 is a ten-channel (eight color) light sensor
    light_sensor = AS7341(tca[port_as7341])

    return moisture_0, moisture_1, moisture_2, sht45, light_sensor


def initialise_actuators() -> None:
    """Initializes the actuators."""

    # Get actuator configuration from the config file
    schedule_pump_1 = get_actuator_shedule(pump_key="pump_1")
    schedule_pump_2 = get_actuator_shedule(pump_key="pump_2")
    schedule_pump_3 = get_actuator_shedule(pump_key="pump_3")

    # Set the schedule for the actuators
    if schedule_pump_1:
        every().monday.at(schedule_pump_1).do(
            lambda: water_plant_1(store_influx=store_influx)
        )
        every().wednesday.at(schedule_pump_1).do(
            lambda: water_plant_1(store_influx=store_influx)
        )
        every().friday.at(schedule_pump_1).do(
            lambda: water_plant_1(store_influx=store_influx)
        )
    if schedule_pump_2:
        # Set the schedule for pump 2
        every().day.at(schedule_pump_2).do(
            lambda: water_plant_2(store_influx=store_influx)
        )
    if schedule_pump_3:
        # Set the schedule for pump 3
        every().monday.at(schedule_pump_3).do(
            lambda: water_plant_3(store_influx=store_influx)
        )
        every().wednesday.at(schedule_pump_3).do(
            lambda: water_plant_3(store_influx=store_influx)
        )
        every().friday.at(schedule_pump_3).do(
            lambda: water_plant_3(store_influx=store_influx)
        )


def readings(moisture_0, moisture_1, moisture_2, sht45, light_sensor):
    print(f"Sample at: {datetime.now().isoformat()}")
    temperature, relative_humidity = sht45.measurements
    # Create a dict from the measurements
    measurements = {
        "name": "sht45",
        "temperature": temperature,
        "relative_humidity": relative_humidity,
    }
    print_sht45_measurements(measurements=measurements)
    point = create_point(measurements=measurements)
    store_influx.write(record=point)

    # Create a dict from the measurements
    measurements = {
        "name": "as7341",
        "violet": light_sensor.channel_415nm,
        "indigo": light_sensor.channel_445nm,
        "blue": light_sensor.channel_480nm,
        "cyan": light_sensor.channel_515nm,
        "green": light_sensor.channel_555nm,
        "yellow": light_sensor.channel_590nm,
        "orange": light_sensor.channel_630nm,
        "red": light_sensor.channel_680nm,
    }
    print_as7341_measurements(measurements=measurements)
    point = create_point(measurements=measurements)
    store_influx.write(record=point)

    moisture_reading = moisture_0.moisture_read()
    temperature_reading = moisture_0.get_temp()
    # Create a dict from the measurements
    measurements = {
        "name": "soil-sensor-0",
        "moisture": moisture_reading,
        "temperature": temperature_reading,
    }
    point = create_point(measurements=measurements)
    print_soil_sensor_measurements(measurements=measurements)

    store_influx.write(record=point)

    moisture_reading = moisture_1.moisture_read()
    temperature_reading = moisture_1.get_temp()
    # Create a dict from the measurements
    measurements = {
        "name": "soil-sensor-1",
        "moisture": moisture_reading,
        "temperature": temperature_reading,
    }
    point = create_point(measurements=measurements)
    print_soil_sensor_measurements(measurements=measurements)

    store_influx.write(record=point)

    moisture_reading = moisture_2.moisture_read()
    temperature_reading = moisture_2.get_temp()
    # Create a dict from the measurements
    measurements = {
        "name": "soil-sensor-2",
        "moisture": moisture_reading,
        "temperature": temperature_reading,
    }
    point = create_point(measurements=measurements)
    print_soil_sensor_measurements(measurements=measurements)

    store_influx.write(record=point)

    print("")


if __name__ == "__main__":
    # Initialize the actuators
    initialise_actuators()
    # Initialize the sensors
    moisture_0, moisture_1, moisture_2, sht45, light_sensor = initialise()

    # reading interval
    # Set up schedule for sensors
    sampling_period = get_sensor_sampling_period()
    if sampling_period:
        pass
    else:
        raise ValueError(
            f"No sampling_period given in config file for sensors: {sampling_period}"
        )

    # Create STOMP client
    stomp_client = stompClient(
        lambda relay, duration, pump_id: water_plant(
            store_influx=store_influx, pump_id=pump_id, relay=relay, duration=duration
        )
    )

    print("init done")

    while True:
        try:
            readings(moisture_0, moisture_1, moisture_2, sht45, light_sensor)

            # time.sleep(5)
            # raise Exception("I2C device error")

        except Exception as e:
            time.sleep(RESTART_DELAY)
            moisture_0, moisture_1, moisture_2, sht45, light_sensor = initialise()
            print(f"Exception at: {datetime.now().isoformat()}")

            point = create_exception_point(e)
            store_influx.write(record=point)
            continue

        # water the plants if needed
        schedule.run_pending()
        time.sleep(sampling_period)

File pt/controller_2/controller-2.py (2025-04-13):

from datetime import datetime
import time
import schedule
from gpiozero import LED

import adafruit_tca9548a
from adafruit_seesaw.seesaw import Seesaw
import board
import influxdb_client, os, time
from influxdb_client import InfluxDBClient, Point, WritePrecision
from influxdb_client.client.write_api import SYNCHRONOUS

org = "influx-org"
url = "https://influx.foo.com"
token="xxx"

write_client = influxdb_client.InfluxDBClient(url=url, token=token, org=org)

bucket="controller-2"

write_api = write_client.write_api(write_options=SYNCHRONOUS)

# Relay Channels are active low which means
#ON - turns off the output
#OFF - turns on the output

pump_1 = LED(26)
pump_2 = LED(20)
pump_3 = LED(21)
pump_1.on()
pump_2.on()
pump_3.on()

def water_plants():
    pump_1.off()
    print(f"pumps turned on at: {datetime.now().isoformat()}")
    point = (
        Point("pump-1")
        .field("status", 1)
    )
    write_api.write(bucket=bucket, org=org, record=point)

    time.sleep(5)
    
    pump_1.on()
    print(f"pumps turned off at: {datetime.now().isoformat()}")
    point = (
        Point("pump-1")
        .field("status", 0)
    )
    write_api.write(bucket=bucket, org=org, record=point)


def initialise():
    # Create I2C bus as normal
    i2c = board.I2C()  # uses board.SCL and board.SDA

    # Create the TCA9548A object and give it the I2C bus
    tca = adafruit_tca9548a.TCA9548A(i2c)

    # For each sensor, create it using the TCA9548A channel instead of the I2C object
    # moisture sensor with temperature sensing capabilities
    moisture_0 = Seesaw(tca[6], addr=0x36)
    moisture_1 = Seesaw(tca[7], addr=0x36)

def readings():

    moisture_reading = moisture_0.moisture_read()
    temperature_reading = moisture_0.get_temp()
    print(f"Soil sensor-0 --> Moisture: {moisture_reading:0.1f}, Temperature: {temperature_reading:0.1f} C")
    point = (
        Point("soil-sensor-0")
        .field("moisture", moisture_reading)
        .field("temperature", temperature_reading)
    )
    write_api.write(bucket=bucket, org=org, record=point)
    
    moisture_reading = moisture_1.moisture_read()
    temperature_reading = moisture_1.get_temp()
    print(f"Soil sensor-1 --> Moisture: {moisture_reading:0.1f}, Temperature: {temperature_reading:0.1f} C")
    point = (
        Point("soil-sensor-1")
        .field("moisture", moisture_reading)
        .field("temperature", temperature_reading)
    )
    write_api.write(bucket=bucket, org=org, record=point)

    print("")


if __name__ == "__main__":
    # Create I2C bus as normal
    i2c = board.I2C()  # uses board.SCL and board.SDA

    # Create the TCA9548A object and give it the I2C bus
    tca = adafruit_tca9548a.TCA9548A(i2c)

    # For each sensor, create it using the TCA9548A channel instead of the I2C object
    # moisture sensor with temperature sensing capabilities
    moisture_0 = Seesaw(tca[6], addr=0x36)
    moisture_1 = Seesaw(tca[7], addr=0x36)

    print("init done") 

    # Schedule the plant watering job
    schedule.every(1).minutes.do(water_plants)
    #schedule.every().day.at("10:00").do(water_plants)

    while True:
        try:
            print(f"Sample at: {datetime.now().isoformat()}")

            moisture_reading = moisture_0.moisture_read()
            temperature_reading = moisture_0.get_temp()
            print(f"Soil sensor-0 --> Moisture: {moisture_reading:0.1f}, Temperature: {temperature_reading:0.1f} C")
            point = (
                Point("soil-sensor-0")
                .field("moisture", moisture_reading)
                .field("temperature", temperature_reading)
            )
            write_api.write(bucket=bucket, org=org, record=point)
            
            moisture_reading = moisture_1.moisture_read()
            temperature_reading = moisture_1.get_temp()
            print(f"Soil sensor-1 --> Moisture: {moisture_reading:0.1f}, Temperature: {temperature_reading:0.1f} C")
            point = (
                Point("soil-sensor-1")
                .field("moisture", moisture_reading)
                .field("temperature", temperature_reading)
            )
            write_api.write(bucket=bucket, org=org, record=point)

            print("")

        except Exception as e:
            initialise()
            print(f"Exception at: {datetime.now().isoformat()}")
            point = (
                Point("exception")
                .field("status", 0)
            )
            write_api.write(bucket=bucket, org=org, record=point)
            time.sleep(5)
            continue

        # water the plants if needed
        schedule.run_pending()
        time.sleep(60)

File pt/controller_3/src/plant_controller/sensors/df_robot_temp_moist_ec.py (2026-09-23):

"""DFRobot RS485 soil temperature, humidity, and EC sensor implementation.

Reads soil moisture (%RH), temperature (°C), and electrical conductivity
(μS/cm) from a DFRobot RS485/MODBUS soil sensor. Communication uses MODBUS
RTU holding registers.

Each physical sensor has a configurable MODBUS device ID (2–253). Sensors
ship with a default ID of 1, which should be changed before deployment to
avoid address collisions. The ``change_id`` setup action handles this.

Config kwargs:
    device_id: MODBUS device ID of the sensor (2–253 recommended).
    tbr: Time between reads in seconds.
"""

import logging
_logger = logging.getLogger(__name__)

from typing import Any, Callable

import anyio

from . import Sensor
from ..datapoint import Datapoint, Measurement
from ..cli_helpers import clear_screen
from ..com_bus import MODBUS, MODBUSInterface
from ..setup_actions import HasSetupFunctionsMixin

_DEFAULT_DF_HUM_TEMP_EC_ID=1
_DF_HUM_TEMP_EC_MOISTURE_ADDRESS=0x0000
_DF_HUM_TEMP_EC_TEMPERATURE_ADDRESS=0x0001
_DF_HUM_TEMP_EC_CONDUCTIVITY_ADDRESS=0x0002
_DF_HUM_TEMP_EC_ID_ADDRESS=0x07D0

class DFRobotRS485SoilTemperatureHumidityECSensor(Sensor, MODBUSInterface, HasSetupFunctionsMixin):
    """DFRobot RS485 soil sensor measuring moisture, temperature, and EC.

    Communicates over MODBUS RTU, reading three holding registers per
    measurement cycle. Reports three sub-parameters named
    ``<parameter>.moisture``, ``<parameter>.temperature``, and
    ``<parameter>.electrical_conductivity``.

    This sensor includes a setup action (``change_device_id``) for
    reassigning the sensor's MODBUS address, which is necessary before
    deploying multiple sensors on the same bus.

    Attributes:
        parameter: Base parameter name (sub-parameters are derived from it).
        bus: The MODBUS bus instance used for communication.
        db_save_function: Async callable for persisting measurements.
        config_save_function: Callable for saving config changes to disk.
        device_id: MODBUS device address of this sensor.
        time_between_reads: Interval between measurement cycles (seconds).
    """

    def __init__(
        self,
        parameter: str,
        bus: MODBUS,
        db_save_function: Callable[[Datapoint | list[Datapoint]], None],
        config_save_function: Callable,
        device_id: int,
        tbr: int,
        **_kwargs: Any
    ):
        """Initialize the DFRobot soil sensor.

        Args:
            parameter: Base name for the measured parameters (e.g. 'soil').
            bus: MODBUS bus instance for register reads/writes.
            db_save_function: Async function to persist measurements to the DB.
            config_save_function: Callable for saving config changes (e.g.
                updated device_id) back to the plant's JSON config file.
            device_id: MODBUS device address (2–253 recommended; 1 is the
                factory default and triggers a warning).
            tbr: Time between reads in seconds.
            **_kwargs: Ignored; allows forward-compatible config expansion.
        """
        self.parameter = parameter
        self.bus = bus
        self.db_save_function = db_save_function
        self.config_save_function = config_save_function
        self.device_id = device_id
        self.time_between_reads = tbr
        if self.device_id == _DEFAULT_DF_HUM_TEMP_EC_ID:
            _logger.warning(f"DF Robot RS485 Soil Temperature Humidity EC Sensor, parameter '{self.parameter}' is configured with default device id {_DEFAULT_DF_HUM_TEMP_EC_ID}. This should be changed to an other non default value (2-253) in setup before running the controller.")
    
    async def read(self):
        """Read moisture, temperature, and EC registers and save as Measurements.

        The blocking MODBUS register reads are offloaded to a worker thread
        to avoid stalling the async event loop.
        """
        def _blocking_read():
            _logger.debug(f"Fetching readings from sensor [{self.parameter}]")
            try:
                return [
                    Measurement(
                        parameter=f"{self.parameter}_moisture",
                        value=self.bus.convert_from_registers(
                            registers=self.bus.read_holding_registers(
                                address=_DF_HUM_TEMP_EC_MOISTURE_ADDRESS,
                                device_id=self.device_id
                            ).registers,
                            data_type=self.bus.DATATYPE.UINT16
                        ) / 10,
                        units="%RH"
                    ),
                    Measurement(
                        parameter=f"{self.parameter}_temperature",
                        value=self.bus.convert_from_registers(
                            registers=self.bus.read_holding_registers(
                                address=_DF_HUM_TEMP_EC_TEMPERATURE_ADDRESS,
                                device_id=self.device_id
                            ).registers,
                            data_type=self.bus.DATATYPE.INT16
                        ) / 10,
                        units="°C"
                    ),
                    Measurement(
                        parameter=f"{self.parameter}_electrical_conductivity",
                        value=self.bus.convert_from_registers(
                            registers=self.bus.read_holding_registers(
                                address=_DF_HUM_TEMP_EC_CONDUCTIVITY_ADDRESS,
                                device_id=self.device_id
                            ).registers,
                            data_type=self.bus.DATATYPE.UINT16
                        ),
                        units="μS/cm"
                    )
                ]
            except Exception as e:
                _logger.error(f"Failed to fetch sensor values for parameter [{self.parameter}]: {e}")
                raise e
        _logger.debug(f"Starting blocking sensing for parameter [{self.parameter}] in seperate thread.")
        measurements = await anyio.to_thread.run_sync(_blocking_read)
        _logger.debug(f"Saving for parameter [{self.parameter}] in database the measurements {measurements}")
        self.db_save_function(measurements)

    def get_capabilities(self):
        """Return capabilities for the three sub-parameters.
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

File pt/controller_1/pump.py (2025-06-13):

from datetime import datetime
import time
import automationhat
from influxdb_client import Point
from store import InfluxDBStore

from config import (
  get_relay_by_pump_id,
  get_pump_config)


def create_pump_point(pump_id: str, status: int) -> Point:
    """Create a point for the pump measurement."""
    point = Point(f"{pump_id}").field("status", status)
    return point


def water_plant(store_influx: InfluxDBStore, pump_id: str, relay, duration: int):
    """
    Activates a pump for a specified duration and logs the status to InfluxDB.

    Args:
        pump_id (str): The ID of the pump (e.g., "1", "2", "3").
        relay: The relay object to control the pump.
        duration (int): The duration in seconds to keep the pump on.
    """
    relay.on()
    print(f"{pump_id} turned on at: {datetime.now().isoformat()}")
    point = create_pump_point(pump_id=pump_id, status=1)
    store_influx.write(record=point)

    time.sleep(duration)

    relay.off()
    print(f"{pump_id} turned off at: {datetime.now().isoformat()}")
    point = create_pump_point(pump_id=pump_id, status=0)
    store_influx.write(record=point)


# Update the specific plant watering functions to use the refactored function
def water_plant_1(store_influx: InfluxDBStore):
    water_plant(
        store_influx,
        pump_id="pump_1",
        relay=automationhat.relay.one,
        duration=get_pump_config("pump_1").get("on_duration", 15)
    )


def water_plant_2(store_influx: InfluxDBStore):
    water_plant(
        store_influx,
        pump_id="pump_2",
        relay=automationhat.relay.two,
        duration=get_pump_config("pump_2").get("on_duration", 6)
    )


def water_plant_3(store_influx: InfluxDBStore):
    water_plant(
        store_influx,
        pump_id="pump_3",
        relay=automationhat.relay.three,
        duration=get_pump_config("pump_1").get("on_duration", 10)
    )

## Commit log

2025-01-26 adds example code to pt and pt schematics to docs
2025-01-31 Adds code for all sensors
    All the required sensors for the plants are connected.
2025-02-10 Adds demo and schematics for first greenhouse
    - Adds working demo for first green house
    - Adds physical and electrical schematics for
    the greenhouse
    - Adds the system architecture for greenhouses
2025-02-11 Restructures code and adds docs
    - Adds documentation on the current status of greenhouses
    - Moves code into first green house
2025-02-21 Updates the status on greenhouse 1 case study
2025-04-13 Improves controller-1 docs and restructures codebase (#3)
    - Restructures code base to remove reference to greenhouse
    - Adds documentation for controller-1 and improves
    overall documentation
    - Fixes minor mistake in controller-1.py code
    ---------
    [Controller-cover.stp, RaspberryPi-Base-Plate.stp, Sensor-mount-plate.stp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]
2025-05-14 Catches network errors for InfluxDB calls (#11)
    [store.py]
2025-05-14 Removes code duplication in controller 1 (#10)
    - Removes duplicate code from plant controller-1
    - Refactors data storage code
    - Extends configuration to soil sensor and motor connection ports
    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
2025-06-13 Integrates a STOMP client and updates config (#13)
    - Integrates STOMP controller to receive pump
    turn on messages.
    - Updates configuration files to include the
    STOMP broker details
    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
    [comm.py, config.py, controller-1.py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]
2026-07-20 Adds third iteration of the plant controller (#15)
    - New pt/controller_3 package: units, sensors, pumps, schedules, DB layer, FastAPI web API
    - Integration of InfluxDB3 edge database
    - Dynamic sensor/schedule loading over I2C and MODBUS
    - Documentation site (Zensical + mkdocstrings) with API stub generator
    - Extensive Controller 3 setup/hardware docs; fixes to Controller 1/2 docs and assets
    [Controller-cover.stp, RaspberryPi-Base-Plate.stp, Sensor-mount-plate.stp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]
2026-09-23 Updates to documentation, watering schedule representation consistency (#17)
    - Updates documentation for controller_3
    - Sensors can now update their own config, and project now includes a default module
    for the DF Robot RS485 Temperature, Humidity, EC Sensor
    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
2026-10-28 Expanded documentation, new builtin pumping schedule (#18)
    - Adds dynamic schedule to plants case study
    - Updates docs
    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
